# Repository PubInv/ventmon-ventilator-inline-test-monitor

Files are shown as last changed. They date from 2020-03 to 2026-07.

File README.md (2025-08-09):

# VentMon T0.5
The VentMon is an OSHWA certified open source hardware, [US002353](https://certification.oshwa.org/us002353.html)

OSHWA_VENTMON

# VentMon T0.5



Note: The previous version, the VentMon T0.3, has been published in [HardwareX](https://www.sciencedirect.com/science/article/pii/S2468067221000249) with extensive build instructions.



The VentMon T0.5 was roughly designed in June of 2021. This version is self-contained---that is, it will not require a separate computer and internet access.
The inventor team has been especially motivated by the work of Mr. Joe Leier, who repaired ventilators in Guatemala during the pandemic.  Public Invention aims to create a self-contained unit that allows the user to test and repair it in the field.  The device will, however, still be WiFi enabled, and still publish data to a the public data lake.

For now, our ideas and work are published in the directory called [pi](https://github.com/PubInv/ventmon-ventilator-inline-test-monitor/tree/master/pi).

## Configuring the VentMon T0.5 for WiFi

The VentMon is fundamentally a WiFi enabled device which publishes to a public data lake which can be found here:

[\http://ventmon.coslabs.com/rds](http://ventmon.coslabs.com/rds)

In order to configure it, the password and name of the local WiFi networkmust be added via the serial port. To do this, you have to connect to the serial port on the VenMon with a USB cable with a serial monitor. the Arduino IDE has such a serial monitor, but you could use any serial monitor. Then 
simply type the letter "c" and enter to configure the VentMon. Read and follow the instructions to reset and enable or disable the WiFi network.

The Configuration menu may look like this:
```
16:00:17.486 -> Enter 'c' to re-enter this configuration while running.
16:00:17.486 -> WiFi ENABLED
16:00:17.486 -> Enter 'w' to enable WiFi, 'x' to disable WiFi
16:00:17.486 -> Ethernet ENABLED
16:00:17.486 -> Enter 'e' to enable Ethernet, 'f' to disable Ethernet.
16:00:17.486 -> Type the character 'r' to reset wifi ssid and password.
16:00:17.486 -> Type the character 'c' to continue or wait 10 seconds to begin/resume operation:
```

Once you have condifugred it for your local WiFi and verified that you are seeing love traces at the URL above (your trace will likely be near the top, and reflects your loack IP address) then you can power the VentMon which a USB cable which is not monitored by a computer.

# Previous Version VentMon T0.4 - Inline Ventilator Test Fixture and Monitor

March 9th, 2021

VentMonT0 4

The photo above shows the current version of the VentMon, the T0.4 tester/monitor, designed and manufactured by Ben Coombs. We are giving these away free of charge to worthy open source teams.

The VentMon T0.4 improves on the T0.3 because it is self-contained (no cables) and is quite compact. We have also improved the OLED display, although additional firmware changes are coming soon.

The software infrastructure that supports the VentMon, such as [VentDisplay](https://github.com/PubInv/vent-display) and [PIRDS](https://github.com/PubInv/PIRDS-respiration-data-standard), have improved as well.

The VentMon is basically a cloud-enabled spirometer with an FiO2 sensor. When plugged into a standard 22mm airway, the device provides
a rich stream of pressure and flow, with oxygen, humidity, and temperature sensors for continual monitoring.  Engineering teams developing pandemic response ventilators and other respiration tools are the primary users of the VentMon. Additionally, it is completely and transparently open source, so any team can adopt the design and incorporate it into their own devices to provide the same data in an integrated way.

The parts in a VentMon cost about USD$600. 

# Usage

## Basics

The VentMon T0.4 can be powered with any micro-USB cable. It has an RJ45 ethernet port, and supports WiFi.  It has a male airway connector and 
a female airway connector in the international standard 22mm adult airway sizes. It comes with an oxygen sensor, which you may have to install
by opening the case. It is not pre-installed because the oxygen sensors have a limited shelf life and some users don't need one. The case can 
be opened with a small jeweler's Phillips head screwdriver.

The VentMon has a small OLED display which gives some startup information and also shows momentary flow and pressure while producing a tiny 
graph of airway pressure. This is not intended for clinical use, but it is useful for letting you know that the device is on and working.

## The Serial Port

The main target for the VentMon project is to support engineers who are working on ventilators and respiration support devices. Most of these engineers will know
how to use the Arudino IDE to see the serial port. The baudrate is 500000 (500,000).
A simple human-readable output is printed to the serial port at start up time, which
shows some basic start up information.  After searching for an ethernet connection and WiFi connection, the VentMon will
begin printing dynamic data on the serial port. 
The output is in the [PIRDS data format](https://github.com/PubInv/PIRDS-respiration-data-standard). 
This is useful for verifying that the device is functionally and correctly working.
It is not a good way to analyze data, but you can tell a lot by reviewing this data stream.  However, the preferred way to look at moving interactive waveforms and clinical paramaters is with [VentDisplay](https://github.com/PubInv/vent-display), which requires some configuration.

## Configuring a UDP conncetion

The easiest way to use VentDisplay is to check out our public IoT Data Lake at [http://ventmon.coslabs.com/](http://ventmon.coslabs.com/). 
We name your log file by your IP address. The webpage there looks like this:

These files are sorted by modification timestamp, so if you use one of the methods to place your data there, it will likely be near the top!
The "BreathPlot" links take you to the VentDisplay for that log file, whether it is is static or "live" (that is, being dynamically added to from a
running VentMon.)

By entering a "c" character followed by a newline (probably in the Arduino IDE serial monitor tool), the VentMon will stop sending data 
to the serial port and write out a small menu of instructions. You can follow these instructions to enable or disable either the ethernet
connection, the WiFi connection, or both.  This menu allows you to enter your SSID for your WiFi network and your password, which will be
stored in the EEPROM of the device.

If you choose to use the Ethernet connection, you will probably plug an ethernet CAT5 cable directly into your router and the port on the VentMon.

Both Ethernet and WiFi attempt to send UDP packets to port 6111 at ventmon.coslabs.com.  There our [PIRDS-logger](https://github.com/PubInv/PIRDS-logger)
connection automatically timestamps and logs your UDP packets, and allows them to render for your viewing and analysis pleasure.

## Configuration

Configuring a VentMon T0.4 is a little complicated because we are developing a modular, composable, respiratory ecosystem. The diagrams below try to capture three distinct approaches: using our public data lake (easiest), using Apache (requires understanding httpd.conf and fully understanding all pieces), and a Docker Image (we have not actually created this, but we plan to).

Public Data Lake:

VentMon Cloud Ecosystem

Using Apache:

VentMon Apache Ecosystem

Public Invention recently created a repo that builds a Docker file image that makes all of this possible locally without running Apache/CGI.
Please visit [PIRDS-docker-local](https://github.com/PubInv/PIRDS-docker-local) for more details. As of March 25th, the Docker system is working 
on one computer (the authors), and another user has reported a problem with it; this is in an early release stage.

VentMon Docker Ecosystem

## Compiling and updating the Firmware

If you have received a VentMon from us,
it will have VentMonFirmware.ino installed.
The VentMon firmware is a work in progress, and we are making active improvements.
Therefore, you may want to update it from time to time. This requires you to build it with the Arduino IDE on your system.
You are welcome to modify the VentMonFirmware.ino file as needed. To do so, you will
have to install a library of our creation which encpasulates the PIRDS standard.
Copy the libary [pirds_library](https://github.com/PubInv/PIRDS-respiration-data-standard/tree/master/pirds_library) into your Arduino library location. You may need to install the Adafruit BME680 library
and other libraries as well.

Additionally, to compile the version of the firmware, you will need to install the [SFM3X00 library](https://github.com/PubInv/SFM3X00). We wrote this library to encapsulate Sensirion flow sensors of various kinds.

This process is a little clunky; please contact us if you need help with that.

# VentMon 0.3

Note: The important file "breath_plot.html" which renders respiration traces and calculated values from PIRDS 
data was moved to its own [repo](https://github.com/PubInv/vent-display) on Thursday, June 18, 2020.

Since March 16th, I've been working full time on this. Along with volunteers at [EndCornaVirus.org](https://www.endcoronavirus.org/) and [Public Invention](https:\\www.pubinv.org), we have been
[tracking and analyzing](https://github.com/PubInv/covid19-vent-list)
all [open-source ventilator projects]((https://medium.com/@RobertLeeRead/analysis-of-open-source-covid-19-pandemic-ventilator-projects-27acf9075f7e)) we can find. It has become apparent that the biggest piece
they are missing, and the area where Public Invention can most help, is not in designing a new ventilator. Instead, our priority is to build a test/monitoring fixture to assist other teams.

Monitoring and testing are critical for keeping patients alive, and thus we are attempting to
make a combined tester/monitor.

At the moment, this repo is to that end. Our overall strategic plan will give clinicians
enough confidence to actually deploy an open-source ventilator. Our goal is to certify ventilators in a limited, last-resort
sense, in case of a shortfall of commercial and professional equipment. That strategy is discussed later in this document.

Our current process includes rapid high-quality, but also burn-in and multi-day, testing of
ventilators. Perhaps we can produce a benchmark for the [multiple efforts](https://github.com/PubInv/covid19-vent-list) going on right now to develop a
Free-libre Open Source ventilator design.

For further explanation of Public Invetion's design motivation and approach for this project, please refer to the following document -
[Motivation of Strategy](https://github.com/PubInv/ventmon-ventilator-inline-test-monitor/blob/master/Motivation.md)

For a hands on demonstration and in-depth explanation of VentMon, watch our screen cast!  
[VentMon ScreenCast](https://www.youtube.com/watch?v=OV9MrMjVOCI)

# User Manual

Although a work in progress, we have a [user manaul v0.3T](https://github.com/PubInv/ventmon-ventilator-inline-test-monitor/blob/master/doc/UserManaul.md).
This User Manual is basically for the VentMon.

## Design and Dependencies

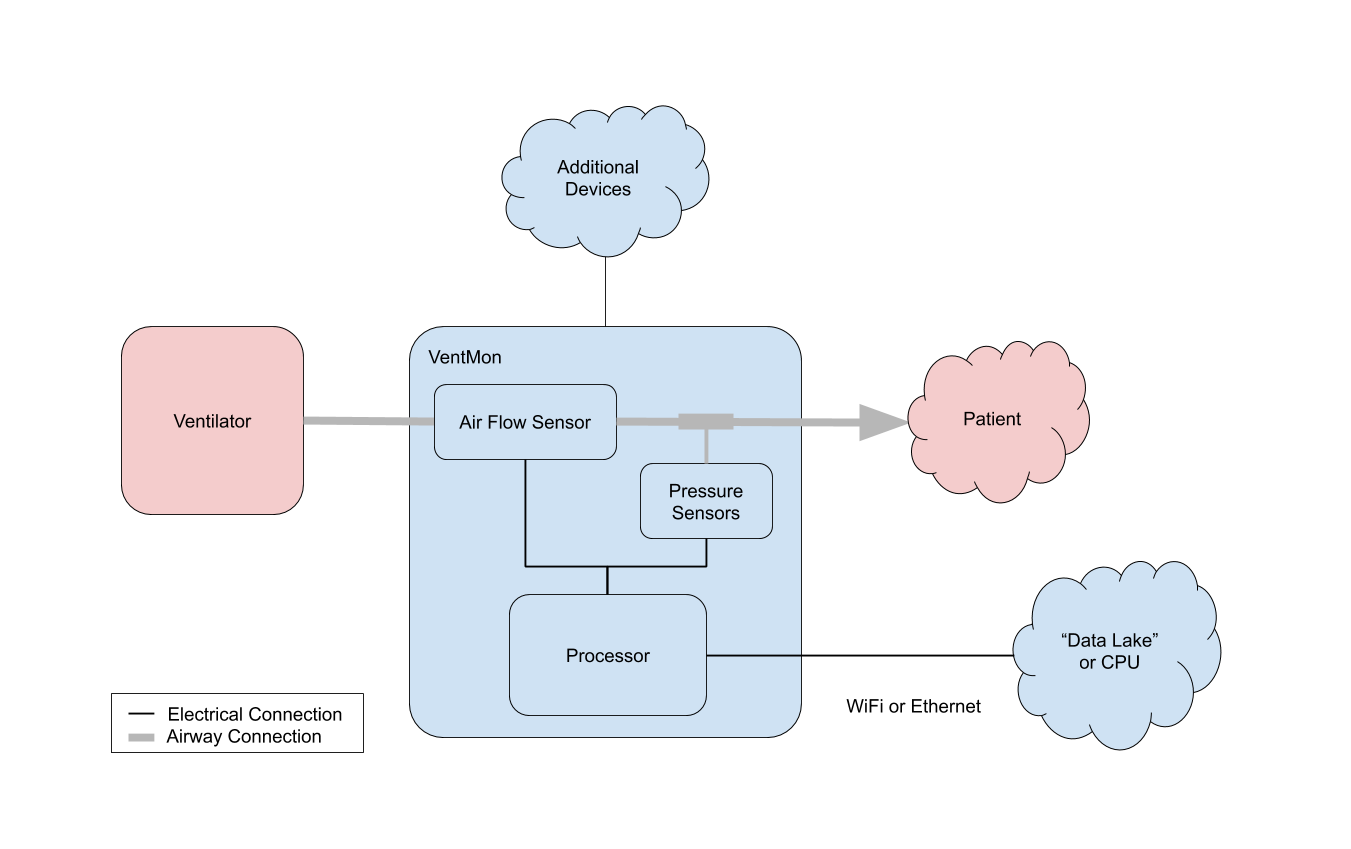
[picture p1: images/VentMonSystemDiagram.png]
SystemDiagram


This project aims to design a standalone inline device plugged into the airway. It will serve the dual purpose of both monitor and alarm when used on an actual patient, and these tests may also produce prototype ventilators that allow for burns.

VentMon depends on the following Arduino library for communication with Sensirion flow sensors: [SFM3X00](https://github.com/PubInv/SFM3x00)

Assembly instructions can be found here: [Assembly Instructions](https://docs.google.com/document/d/1n-Ja3UgbrCLcY8kx9rmTZB7b3yNJ_DnjpA1hwfMbgXk/edit#)

Initial BOM can be found here: [BOM](https://docs.google.com/document/d/1n-Ja3UgbrCLcY8kx9rmTZB7b3yNJ_DnjpA1hwfMbgXk/edit#)

## Status

** October 10th **

We have now shipped 20 units of the VentMons to open source teams all over the world. Some of them are
using them successfully. We ordered 15 printed circuit boards and 15 3D printed sensor ports, and I built them
by hand. There was an error in the PCBs which is now corrected; I fixed the current them by 
soldering a wire in place. The current design of the case does not perform cable management as well as it should; 
the flow meter cable tends to fall out. We will improve this in future designs.

** August 20th **

We have received 15 populated boards and desigend a 3D printed hat. We are beginning final assembly/manufacture of the 15 units that people have requested to be sent out free-of-charge.

** June 18th ***

Lauria plans to ship 5 more VentMons on the 23rd. She has added FiO2 sensing and important features. Rob Giseburt has create a VentMon-like device using a Raspberry PI; we may switch to that display. The VentMon was used internationally by several teams to gain important insights into their prototype pandemic ventilators. One team may be constructiong their own VentMon from our Open Source designs.

** May 25th **

We have now shipped 4 VentMons. Most recent modifications involved using the "pirds_library" more universally.

** May 7th **

We sent the first VentMon to Artemio Mendoza of the 1MillionVents team, and he made this great video:

VentMon testing an A.R.M.E.E. Device (https://youtu.be/nViBK8d_pbM)

**May 4th:**

May the Fourth be with you.

We have shipped two VentMons free of charge to an open source ventilators' team that will use them for volume and flow measurements.

A [user manaul](https://github.com/PubInv/ventmon-ventilator-inline-test-monitor/blob/master/doc/UserManaul.md) is progressing.

**April 27th:**

Assembly instructions can be found here: [Assembly Instructions](https://docs.google.com/document/d/1n-Ja3UgbrCLcY8kx9rmTZB7b3yNJ_DnjpA1hwfMbgXk/edit#)

**April 21st:**

Initial prototype is fully assembled!

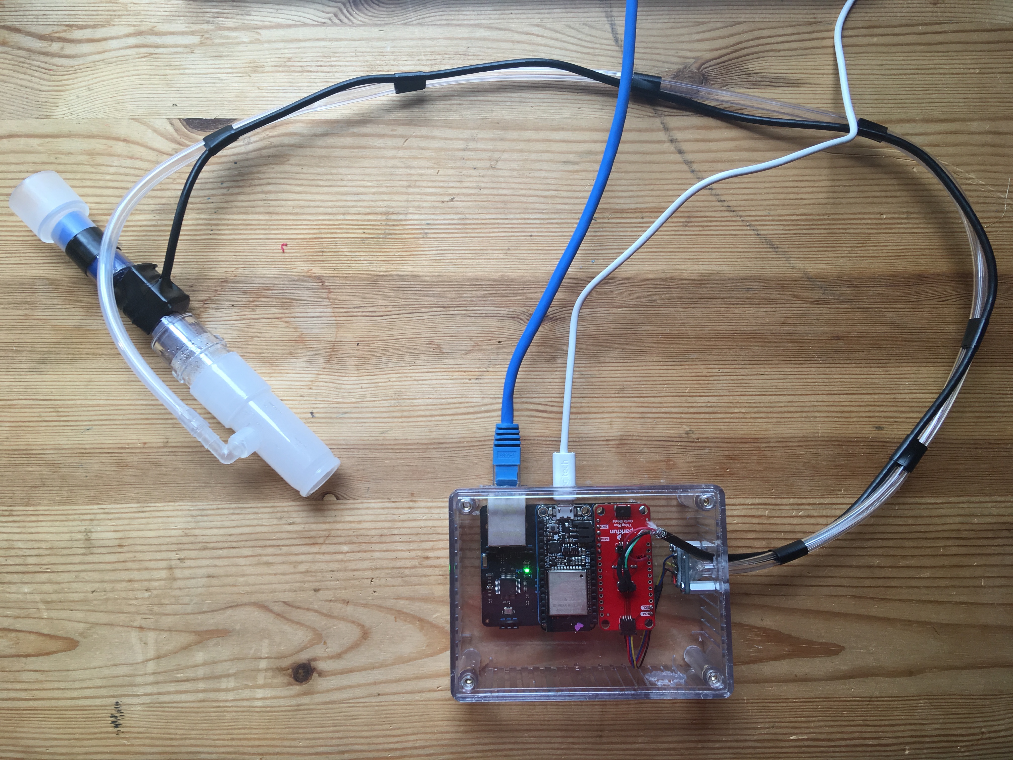
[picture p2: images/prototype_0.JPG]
Prototype


**April 20th:**

1) Have a working ESP32 board with pressure sensors and Sensirion flow sensors.
2) This code outputs a stream of PIRDS respiratory standard events on the serial port.
3) These are read by data_server.py which presents a web server for retrieving this data.
4) test_tools/breath_plot.html makes AJAX calls to this server and renders the results dynamically.

## Volunteering

This project is co-led by Robert L. Read <read.robert@gmail.com> and Geoff Mulligan.

Right now we have several needs. People need experience, to have read the [essential reading](https://github.com/PubInv/covid19-vent-list) list, and to have
least 20 hours a week to work with limited supervision.  They must also have the ability to tolerate the chaos
produced by the pandemic and my own mistakes. Finally, they must accept and
hope that the industry will increase ventilation production, and that the disease will be controlled so that this
solution is no longer required.

Right now, we could use:
1. An experienced Arduino engineer to build and improve the design below
1. A JavaScript programmer to add the ability to scroll-through all time to [https://github.com/PubInv/vent-diplay](vent-display) code.
1. Someone to design the User Interface of the "monitor and alarm" feature. They would have to be or become familiar with existing ventilators make a similar interface. This will likely become a small LCD or OLED text screen, 4 physical buttons, and a small speaker or buzzer.

# Request for Donations to Public Invention

[Public Invention](https://www.pubinv.org/) is a small, all-volunteer 501(c)3 US public charity. Your [small donation](https://www.pubinv.org/donate/) is a stamp of approval for our work and will really help us.

# Licensing

All code in this repo is licensed under the GPL License. All documents and diagrams are licensed under CC0. All hardware is licensed under the [CERN Open Hardware Licences Version 2 - Strongly Reciprocal](https://ohwr.org/cern_ohl_s_v2.pdf).

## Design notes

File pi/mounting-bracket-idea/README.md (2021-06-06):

# Mounting Bracket ID

The VentMon T0.4 case is just a little too large to mount behind the Element 14
Raspberry PI 7" TFT screen. However, that screen, and many others, has a
VESA-D 75mm mount on the back. I propose that we make a flat bracket that
mounts to this with the standard M4 screws, with a projection large enough
for us to zip-tie a VentMon T0.4 to it.

We may change the case for the T0.5; but in any case this system allows
the VentMon device to be easily separated from the Touch screen.

Our goal is to produce a maximally modular system; if you can use
a VentMon without the larger screen if you want.  If we were selling
devices (which we are not), the two components would be "sold separately".
Instead, they are "designed separately", and a manufacturer may make
and sell one or both.

The motivation of this is in particular to go to a hospital in LMIC
that might have broken ventilators and to be able to quickly assess,
test, and repair the ventilators (with the help of a plastic test lung,
not produced by us.)

Note: The mockup below is a WIP -- there may be better approaches. I'm publishing it here for comment.

## Basic Parts

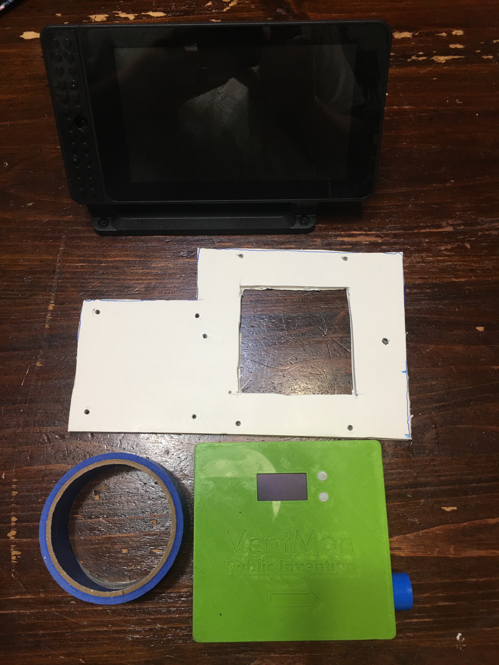
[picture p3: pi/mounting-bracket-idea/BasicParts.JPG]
Basic Parts


## Bracket as Bezel

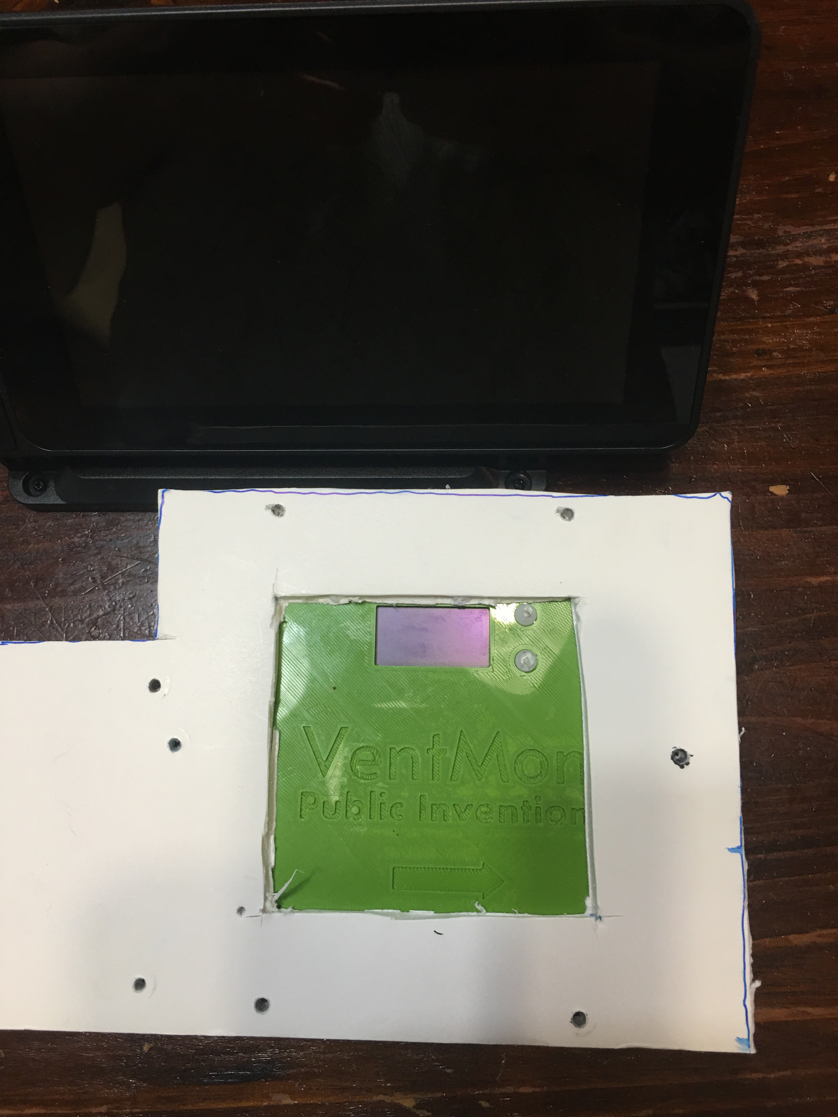
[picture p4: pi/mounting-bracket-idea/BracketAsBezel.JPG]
Bracket as Bezel


## Screen Rear (VESA Mis-D 75mm mount)

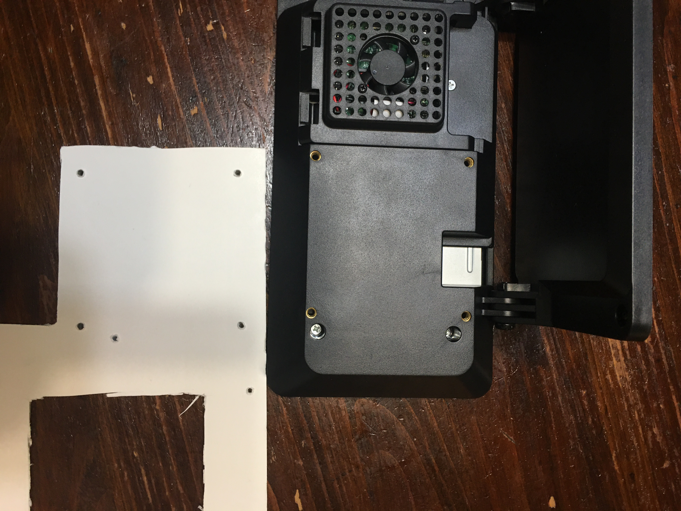
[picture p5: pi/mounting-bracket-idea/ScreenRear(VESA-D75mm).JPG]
Screen Rear VESA MIS-D 75mm Mount


## Final Configuration Mockup

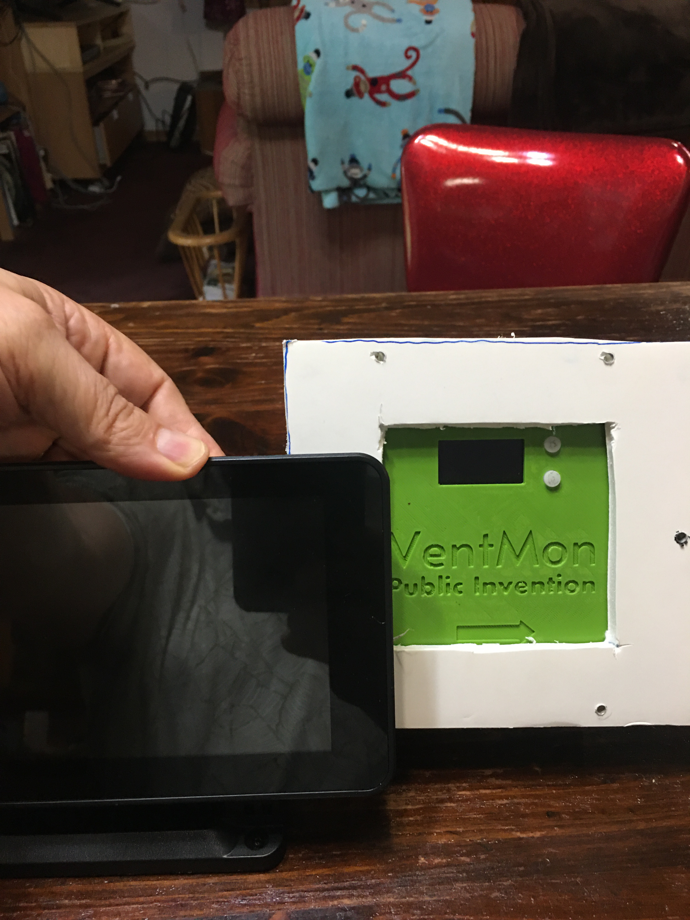
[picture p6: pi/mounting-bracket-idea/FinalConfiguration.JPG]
Final Configuration Mockup


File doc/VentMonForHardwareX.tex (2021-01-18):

% GENERAL INFORMATION: HardwareX is an open access journal established to promote free and open source designing, building and customizing of scientific infrastructure (hardware). For more details on best practices for sharing open hardware see http://www.oshwa.org/sharing-best-practices/

\documentclass[11pt, letterpaper]{article}
\usepackage[utf8]{inputenc}
\usepackage[margin=1in]{geometry}
\usepackage{titlesec}
\usepackage{tabu}
\usepackage{enumitem}
\usepackage{amssymb}
\usepackage{graphicx}
\usepackage{float}
\newlist{selectlist}{itemize}{2}
\setlist[selectlist]{label=$\square$,leftmargin=*,noitemsep,topsep=0pt}

\usepackage{hyperref}
\hypersetup{
    colorlinks=true,
    linkcolor=blue,
    filecolor=magenta,
    urlcolor=cyan,
}

\usepackage[backend=biber]{biblatex}
\addbibresource{VentMon.bib}

\urlstyle{same}

% Set up the section label formatting
\titleformat{\section}[block]{\hspace{1em}\bfseries}{\thesection.}{0.5em}{}
\titleformat{\subsection}[block]{\hspace{1em}}{\thesubsection}{0.5em}{}

\begin{document}
% Create the title block
\begin{flushleft}

% Remove all text in italics when filling out the template and replace with your manuscripts corresponding text in regular font.

\setlength{\parindent}{0pt}
\setlength{\parskip}{10pt}
% \textbf{\large HardwareX article template}

%Insert title
%Max. 20 words. A good title should contain the fewest possible words that adequately describe the content of a paper.
\textbf{Title:} VentMon: An Open Source Inline Ventilator Tester and Monitor

%Insert Authors
\textbf{Authors:} Robert L. Read, Lauria Clarke, Geoff Mulligan

%Insert Affiliations
\textbf{Affiliations:} Public Invention with support from the \textit{Protocol Labs} and the \textit{Mozilla Foundation}

%Insert Contact Email
%Include institutional email address of the corresponding author
\textbf{Contact email:} read.robert@gmail.com

%Insert Abstract
%Max. 200 words. Remember that the abstract is what readers see first in electronic abstracting and indexing services. This is the advertisement of your article. Make it interesting, and easy to be understood. Be accurate and specific, keep it as brief as possible.
\textbf{Abstract:}

Humanitarian engineers responded to the pandemic ventilator shortage of March, 2020
by beginning over 100 open source ventilator projects\cite{COVID19VENTLIST,pearce2020review}.
By {\em ventilator}, we mean both an invasive ventilator (requiring intubation of the patient) and non-invasive ventilator (generally supporting spontaneously breathing).
Inexpensive ventilator test equipment can facilitate projects forced to be geographically distributed by lockdowns.
The VentMon is a modular, open source, IoT-enabled tester that plugs into a standard 22mm airway between a ventilator and a physical test lung to test any ventilator.
The VentMon measures flow, pressure, fractional oxygen, humidity, and temperature.
Data is stored and graphed at a data lake accessible to all devlopment team members, and, eventually, clinicians.
The open source design of the VentMon,
its firmware, and cloud-based software may allow it to be used as a component of modular ventilators to provide a clinical readout.
The software system surrounding VentMon has been designed to be as modular and composable as possible.
By combining new, openly published standards for data with composable and modifiable hardware,
the VentMon forms the beginning of an open system or eco-system of ventilation devices and data.
Thanks to grants, 20 VentMons have been given away free of charge to pandemic response teams building open source ventilators.

%Insert Keywords
% At least 3 keywords. There is no limit on the no. of keywords you can list. Please remember that effective keywords should not repeat words appearing in your title, and should be neither too general nor too narrow.
\textbf{Keywords:} COVID-19, open source medical device, ventilator, pandemic response, IoT, respiration waveform

\newpage
\textbf{Specifications table:}

\tabulinesep=1ex
\begin{tabu} to \linewidth {|X|X[3,l]|}
\hline  \textbf{Hardware name} &
  %Please specify the name of the hardware that you invented / customized
  VentMon
  \\
  \hline \textbf{Subject area} & %
  % Please state the subject area most relevant to the original community for which this hardware was developed. Example subject areas are listed below
 Educational Tools and Open Source Alternatives to Existing Infrastructure
  \\
  \hline \textbf{Hardware type} &
Field measurements and sensors,
Electrical engineering and computer science
  \\
\hline \textbf{Open source license} &
  %Please specify the open source license. For more details see the guide to authors.
 MIT License, CERN-OHL-S
  \\
\hline \textbf{Cost of hardware} &
  %Approximate cost of hardware (complete breakdown will be included in the Bill of Materials).
\$280
  \\
  \hline \textbf{Source file repository} &

  VentMon: \linebreak
  \href{https://doi.org/10.5281/zenodo.4079170}{https://doi.org/10.5281/zenodo.4079170}
  \linebreak
  PIRDS (Public Invention Respiration Data Standard): \linebreak
  \href{http://doi.org/10.5281/zenodo.4079377}{http://doi.org/10.5281/zenodo.4079377}
  \linebreak
  PIRDS logger: \linebreak
  \href{Zenodo. http://doi.org/10.5281/zenodo.4079382}{Zenodo. http://doi.org/10.5281/zenodo.4079382}
  \linebreak
  SFM3X00: \linebreak
  \href{http://doi.org/10.5281/zenodo.4079355}{http://doi.org/10.5281/zenodo.4079355} \linebreak
  VentDisplay: \linebreak
  \href{http://doi.org/10.5281/zenodo.4079374}{http://doi.org/10.5281/zenodo.4079374} \linebreak
  \linebreak

  % Link to the source file repository
      % insert a DOI URL to an approved source file repository:  Mendeley Data, theOSF, or Zenodo (instructions).  For example: "https://doi.org/10.5281/zenodo.3346799"
      % If there is no external repository write “Available in the article”
  %% \textit{DOI URL to an approved source file repository:  \href{https://data.mendeley.com/}{Mendeley Data}, the \href{http://osf.io}{OSF}, or \href{https://zenodo.org/}{Zenodo} \href{https://doi.org/10.5281/zenodo.3346799}{(instructions)}. For example:} \textit{https://doi.org/10.5281/zenodo.3346799}
%  \linebreak
%  \linebreak
\\\hline
\end{tabu}
\end{flushleft}
% create the main body of the paper

\section{Hardware in context}
% Include a short description of the hardware, putting into context of similar open hardware and proprietary equipment in the field.
The Coronavirus pandemic has created a potential global shortage of ventilators\cite{pearce2020review}, which has abated in the wealthy nations.
Ventilators are expensive to manufacture and during uncertain times supply chains can be disrupted, increasing the cost and scarcity of these devices. Since the beginning of the pandemic in March,
there has been a large movement to develop cheaper,
more supply chain-resilient ventilators.
The urgency and goals of this movement have shifted as the global understanding of the virus has evolved. Regardless of the current state of this movement, however, the use of
open source medical devices in resource-limited emergency situations---common during a global pandemic---is a topic that has come to the forefront of may conversations about preparedness and treatment.
Medical devices require rigorous testing before they can be used on the general public.
Open source medical devices require the same level, if not more, scrutiny and documentation. If an open source movement is to succeed in this field, the tools to test and validate medical
devices must be accessible.
The goal of VentMon is to provide an equally open source, community based verification solution to increase the efficiency and accuracy of the development process for socially distanced,
potentially international teams making open source ventilator, Bilevel Positive Airway Pressure (BPAP), and Powered Air-Purifying Respirator (PAPR) devices.

Although it is beyond the scope of this paper to review or even comment on ventilation projects, a number of pandemic response ventilators have been reported on recently which seem to be candidates to benefit from the VentMon, if only because of its flow-sensing and oxygen sensing capabilities (most have pressure sensors in place) \cite{lai2020emergency,petsiuk2020partially,garmendia2020low,zuckerberg2020lung,galbiati2020mechanical}. Although most published reports include bench-top testing, this may have been done with an instrumented test lung which is not continuously available to the development teams as a VentMon might be. Additionally, most of the teams mentioned in a report on open source teams\cite{Fraunhofer2020} could make use of a VentMon.

\section{Hardware description}
% Describe the hardware, highlighting the customization rather than the steps of the procedure. Highlight how it differs/which advantage it offers over pre-existing methods. For example, how could this hardware: be compared to other hardware in terms of cost or ease of use, be used in the development of further designs in a particular area, and so on.

% > Add 3-5 bulleted points to broadly explain to other researchers how the hardware could be potentially useful to them, for either standard or novel laboratory tasks, inside or outside of the original user community.

The VentMon plugs directly into a standard 22mm adult airway. As air or medical gases pass through the VentMon, it records flow and pressure, temperature, humidity, and fractional O$_2$ at rates of 25 Hz to once per minute, depending on the measurement. When placed in the breathing circuit between a ventilator under test and a physical test lung as shown in Figure \ref{fig:vtestusage}, this data is sent to a public data lake \cite{VentDisplay} using a clearly defined respiration standard \cite{PIRDS}. This data can be graphically rendered either live or statically to provide a display that is typical of the clinical display of advanced ventilators as shown in Figures \ref{fig:vtestusage} and \ref{fig:ventdisplay}. This functionality is similar to that of commercially available instrumented test lung devices, which tend to start at USD\$10,000.

Teams building open pandemic ventilators tend to be poorly funded and geographically distributed. VentMon's connectivity and overall cost address these two challenges by enabling team members on different continents to view waveforms (see Figure  \ref{fig:ventdisplay}) in real time and communicate the necessary adjustments to the ventilator device under test. While reliance on the internet is a strength for a distributed and virtually connected engineering team, it would be an addressable disadvantage in a field hospital.

Being completely open, VentMon supports modification, extension, and has potential for integration into a complete ventilator. A team working to build a ventilator device with a graphical trace of pressure and flow---generally demanded by clinicians for all but emergency transport situations---could incorporate the open source VentMon into its complete design. VentMon has potential to be safe enough and reliable to be used as a monitor on human patients, however it requires much improvement before it is ready for that use.
\\

The VentMon thus offers the following benefits to teams developing ventilation devices. It:
\begin{itemize}
\item is inexpensive,
\item is completely open source and part of a modular hardware/software system that can be customized and extended,
\item allows remote collaboration, and
\item currently provides many of the clinically significant metrics found in commercially available ventilators.
\end{itemize}

\section{Design files}
% The  complete  design  files  must  be  either  uploaded  to  an  approved  online  repository,  uploaded  at the  time  of  submission  on  the  online  Editorial  Manager  submission  interface  as  supplementary materials [CAD files, videos,. . . ], or included in the body of the manuscript [e.g.  figures].  The three approved  online  repositories  are  Mendeley  Data,  the  Open  Science  Framework,  and  Zenodo. See repository instructions: https://doi.org/10.5281/zenodo.3346799

\subsection{Design Files Summary}
% Please include a summary of all design files for your hardware by filling rows of the table below

\tabulinesep=1ex
\begin{tabu} to \linewidth {|X[1.5]|X|X[1.5,1]|X[3]|}
\hline
\textbf{Design filename} & \textbf{File type} & \textbf{Open source license} & \textbf{Location of the file} \\\hline
%Insert design files
(1) Embedded Firmware (v0.3 PCB version) & C++ Source Code & MIT License &  \href{https://doi.org/10.5281/zenodo.4079170}{10.5281/zenodo.4079170}\\\hline
(2) Embedded Firmware (v0.2 COTS version) & C++ Source Code & MIT License &  \href{https://doi.org/10.5281/zenodo.4291147}{10.5281/zenodo.4291147}\\\hline
(3) VentDisplay PIRDS Data Viewer  & HTML Source Code &  MIT License &  \href{http://doi.org/10.5281/zenodo.4079355}{10.5281/zenodo.4079374} \\\hline
(4) PIRDS Data Logger & C Source Files & MIT License & \href{https://doi.org/10.5281/zenodo.4079382}{10.5281/zenodo.4079382} \\\hline
(5) PIRDS Data Standard & Documented standard, and C-language binding & Creative Commons Zero (Universal) for documents, GPL 3.0 for code binding &
\href{http://doi.org/10.5281/zenodo.4079355}{10.5281/zenodo.4079355} \\\hline
(6) VentMon v0.3T PCB & PCB Design Files & MIT License &  \href{https://doi.org/10.5281/zenodo.4079170}{10.5281/zenodo.4079170} (see {\em design/pcb}) \\\hline
(7) Pressure Sensor and Airway Adaptor & STL File & MIT License &  \href{https://doi.org/10.5281/zenodo.4079170}{10.5281/zenodo.4079170} (see {\em design/3dparts}) \\\hline

% Design file 3 & File type & License & Link \\\hline

\end{tabu}
\vspace{0.5cm}

We promote an open, modular, and composable respiration ecosystem. Therefore, we have more separate repositories and modules than would strictly be needed if we were only making the VentMon project. Our hope is that smaller modules may be reusable by others who do not need the VentMon specifically, but may have need for a particular component.

\begin{enumerate}
\item The main firmware is written in the Arduino environment. The firmware targets an ESP32, but could easily apply to other boards. This core firmware manages reading the various sensors, and outputs its data both on its small built-in OLED (used for functional testing), and via the PIRDS standard to a public data lake where a separate module renders it in a graphical display appropriate for a clinician.
\item Our current focus is on a printed circuit board version of the VentMon\cite{ventmonpcb}. However, we also report here a system that can be made by an amateur using only commercial off-the-shelf (COTS) parts---version T0.2. Software that matches this version it is tagged as such.
\item VentMon has a tiny OLED screen which is used to graph pressure for quick ``smoke'' testing. For serious performance testing and eventual clinical use, we use VentDisplay, a browser-delivered JavaScript code that presents a full clinical display.
\item The VentDisplay software can be pointed at any data logger that serves up data in the PIRDS format. This logger takes data from UDP packets and writes them to a file, which can then be served up by a webserver to any requester.
\item Integral to the VentDisplay and PIRDS Data Logger is the Public Invention Respiration Data Standard (PIRDS). This is a documented standard.
\item The VentMon v0.3T printed circuit board is designed with EAGLE CAD.
\item A small 3D printed housing epoxied over the ambient air quality sensor with a tiny pressure port allows us to share the air with the main pressure hose.
\end{enumerate}

% For each design file listed in the summary above, include a short description of the file below (one or two sentences)

\section{Bill of materials}

% For a complex Bill of Materials, the complete Bill of Materials (editable spreadsheet file e.g., ODS file type or PDF file) can be uploaded in an open access online location such as the Open Science Frameworks repository. Include the link here. Alternatively, the Bill of Materials can be uploaded at the time of submission on the online Elsevier submission interface as supplementary material.

% > To make it easy to tell which item in the Bill of Materials corresponds to which component in your design file(s), use matching designators in both places, or otherwise explain the correspondence.

% > For material type, select from: Metal, semi-conductor, ceramic, polymer, biomaterial, organic, inorganic, composite, nanomaterial, semiconductor, non-specific, or other

The Bill of Materials specifies the parts needed to build the VentMon in a simple enclosure with drilled-out ports for cables.
The parts are typical of hobby electronics.

\tabulinesep=1ex
\begin{tabu} to \linewidth {|X[0.5]|X[3]|X[0.5]|X|X|X|X[3]|}
  \hline
\textbf{ Designator} &	\textbf{Component} & \textbf{Number} & \textbf{Cost/Unit} & \textbf{Total Cost}& \textbf{Source} & \textbf{Material Type} \\\hline
U1 &	PARTICLE ETHERNET FEATHERWING &	1 &	\$20.11 &	\$20.11  &	Adafruit &	Semiconductor/Other \\\hline
U2 &	HUZZAH32 ESP32 FEATHER MALE HDR	& 1 &	\$21.95	& \$21.95 &	Adafruit&	Semiconductor/Other \\\hline
U3 &	SPARKFUN QWIIC SHIELD FOR THING	& 1 &	\$3.50	& \$3.50 &	Digikey	& Semiconductor/Other \\\hline
U4 &	ADS1115 16 Bit ADC &	1&	\$14.95	& \$14.95 &	Adafruit	& Semiconductor/Other \\\hline
U5 &	OLED Feather Wing &	1&	\$14.95	& \$14.95 &	Adafruit &	Semiconductor/Other \\\hline
C1, C2 &	QWIIC CABLE - 200MM &	2 &	\$1.56 &	\$3.12 &	Digikey	& Metal/Plastic \\\hline
C3 &	USB Cable &	1 &	\$1.80 &	\$1.80	& Digikey &	Metal/Plastic \\\hline
C4 &	Oxygen Sensor Cable &	1 &	\$4.00 &	\$4.00 &	Oxycheq &	Metal/Plastic \\\hline
H1 &	M2.5 Screws &	12 &	\$0.38	& \$4.56 &	Digikey	& Metal \\\hline
H2 &	M2.5 Standoffs - Female, Female	& 6 &	\$0.45 &	\$2.70	& Digikey &	Metal \\\hline
OS1 &	R-17S Oxygen Sensor &	1 &	\$80.00 &	\$80.00	 & Oxycheq &	Metal/Plastic \\\hline
FS1 &	\textbf{Flow Sensor} &	1 & \textbf{see note below}	&	\$0.00	& &	Metal/Plastic \\\hline
PS1, PS2 &	BME680 SENSOR EVAL BOARD &	2 &	\$22.50 &	\$45.00	& Adafruit &	Semiconductor/Other \\\hline
P1 &	Processor Enclosure &	1 &	\$9.95 &	\$9.95 &	Digikey	 & Plastic \\\hline
P2 &	Bleed Adaptor	& 1 &	\$5.50 &	\$5.50 &	Oxygen Supply	& Plastic \\\hline
P3 &	Oxygen Sensor T	& 1 &	\$9.00 &	\$9.00	& Oxycheq &	Plastic \\\hline
P4 &	15 mm OD to 22 mm OD adaptor &	1 &	\$0.54 & 	\$0.54	& &	Plastic \\\hline
P5 &	15 mm ID to 22 mm OD adaptor &	1 &	\$0.35 & 	\$0.35	& &	Plastic \\\hline
T1 &	Oxygen Tubing &	1 &	\$2.25	& \$2.25 &	Oxygen Supply	& Plastic \\\hline
\end{tabu}

Note: The flow sensor is one of the most expensive and critical parts. Throughout mid-2020 there was a global shortage of flow sensors, including the four electrically compatible with the VentMon as currently designed. The Sensirion SFM3400-AW (\$180US) (a neonatal version with limited maximum flow sensing), SFM3200-33-D (disposable version \$40USD), Sensirion SFM3200-250 (\$145USD), and Sensirion SFM3200-AW (\$180USD autoclavable version). We shipped VentMons with all of these depending on availability. The VentMon is not currently designed for use with humans, but if it were, the autoclavable version would have the advantage of sanitizability if a complete sanitization procedure were designed. This is important, as we hope the VentMon will be modified and integrated into a rapidly manufactured ventilator, for which sanitization is critical.

The link below is to a spreadsheet which is includes the PCB-version, which is very similar except for the PCB itself. By following this link: \href{https://doi.org/10.5281/zenodo.4289426}{VentMon  BOM}, you can reach browsable URLs to most of the non-commodity parts. The specific BOM for the SMD parts needed to assemble the PCB can be found in our GitHub repo in the directory named {\em design/pcb}  along with the Eagle files: \cite{ventmonpcb}.

\section{Build instructions}
%Provide detailed, step by step instructions for the construction of the reported hardware include all necessary information for reproducing the submitted hardware.
% > Explain and, when possible, characterize design decisions. Including design alternatives if they exist.
% > Use visual instructions such as schematics, images, and videos.
% > Clearly reference design files and component parts described in the Design File Summary and Bill of Materials.
% >Highlight potential safety concerns that may arise

Two versions of VentMon can be assembled depending on availability of parts and time. The most physically robust and complete version of VentMon requires the purchase and manufacture of a PCB as well as a number of 3D printed plastic parts. This version of the device requires the least amount of time to assemble and contains fewest discrete components. The designs of the PCB and 3D printed parts are fully open. Due to the relatively high single-unit cost of PCB manufacture and assembly it makes most sense to use the PCB if you are building 10 or more VentMons. VentMon can also be created using off the shelf components readily available from DIY electronics suppliers. This version requires significantly more assembly time. We believe this has been done twice by third parties with little to no assistance from the VentMon team. Both assembly procedures are outlined below.

\subsection{COTS Based VentMon (v0.2T)}

{\em The VentMon v0.2T is not meant to be used on human patients. }
The COTS version uses firmware v0.2 tagged as such\cite{VentMon02}. This version is somewhat incompatible
with v0.3 (described below), which uses a PCB, and which is
the focus of our main development.

\begin{enumerate}

%-----------------------------------------------------------
% QWIIC SHIELD
\item
Qwiic Shield Assembly

See Figure \ref{fig:qwiic} on page \pageref{fig:qwiic} for final assembly of Qwiic Shield.

\begin{enumerate}[label=1.\arabic*]
\item
Trim two pieces of male header pins that are two positions long and one piece that is four positions long.
\item
With the connector side of the board facing up, solder one of the two position headers into the two holes labeled SDA and SCL.
\item
Solder the other two position header into the last two holes on the row along the opposite side.
\item
Solder the four position header into the last four holes along the right side. This should provide connections to the GND and 3V3 through holes.
\item
Connect both sides of the solder bridge to engage the pull-up resistors for the I\textsuperscript{2}C bus.
\end{enumerate}

\begin{figure}[H]
\centering
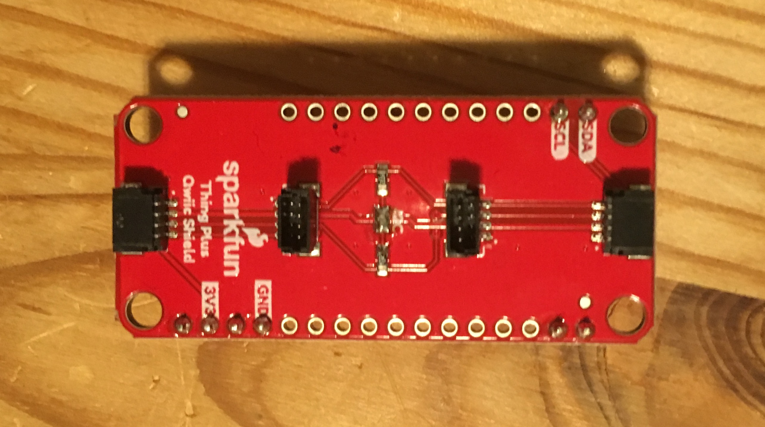
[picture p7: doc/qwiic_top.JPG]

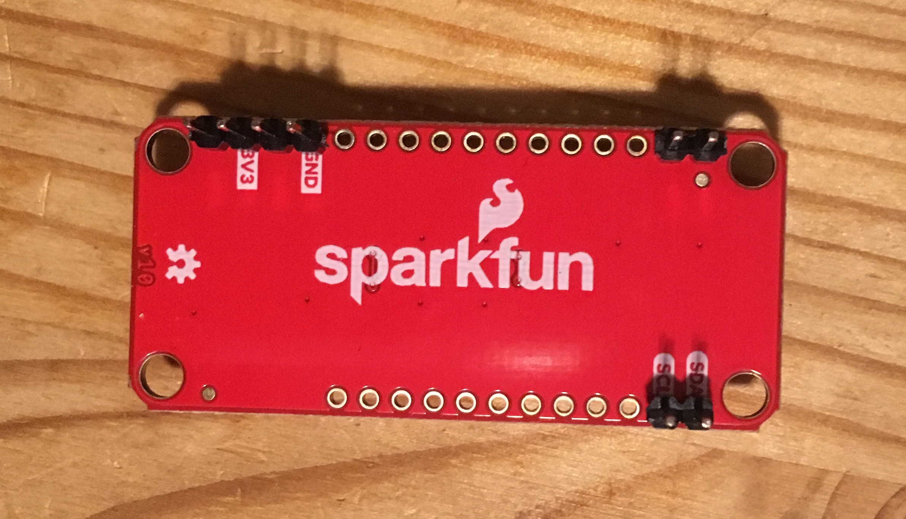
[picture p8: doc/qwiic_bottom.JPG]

\caption{SparkFun Qwiic Shield with male headers and I\textsuperscript{2}C pull-ups connected}
\label{fig:qwiic}
\end{figure}

%-----------------------------------------------------------
% ENCLOSURE
\item \label{itm:enclosure}
Enclosure

Before starting this step download and print the \href{https://github.com/PubInv/ventmon-ventilator-inline-test-monitor/blob/master/design/templates/bottomDrill03.pdf}{drill template}.

\begin{enumerate}[label=2.\arabic*]
\item
Cut out the template and tape it to the enclosure.
\item
Make sure the lid of the enclosure is firmly screwed on before drilling
\item
Drill holes in the locations denoted on template using the recommended drill sizes for each hole.
\end{enumerate}

%-----------------------------------------------------------
% PRESSURE SENSOR
\item
Pressure Sensor Assembly
\begin{enumerate}[label=3.\arabic*]
\item
Drill out mounting holes refer to figure \ref{fig:bme_1} on page \pageref{fig:bme_1}
\begin{enumerate}[label=3.1.\arabic*]
\item
Using the 7/64'' drill bit, carefully enlarge the mounting holes in each corner of the sensor
\item
You can do all four or just two - one on the left side of one board and one on the right side of the other
\end{enumerate}
\item
Cut trace from SDO through hole to sensor. Refer to figure \ref{fig:bme_1} on page \pageref{fig:bme_1}.
\begin{enumerate}[label=3.2.\arabic*]
\item
Carefully cut the trace coming from the SDO hole on the back side of one board
\item
This board will be used to measure the pressure in the breathing circuit
\end{enumerate}
\begin{figure}[H]
\label{fig:bme_1}
\centering
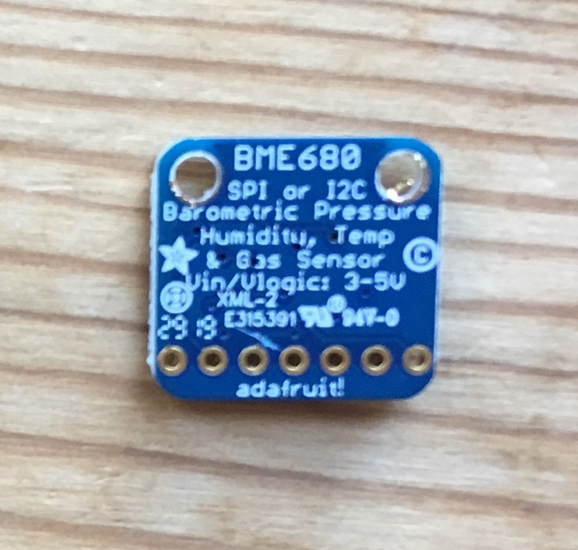
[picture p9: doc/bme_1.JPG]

\caption{BME 280 Eval board with drilled out holes and trace cut}
\end{figure}

\item
Assemble Cable. Refer to figure \ref{fig:bme_qwiic_cable} on page \pageref{fig:bme_qwiic_cable}.
\begin{enumerate}[label=3.3.\arabic*]
\item
Cut one connector off the Qwiic cable
\item
Strip and tin the last $1/4$" of the leads
\end{enumerate}
\begin{figure}[H]
\centering
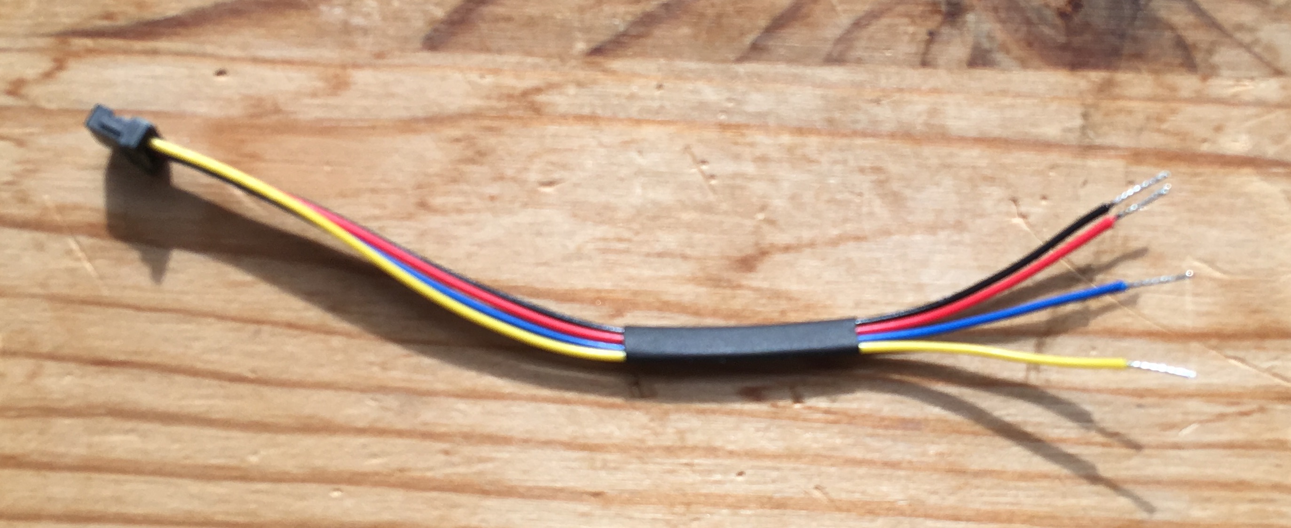
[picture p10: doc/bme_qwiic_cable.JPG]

\caption{Prepared Qwiic cable for BME sensor assembly}
\label{fig:bme_qwiic_cable}
\end{figure}
\item
Connect Sensors to Cable. Refer to figure \ref{fig:bme_and_qwiic_cable} on page \pageref{fig:bme_and_qwiic_cable} and table \ref{tab:pressure} on page \pageref{tab:pressure} for electrical connection.
\begin{enumerate}[label=3.4.\arabic*]
\item
Stack the two sensors on the breadboard and use two paper clips to anchor them
\item
Be sure the board with the cut trace is facing down
\item
Starting with Vin or GND insert the tinned lead through the appropriate hole and apply solder
\item
Flip the sensor assembly over and make sure solder has flowed through both through holes, adding some if needed
\item
Don't worry if the solder does not flow perfectly
\item
Pin the assembly back down and move to another connection following the connection table below
\item
Repeat the steps above until the two boards have been secured and all leads are connected
\item
Re-flow all the joints to ensure a good connection
\end{enumerate}

\begin{table}[H]
\centering
\begin{tabular}{| c | c |}
\hline
Signal & Qwiic Color\\  \hline
GND & black  \\  \hline
VIN & red \\  \hline
SDA & blue \\  \hline
SCL & yellow \\
\hline
\end{tabular}
\caption{pressure sensor wiring}
\label{tab:pressure}
\end{table}

\begin{figure}[H]
\label{fig:bme_and_qwiic_cable}
\centering
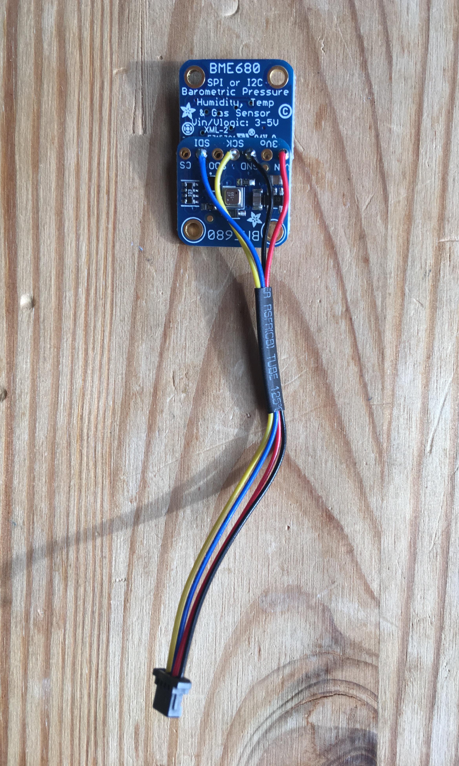
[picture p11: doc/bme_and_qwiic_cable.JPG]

\caption{Qwiic cable soldered to BME sensor assembly}
\end{figure}

\item
Add address jumper to ambient pressure sensor. Refer to figure \ref{fig:bme_diagram} on page \pageref{fig:bme_diagram}
\begin{enumerate}[label=3.5.\arabic*]
\item
Take a $1/2$" piece of hookup wire and strip both ends
\item
Flow the solder in the GND through hole and poke one end of the hook up wire into the hole
\item
Put the other end of the wire into the SDO through hole and apply solder
\end{enumerate}

\begin{figure}[H]
\centering
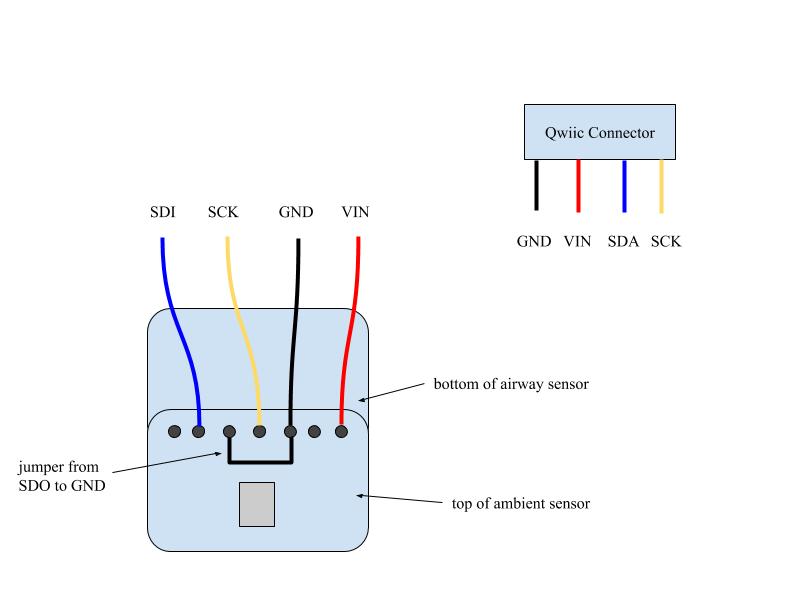
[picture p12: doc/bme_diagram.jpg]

\caption{Qwiic cable soldered to BME sensor assembly}
\label{fig:bme_diagram}
\end{figure}

\end{enumerate}

%-----------------------------------------------------------
% FLOW SENSOR
\item \label{itm:flow}
Flow Sensor Assembly

\begin{enumerate}[label=4.\arabic*]
\item
Assemble Cable. Refer to figure \ref{fig:flow_cable} on page \pageref{fig:flow_cable}

The flow sensor requires a 5 V input, however we will run the I$^2$C bus at 3.3 V necessitating this cable.
\\
\begin{enumerate}[label=4.1.\arabic*]
\item
Cut the Qwiic cable in half
\item
Cut off the red conductor near the base of the connector
\item
Cut a 30 cm length from the USB cable
\item
Strip the jacket back 1 $1/2$'' from one end
\item
Strip the first $1/4$'' of each conductor on one end and tin
\item
Twist a small portion of the shield into the black GND conductor
\item
Place a small piece of heat shrink on each conductor of the Qwicc cable and push them toward the connector end
\item
Solder the ends of the Qwiic cable to the ends of the USB cable following Table \ref{tab:flow}.
\begin{table}[H]
\centering
\begin{tabular}{| c | c | c |}
\hline
USB & Qwiic & Signal \\  \hline
black & black & GND \\  \hline
green & blue & SDA \\  \hline
white & yellow & SCK \\  \hline
red & single 6'' wire & 5V \\
\hline
\end{tabular}
\caption{flow sensor wiring}
\label{tab:flow}
\end{table}
\item
Connect the red wire to the red conductor in the USB cable and solder the extra long male header pin to the end
\item
Cover the finished joints with a short $1/4$'' piece of heat shrink
\end{enumerate}

\begin{figure}[H]
\centering
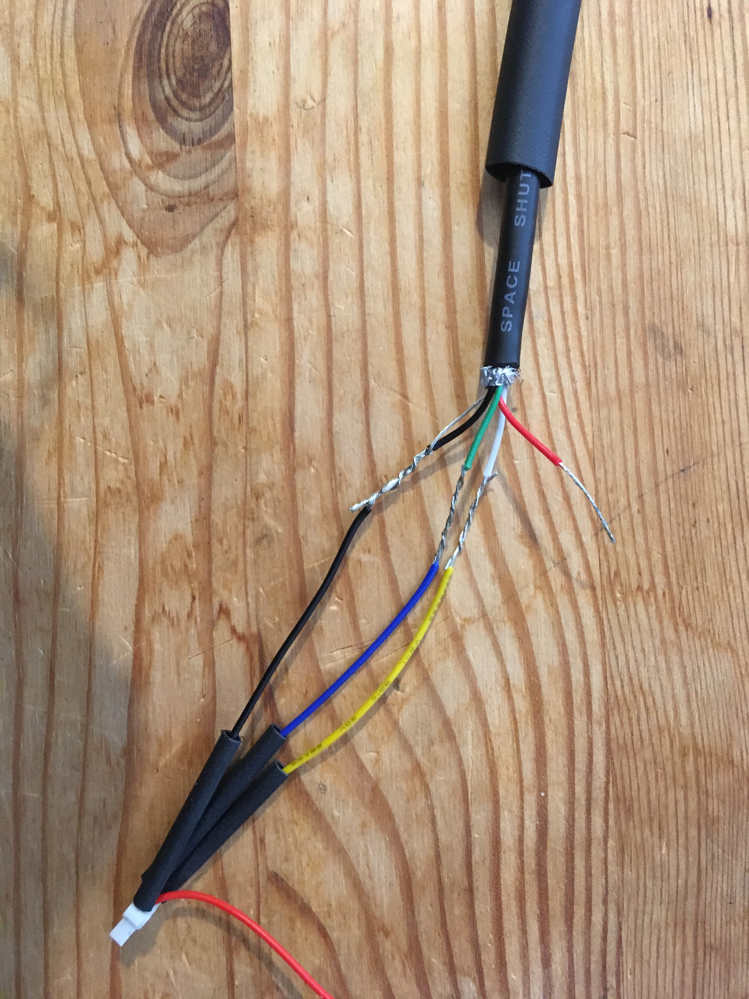
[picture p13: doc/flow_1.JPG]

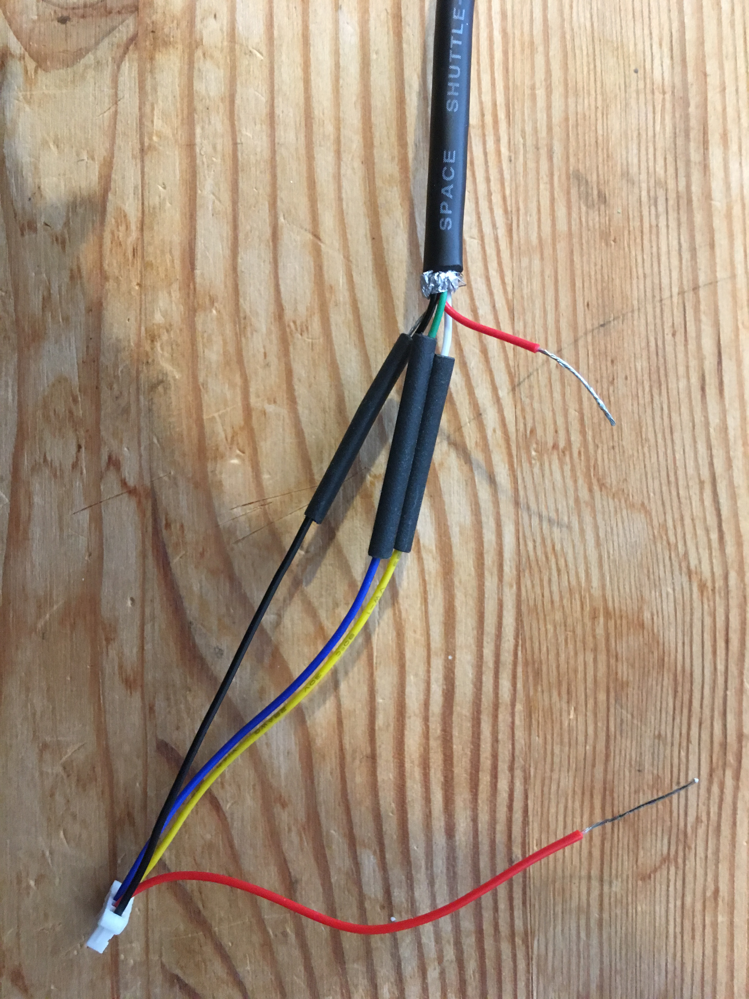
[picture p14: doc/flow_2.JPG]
 \\
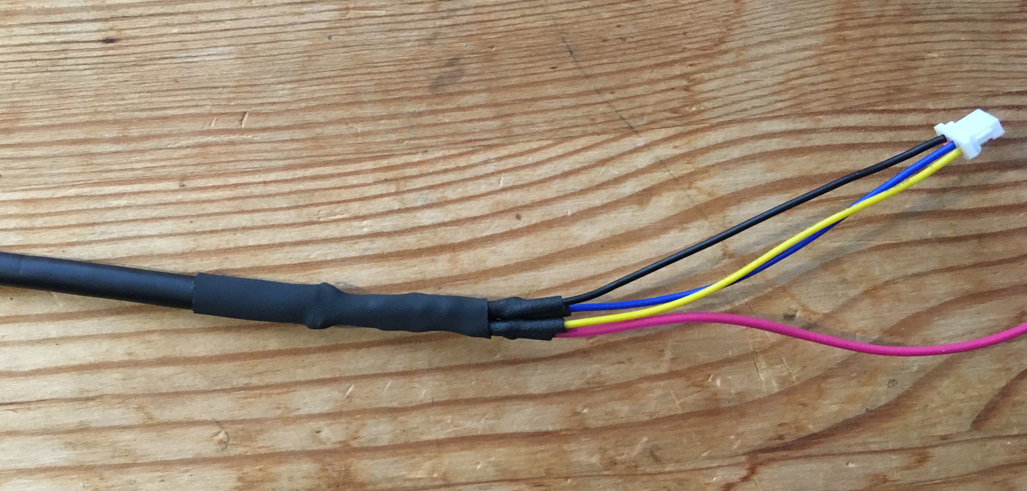
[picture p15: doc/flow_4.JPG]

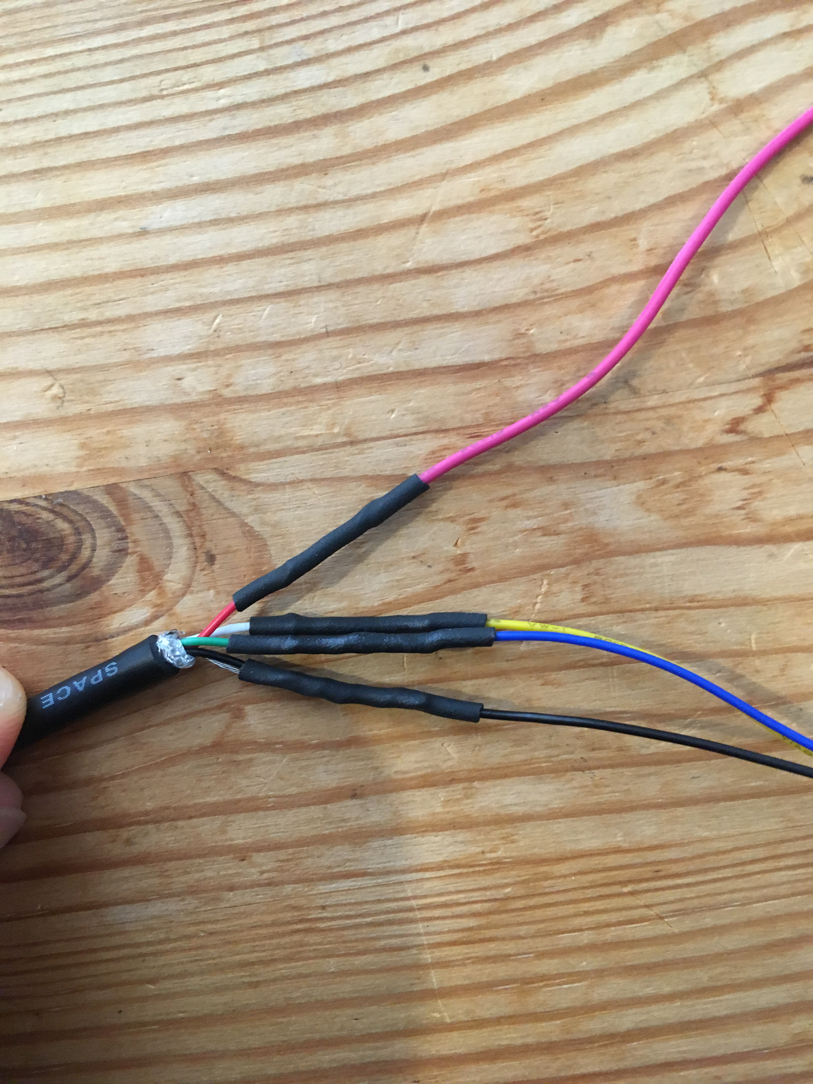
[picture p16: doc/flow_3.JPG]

\caption{Clockwise progression of sensor cable assembly.}
\label{fig:flow_cable}
\end{figure}

\item
Connect cable to sensor.  Refer to figure \ref{fig:flow_sensor} on page \pageref{fig:flow_sensor}.

\begin{enumerate}[label=4.2.\arabic*]
\item
Apply a small quantity of solder to the four center pads on the SFM3400 flow sensor
\item
Remove $5/8$'' of the jacket on the bare end of the USB cable
\item
Strip back $1/8$'' from each conductor and tin the ends
\item
Thread the cable through the hole in the sensor as shown in the photo and make sure the tinned leads can reach the sensor pads
\item
Connect the end of each lead to the pads you have prepared by touching the tip of the soldering iron to the pad and then placing the tinned lead onto it.
\item
Refer to the SFM3400 datasheet to be sure you are connecting them in the proper position.
\end{enumerate}
\begin{figure}[H]
\label{fig:flow_sensor}
\centering
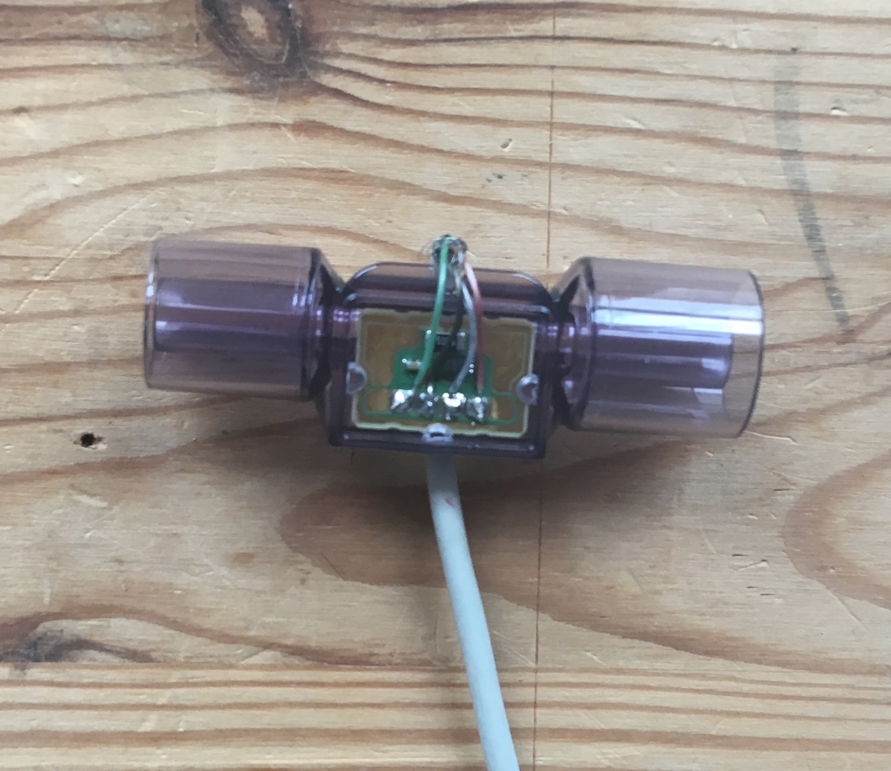
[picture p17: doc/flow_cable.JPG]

\caption{Sensor connected to cable assembly.}
\end{figure}

\item
  Assemble sensor adaptors. Refer to figure \ref{fig:adaptors} on page \pageref{fig:adaptors}.
  {\em NOTE: These photos and the 15mm adaptor show and refer to the neonatal version of the Sensirion flow sensor (SFM3400),
    which we used only because the adult-sized versions were impossible to find (temporarily). However, they physical
    assembly is exactly the same for all versions. You will not need the 15mm to 22mm adaptor with an adult-sized flow sensor.}

\begin{enumerate}[label=4.3.\arabic*]
\item
Cut a 1 $1/2$'' section of petex tubing
\item
Insert the tubing into the wide end of the flow sensor
\item
Insert the frosted 15 mm to 22 mm adaptor over the petex
\item
Add the clear 15 mm to 22 mm adaptor over the small end of the flow sensor
\item
Place the bleed adaptor over the clear adaptor
\item
Use electrical tape to secure any loose connections
\end{enumerate}
\begin{figure}[H]
\centering
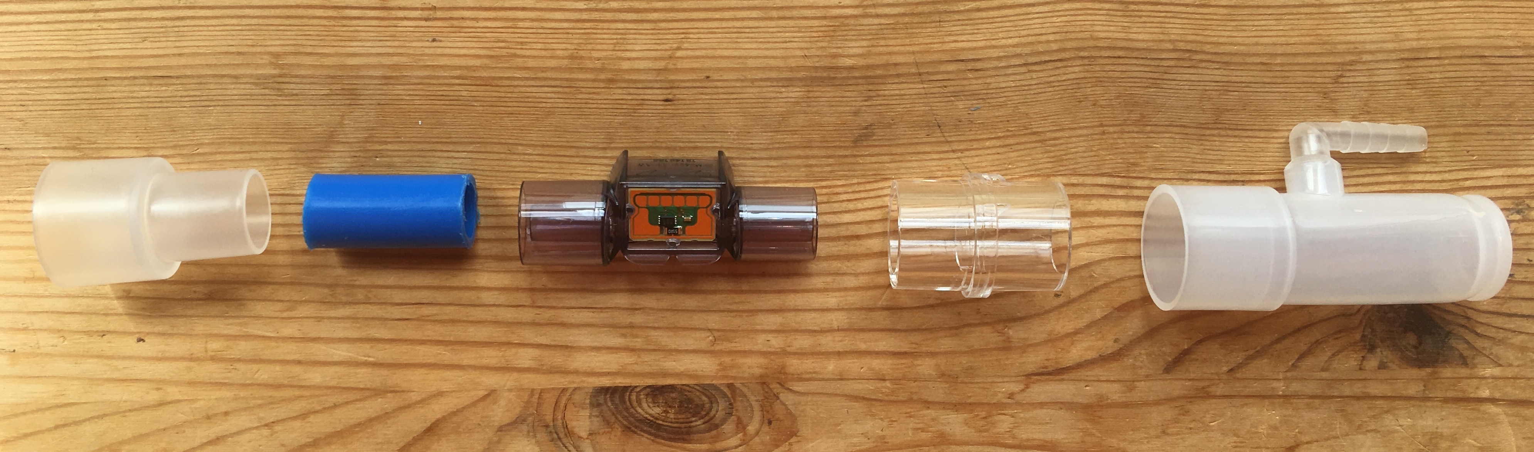
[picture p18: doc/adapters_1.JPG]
 \\
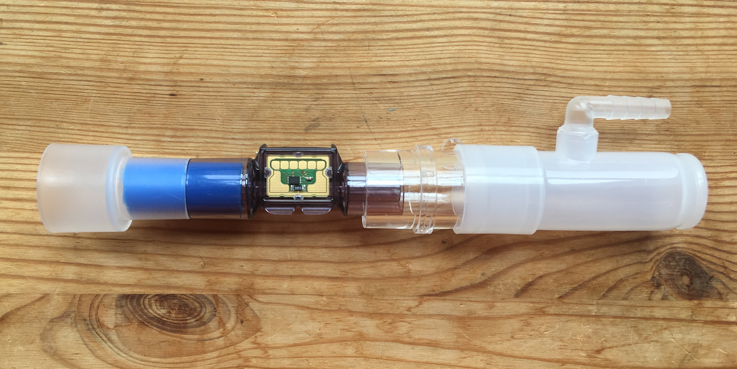
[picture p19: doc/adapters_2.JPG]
 \\
\caption{Adaptors assembled inline with sensor.}
\label{fig:adaptors}
\end{figure}

\end{enumerate}

%-----------------------------------------------------------
% FINAL ASSEMBLY
\item
Final Assembly

\begin{enumerate}[label=5.\arabic*]
\item
Glue oxygen hose to pressure sensor assembly. Refer to figure \ref{fig:bme_glue} on page \pageref{fig:bme_glue}.

\begin{enumerate}[label=5.1.\arabic*]
\item
Cut a section of oxygen hose approximately the same length as the flow sensor cable
\item
Make sure your cut is flat on the end
\item
Place one end of the hose over the internal, breathing circuit pressure sensor and apply glue around the edges
\item
Be very careful not to get glue on the sensor and make sure that the hose is securely attached to the pcb
\end{enumerate}
\begin{figure}[H]
\centering
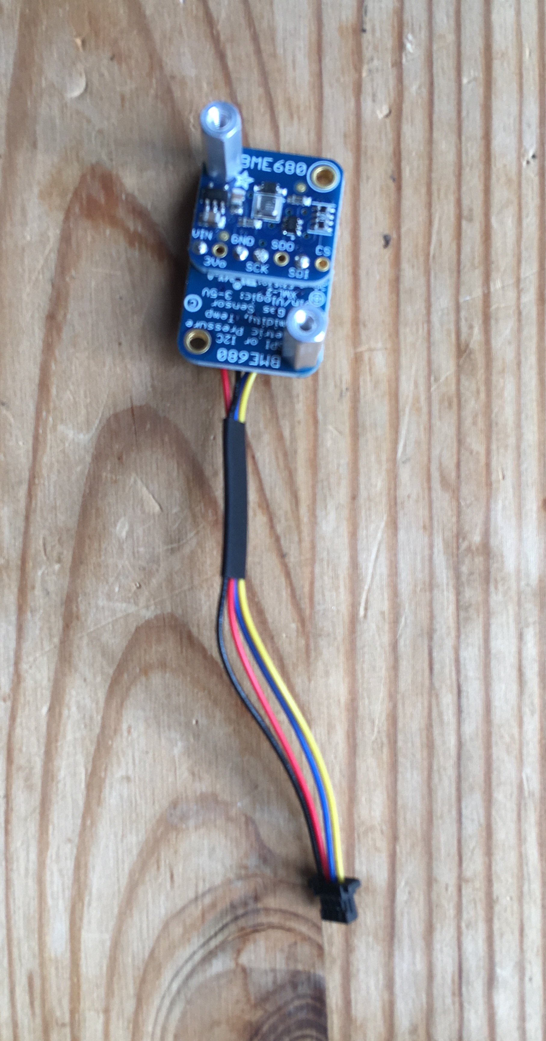
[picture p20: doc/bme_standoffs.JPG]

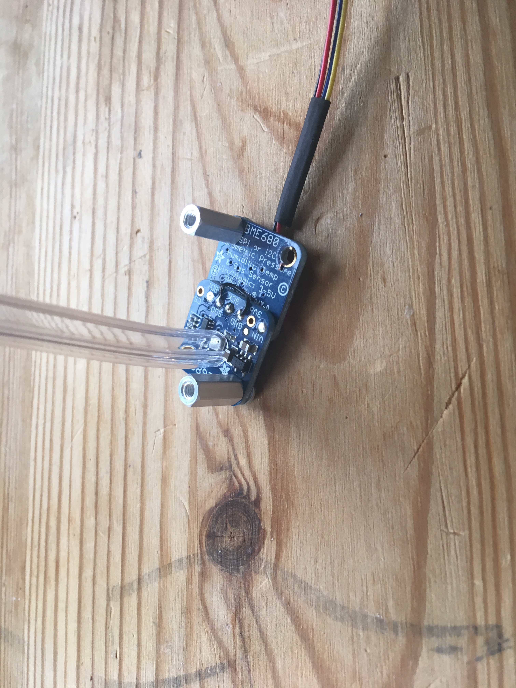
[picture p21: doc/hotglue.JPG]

\caption{Standoffs installed on pressure sensor assembly and oxygen hose prepared for gluing.}
\label{fig:bme_glue}
\end{figure}

\item
Install pressure sensor assembly. Refer to figure \ref{fig:bmeinbox} on page \pageref{fig:bmeinbox}.
\begin{enumerate}[label=5.2.\arabic*]
\item
Add two standoffs to opposite corners of the pressure sensor assembly
\item
These should correspond to the mounting holes you drilled in the enclosure
\item
Thread the bare end of the oxygen hose through its hole in the enclose from the inside until the sensor assembly is pressed against the wall of the  enclosure
\item
Attach the standoffs into the enclosure from the outside using two machine screws
\end{enumerate}
\begin{figure}[H]
\centering
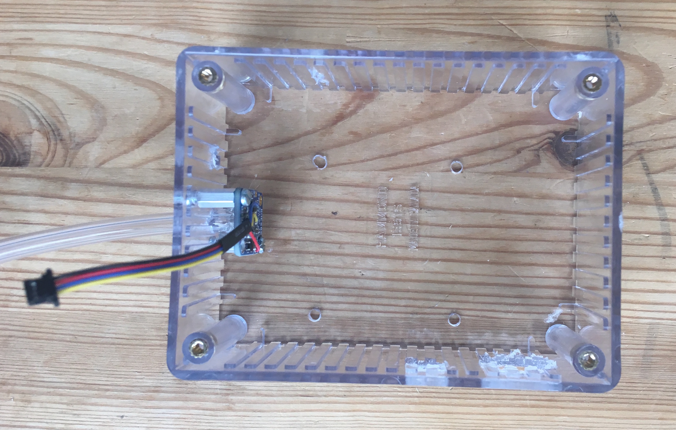
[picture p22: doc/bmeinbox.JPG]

\caption{Pressure sensor assembly installed in enclosure.}
\label{fig:bmeinbox}
\end{figure}
\item
Zip tie sensor cable to enclosure. Refer to figure \ref{fig:ziptie} on page \pageref{fig:ziptie}.
\begin{enumerate}[label=5.3.\arabic*]
\item
Thread the small zip tie through the two mounting holes in the enclosure
\item
Push the qwiic connector end of the flow sensor cable through its hole in the enclosure. It's a tight fit.
\item
Zip tie the cable to the side of the enclosure making sure that the jacket of the USB cable is engaged by the zip tie
\end{enumerate}
\begin{figure}[H]
\centering
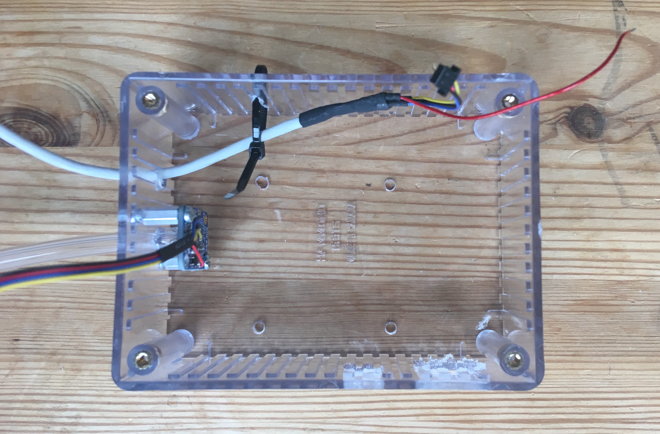
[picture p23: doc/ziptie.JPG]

\caption{Flow sensor cable with strain relief.}
\label{fig:ziptie}
\end{figure}

\item
Install ethernet shield and processor and add final touches.  Refer to figure \ref{fig:ziptie} on page \pageref{fig:ziptie}.
\begin{enumerate}[label=5.4.\arabic*]
\item
Attach standoffs to the four corners of the ethernet shield
\item
Screw the standoffs into the enclosure from the bottom
\item
Place the ESP32, OLED wing, and Qwiic shield on top of the ethernet shield as depicted in the diagram
\item
Plug the flow sensor and pressure sensor assembly into the qwiic shield
\item
Add a small piece of electrical tape every 5 inches attaching the oxygen tubing and flow sensor cable
\item
Wrap a piece of electrical tape around the flow sensor covering the exposed pads of the flow sensor
\item
Add identification card on the next page card to enclosure.
\begin{figure}[H]
\centering
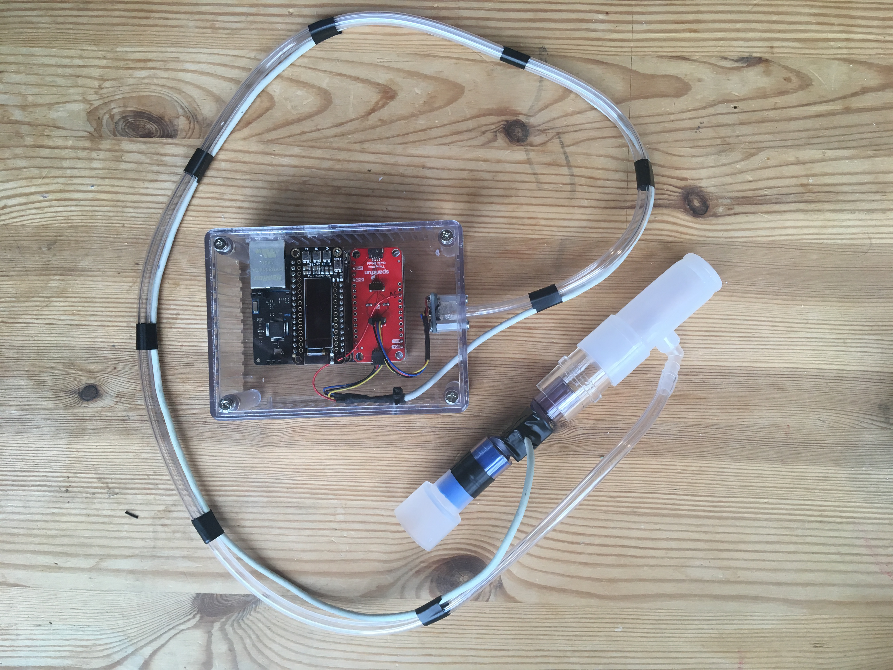
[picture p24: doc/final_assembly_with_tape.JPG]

\caption{Final assembly.}
\label{fig:final}
\end{figure}
%\begin{enumerate}[label=5.4.\arabic*]
\end{enumerate}
\end{enumerate}
\end{enumerate}

%-----------------------------------------------------------

\subsection{PCB Based VentMon (v0.3T)}

\begin{figure}[H]
\centering
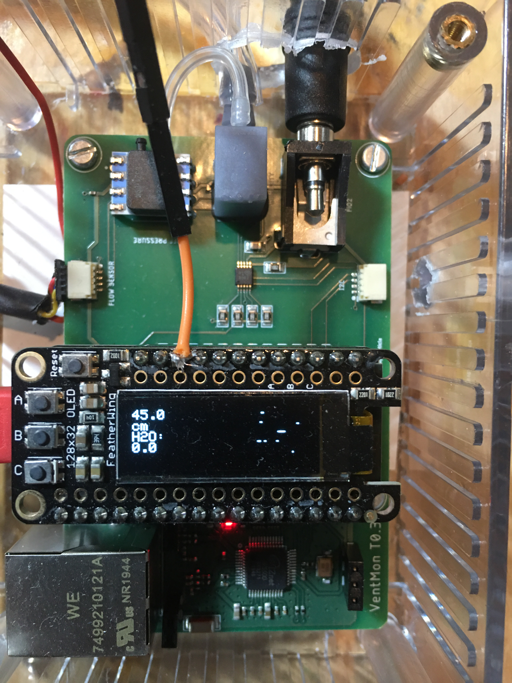
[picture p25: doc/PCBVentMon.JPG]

\caption{Final assembly of the PCB version}
\label{fig:finalPCB}
\end{figure}

This PCB-based v0.3T version of VentMon (see Figure \ref{fig:finalPCB}) requires two 3D printed parts---one encapsulated an on-board pressure sensor and one is an airway adaptor---as well as a PCB assembly. Before beginning the assembly process make sure that you have manufactured those parts.

\begin{enumerate}
\item
PCB Assembly

\begin{enumerate}[label=1.\arabic*]
\item Add standoffs to PCB
\begin{enumerate}[label=1.1.\arabic*]
\item take hardware and put it in the holes
\end{enumerate}

\item Mount sensor enclosure for BME280 pressure sensor
\begin{enumerate}[label=1.2.\arabic*]
\item Insert plastic part into mounting holes on PCB to check fit and alignment. The barb should face toward the outer edge of the PCB.
\item Apply epoxy glue to bottom edge and mounting pegs of plastic.
\item Insert plastic back into holes being careful not to get any glue on the sensor.
\item Allow 24 hours for epoxy glue to cure before attaching a hose to the barb.
\end{enumerate}

\end{enumerate}

\item
Enclosure

Follow assembly instructions in section \ref{itm:enclosure}.

\item
Flow Sensor Assembly

Follow assembly instructions in section \ref{itm:flow}.

\item
Oxygen Sensor Assembly

\begin{enumerate}[label=4.\arabic*]
\item
Screw the airflow flange on to the oxygen sensor
\item
Plug sensor into the blue airway adaptor piece
\item
Plug one end of mono audio cable into bottom of oxygen sensor
\item
Plug the other end into the audio connector on the PCB
\end{enumerate}

\item
  Final Assembly
  \begin{enumerate}[label=4.\arabic*]
  \item Connect Qwiic connector.
  \item Screw lid on.
    \item Optionally apply hot-melt glue to Qwiic cable connector where it enters the port.
    \end{enumerate}

\end{enumerate}

%----------------------------------------------------------

\section{Operation instructions}
%Provide detailed instructions for the safe and proper operation of the hardware.
%> Step-by-step operational instructions for operating the hardware.
%> Use visual instructions as necessary.
%> Highlight potential safety hazards.

\begin{figure}[H]
\centering
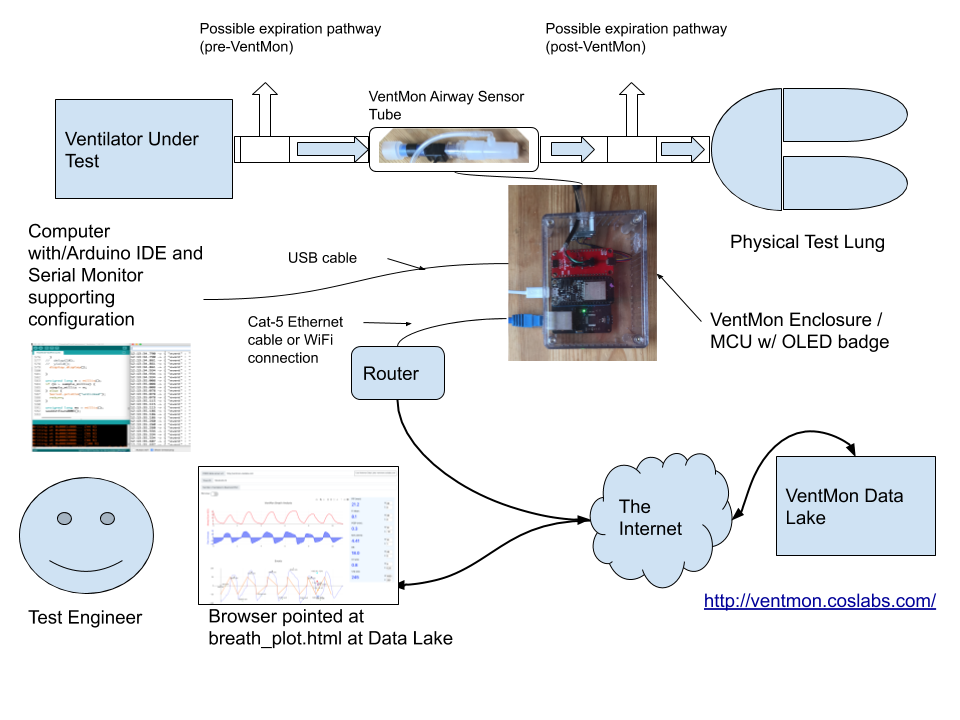
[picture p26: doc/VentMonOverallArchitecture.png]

\caption{Ventilator Test Usage}
\label{fig:vtestusage}
\end{figure}

\subsection{VentMon v0.3T}

{\em The VentMon v0.3T is not meant to be used on human patients. }
The purpose of the VentMon is to measure, log, validate and verify the performance of rapidly manufactured ventilators, PAPRs, BPAP, and CPAP machines. The basic usage is to plug the VentMon 22mm airway in between a respiration assistance device being tested (such as a pandemic ventilator or CPAP machine) and a simple physical test lung which models compliance and resistance of the human lung (see Figure \ref{fig:vtestusage}). The VentMon then provides approximately the functionality of a {\em breathing simulator}, without being able to model the patient triggering a breath spontaneously.

There are four ways to get data from the VentMon of varying quality and convenience with the firmware at the time of this writing.
\begin{enumerate}
\item After startup, the VentMon will begin displaying a real-time pressure graph on its small OLED screen, with a scale of 40 cmH$_2$O. This display is too small for testing performance, but is a nice check that the breathing circuit is in place and functioning. You can ``smoke test'' this by breathing into the VentMon and plugging one end with your hand.
\item The VentMon writes about 50 records a second of data out on the serial port in the PIRDS JSON format, publishing
  pressure and flow data at about 25Hz. (Additional data, such as temperature and humidity, is configurable output about every 20 seconds. Each record contains about 35 characters.
  Using the serial monitor built into the Arduino IDE, you can visually inspect this data. The volume of the data makes this a cumbersome. You are free to write a serial-port reader of your own for programmatic interpretation.
\item At startup, by default configuration (it can be enabled or disabled), the VentMon tries to see if their is a cable connected to the Ethernet RJ45 jack. Plug the other end of the cable into your router. If found and enabled, the VentMon will begin sending PIRDS\cite{PIRDS} data to the logger at \url{ventmon.coslabs.com}\cite{PIRDSlogger}. Your data can be viewed in real time by pointing a browser at the URL. Your IP address will appear near the top of the list with other recent or current users; by clicking on ``Breath Plot'' you will be able to see a complete clinical display.
\item Similarly at startup, the VentMon will attempt to establish a WiFi connection. Using the WiFi connection will transmit exactly the same PIRDS data the logger at \url{ventmon.coslabs.com} and can be used in precisely  the same way. However, the VentMon has to know a valid SSID and password to make the WiFi connection. This is configured via the Arduino serial monitor by sending a ``c'' character (for configure) to the VentMon. It will then pause operation for 10 seconds and give instructions for entering the SSID and password. In this same configuration you can enable or disable the WiFi and the Ethernet connection if you choose. These settings are stored in the EEPROM, and survive a loss of power.
\end{enumerate}

Pressing the ``C'' button on the VentMon OLED badge sends a special signal to the PIRDS logger to ``rotate the log'' from this IP address. At the public data lake the current file will be copied to a file which a date and timestamp.

\subsection{VentMon COTS Version}

A practitioner who makes their own version of the VentMon from commercial off-the-shelf parts without ordering a PCB will likely understand how to install
and modify the firmware. The VentMon v0.2T\cite{VentMon02} version is tagged specifically for this hardware release. The usage will likely be the same, though at the time of this writing some features
may not be available in the software they are using, such as WiFi configuration.

\section{Validation and characterization}

%Demonstrate the operation of the hardware and characterize its performance over relevant critical metrics
%> Demonstrate the use of the hardware for a relevant use case.
%> If possible, characterize performance of the hardware over operational parameters.
%> Create a bulleted list that describes the capabilities (and limitations) of the hardware. For example consider descriptions of load, operation time, spin speed, coefficient of variation, accuracy, precision and etc.

The primary use of the VentMon is to develop to and verify that rapidly manufactured ventilator meets requires specification, such as those published by the UK MHRA\cite{mhra2020specification}.

It is easy to have confidence in the basic dynamic function of the VentMon by simply breathing through it into a plastic test lung. Figure \ref{fig:ventdisplay} is a screenshot of VentDisplay rendering data from the VentMon with a human (RLR) breathing normally into a plastic test lung for 10 seconds. Although the VentDisplay and VentMon can be used independently, VentDisplay demonstrates what VentMon collects. The top trace is a pressure trace. The next shows flow. These curves are generated from samples published into the public data lake. VentMon produces pressure and flow graphs at about 25 samples per seconds which is fast compared to the physiological process of breathing. One can easily see that flow and pressure dynamically match the breath or changes in the mechanical ventilation, or even changes induced by changes in the resistance or compliance of the test lung.

The bottom trace on the display is the ``event'' curve which shows a number of computed values and events published from the VentMon, such as the humidity, FiO$_2$, and temperature. Additionally, the beginning and ending of each breath is detected, and total volume of the breath computed by integrating the flow.

\begin{figure}[H]
\centering

\caption{VentDisplay Data Display}
\label{fig:ventdisplay}
\end{figure}

These calculations allows us to present the numbers on the right side of the display, which are typical metrics found on a commercial ventilator. Computation of these values allows a would-be ventilator's performance to be verified and characterized against a repeatable and relevant standard. Features such as rise and fall time (at the bottom on the right) are particularly important. However, the most basic function is to dynamically report the respiration rate, peak pressure, minimum pressure, tidal volume and minute volume, and I:E ratio. In addition to the standard metrics, our software also measures pressure rise time which we have argued is an under-appreciated performance characteristic of rapidly manufactured emergency ventilators\cite{schulz2020importance}.

This VentDisplay software has been shown to be valuable, although it is dependent on accurate software decisions about the beginning and the ending of a breath, which can be subtle in some situations. The reliability of the data is inherently tied to the accuracy and precision of the device producing data for VentDisplay, which may or may not be a VentMon.

The flow and differential pressure sensors used in the VentMon require no calibration. A VentMon equipped with the Sensirion SFM3200-AW was tested with a calibrated 500ml syringe by integrating flow to obtain volume and found to reproduce volume and therefore flow more accurately than 2\%. This commercial flow sensor measures a maximum flow of 250 slm (standard liters per minute). This range is almost impossible to exceed for a human being (by design). Nonetheless, because we sometimes had to use a neonatal flow sensor with a limit of 80 slm, our software detects this limit and publishes a PIRDS error event when the sensor ``clips'', which extends to the adult flow sensors as well.

The oxygen sensor spec sheet claims to be within 1\% of  $FiO_2$. Since clinical practice normally prescribes $FiO_2$ in steps of 10\%, this seems accurate enough for both clinical use and
the current intended use of testing ventilator equipment. The differential pressure sensors have a resolution of 0.5 cmH$_2$O.

The Public Invention Respiration Data Standard format \cite{PIRDS} is the underlying method by which data is communicated from the VentMon device to VentDisplay. The standard was created to provide a repeatable way for multiple teams to cooperate. Using this standard and cloud-based software enables VentMon to support a distributed engineering team---often required by the COVID-19 social distancing measures. The VentDisplay software allows export of the JSON binding of the PIRDS data to allow other programs to process if it is desired. We believe these tools could someday allow us to support telemedicine as suggested by others \cite{rehm2018development}.

In fact we hope the VentMon will evolve into an open-source component that can be freely integrated into a pandemic ventilator or simply ``bolted on'' to be used to control ventilators or to monitor human patients. Although it can effectively test ventilation equipment today, before it can be recommended for use on patients, it will require regulatory approval, such as FDA approval. Before that can happens the VentMon must progress beyond a number of limitations:
\begin{enumerate}
\item The current device is not autoclavable or easy to sanitize. Although the intended use is on the
  inspiratory limb of the breathing circuit, it may be exposed to air-borne virus unless its air input
  is sanitized. Use on a human patient would therefore require it to be disposed of immediately.
\item Our software has not be subject to rigorous Quality Assurance (QA) and Risk Analysis (RA) as the FDA would request. We have argued\cite{ecosystem} for an ecosystem in which design teams such as Public Invention produce extensive documentation including  QA/RA documentation to be reused by firms that become medical device manufactures incorporating open-source designs.
\item The mechanical design of the VentMon will require additional alteration to make it robust enough for use in a clinical setting.
\item The current data lake and software allow data  logging over days or weeks. To enable longitudinal study of ventilator reliability we would like to create software that allows this data to be analyzed or accessed across long periods of time.
\end{enumerate}

\section{Acknowledgements}
% [List here those individuals who provided help during the research (e.g., providing language help, writing assistance or proof reading the article, etc.).] Please also identify who provided financial support for the conduct of the research and/or preparation of the article and to briefly describe the role of the sponsor(s), if any, in study design; in the collection, analysis and interpretation of data; in the writing of the report; and in the decision to submit the article for publication. If the funding source(s) had no such involvement then this should be stated.}

Robert L. Read: Conceptualization, Methodology, Software, Writing - Original Draft, Supervision.
Lauria Clarke: Software, Hardware, Investigation, Writing - Review and Editing.
Geoff Mulligan: Conecptualiztion, Software.

Robert L. Read conceived of and wrote most of the firmware for the VentMon.
Geoff Mulligan created the initial cloud-based IoT approach which became the PIRDS-logger.
Lauria Clarke did most of the hardware design, including the assembly instructions and
the printed circuit board based on an MIT-licensed Ethernet Feather Wing design
from Particle IoT\cite{particleefw}, and the SFM3X00 software repo for
encapsulating Sensirion flow sensors in the Arduino environment.
This paper was written by Robert L. Read and Lauria Clarke.

The Mozilla Open Source Software foundation gave Public Invention a grant that allowed us to develop the hardware and provide 20 VentMons to open source teams around the world free-of-charge, including paying shipping costs. Protocol Labs provided Public Invention a grant that has been used for web communication and conference costs.

We would like to thank early adopters of the VentMon on pandemic ventilator teams such as the ARMEE\cite{ARMEE}, PolyVent\cite{polyvent} and DIY-Beatmungsgerät.de\cite{beatmung} who gave us valuable bug reports and feedback.

Adafruit graciously continued to supply pandemic engineers and researchers even when their normal business was disrupted.

Student volunteers on the COVID19-vent-list project\cite{COVID19VENTLIST} helped to make the need for the VentMon clear by assessing over 100 pandemic ventilator teams.

\section{Declaration of interest}

None.
% a statement must be included even if there is no conflict of interest
% All authors must disclose any financial and personal relationships with other people or organizations that could inappropriately influence (bias) their work. Examples of potential conflicts of interest include employment, consultancies, stock ownership, honoraria, paid expert testimony, patent applications/registrations, and grants or other funding. Authors must disclose any interests in a summary declaration of interest statement in the manuscript file. If there are no interests to declare then please state this: 'Declarations of interest: none'. This summary statement will be ultimately published if the article is accepted. More information.}

% This work touched no humans or animals, I belive this section can be ommmited entirely.
% \section{Human and animal rights}

% \section*{References}
%> Include at least one reference, to the original publication of the hardware you customized.
%> Include other references as required. Include references to put your device in context in the literature. For more information on the reference format in HardwareX please see the Guide for Authors at: https://www.elsevier.com/journals/hardwarex/2468-0672/guide-for-authors

\printbibliography

\end{document}

%> Author manuscript checklist
%> ●	HardwareX is a journal dedicated to the exhaustive and fully open source communication of advances in scientific infrastructure. Upon submission the author declares that all information necessary to reproduce the subject of the submission (e.g. bill of materials, build instructions, calibration procedures, source files, code, and safety considerations) is communicated in full and is accessible for use under an open source license.
%> ●	Is the subject of the submission under an open source license - as defined by the Open Source Hardware definition?
%> ●	Can the hardware be reproduced with the details provided in the submission?
%> ●	Are all relevant design files available on Mendeley Data, the Open Science Framework, or Zenodo repositories, described in the Summary of Design Files document, and clearly documented? (e.g. descriptive file names, commented code, labeled images, etc.)
%>      ○	If in the Open Science Framework, the repository has be registered? Instructions
%>      ○	If in Zenodo, the repository is open access and is published? Instructions
%>      ○	If in Mendeley Data, the repository is published or the sharable link was included in the additional information of the Editorial Submission interface? Instructions
%> ●	Are visual instructions used when necessary?
%> ●	Is the utility of the hardware to the scientific community?
%> ●	Is the performance of the hardware adequately demonstrated and characterized?
%> ●	Are all potential safety concerns addressed?
%> ●	For more information on the article template consult the Guide to Authors.}

% Notes:
% Potential reviewers: Michelle Mellenthin, Eric Schulz, Angela Forgues

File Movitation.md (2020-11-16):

# Motivation of Strategy

As of March 18, 2020, the COVID-19 pandemic is growing quickly. The Maker, Humanitarian Enginering, and Free Sofware communities are attempting to answer the call. Public Invention is attempting to help the potential shortfall of ventilators, which is uncertain but could mean hundreds of thousands of needless deaths in a worst-case scenario.

Working with NECSI and [EndCoronavirus.org](https://www.endcoronavirus.org/), a self-organized project instigated by Bruce Fenton has arisen. It has become clear, however, that there are and should be many technical approaches.

In order to unify this community, some of us at the #response-ventilators-meta channel at the [necsi-edu.slack.com](necsi-edu.slack.com), include Nariman Poushin, have decided any practical response will have to focus on clinical effectiveness and reliability testing, because ventilators are life-critical pieces of machinery. In effect, we need an informal certification process similar in spirit only to FDA approval, which can convince a doctor or medical decision maker to deploy unapproved ventilators as an absolute last resort if there is a shortage of ventilators.

The Free Software and Maker communities know how to form teams; our plan is to form teams for design, testing, training, building, and even fundraising. The basic process we propose is captured in the diagram below.

Deployment Process

## Necessity of Extensive Testing

To deploy a ventilator, extensive testing is *absolutely* required. This repo is an attempt to build a "test fixture" capable of running a 48-hour test on any ventilator design and collecting data on many important parameters.  We hope to create a "gold standard" test that all DIY teams can work to; but this project will proceed in parallel with that.

As part of extensive testings, in combination with BreathOfLife (thanks to Jonathan Orban) and with help from Juan E. Villacres Perez, biomedical engineering student at UT, we have create a [Google Sheet](https://docs.google.com/spreadsheets/d/17EJ9TN6O1wqP4c-lIn5hbmuMRrto7M_KXHf17zjNSLk/edit?usp=sharing)
downloaded as an OpenDocument Calc and Microsoft Excel [spreadsheet](https://github.com/PubInv/ventmon-ventilator-inline-test-monitor/tree/master/ValidationTestSuites) of user tests which attempt to
match the [RMVS](https://assets.publishing.service.gov.uk/government/uploads/system/uploads/attachment_data/file/876167/RMVS001_v3.1.pdf) standard for Rapidly Manufactured Ventilator Systems.  (There are checkboxes in the Google Sheet that don't look nice in the other two formats.)
The spreadsheet is licenced under CC0, so you can make a copy of it and use it for testing your own ventilators.

## Physical Test Lungs

I believe that a test lung is meant to provide a resistance to inflation which models a human lung.  An example of a purchasable device is:

[Allied Healthcare AHP300 Mechanical Test Lung](https://mfimedical.com/products/allied-healthcare-ahp300-mechanical-test-lung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)

[5cm H20/L/sec. Resistance Test Lung](https://www.grainger.com/product/33JV39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!)

Note the units of resistance here: Pressure/volume/sec. Presumable a test that used open air would not accurate model a ventilator.

## Certifiers

An example of a certifier, including an explanation of its functionality is here: [Alnor-4070 Certifier  Flow Analyzer](https://www.globaltestsupply.com/product/alnor-4070-certifier-flow-analyzer-system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)

However, we also need to do multi-iteration reliabillity tests.  An initial design is here:

initial design

## Older diagram

Deployment Process

# Initial Design Idea

InlineVentMonitor

The idea is to make a standalone inline device plugged into the airway. It serves a dual purpose as a monitor/alarm when used on an actual patient, and a test devices for testing prototype ventilators. It also allows for burnin.



Electrical block diagram showing VentMon

ElectricalBlockDiagram

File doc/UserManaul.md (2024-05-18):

# VentMon T0.1 User Manual

This is the rapidly-evolving VentMon by Public Invention. This is for version T0.1 -- "Tester v. 0.1", which is aimed at
engineering teams needing to test rapidly manufactured pandemic ventilators.

# Introduction

The VentMon is a physical device designed to help the open-source community develop confidence in
rapidly manufactured ventilators systems. At present it serves a tester to be used on
the workbench of teams developing ventilators.  Eventually, we hope it will serve
the important function of providing a monitoring/alarming system as a module
within other designs, or as part of an emergent open design for ventilations systems.

# Basic Functionality

The VentMon plugs into an airway and measures flow and absolute and differential pressure within the
airway approximately 25 times a second. It measures oxygen, humidity, and temperature within
the airway and in the ambient air approximately once a minute.

The basic test function is to use the VentMon to log a data file over a period of time.
This log file may be viewed live (with imperceptible delay) via our software tools, allowing
an engineer to immediately observe pressures and flows. This same software computes
clinically important parameters such as tidal volume, minute volume, and respiration rate,
and I:E ratio. If produced over a long period of time, this would be evidence that the
ventilator is performing as expected.

# Measureable Flow is Currently Limited and Restriction Added

Due to a world-wide supply-chain problem, we have had to use a neo-natal flow sensor instead of
an adult flow sensor. This limits the instantaneous measurement of flow to 33 standard liters per minute.
In many circumstances, this will not matter; but in some test scenarios with highly compliant lungs
and low resistance, the flow sensor will "clip".

In our software, this will be visually apparent as the flow curve simply looks like it has been clipped off. We also report this in the PIRDS standard that we publish. However, this error does not currently
flow all the they way through our software.

Additionally, the flow sensor in use adds restriction to the flow. All physical lung systems have both [resistance](https://en.wikipedia.org/wiki/Airway_resistance)
and compliance. The fact that the VentMon T0.1 adds restriction due to the use of the [SFM3400](https://www.mouser.com/datasheet/2/682/Sensirion_01212019_Mass_Flow_Meters_SFM3400_Datash-1524577.pdf) may have to be taken account of in your testing.

# Physical Connections

Physical Configuration

The VentMon has up to 4 physical connections:

1. The air input, which is a female 22mm inner diameter airway tube. This is an international standard. The input to the VentMon comes from the ventilator or air-drive you are testing.
1. The air output, which is a standard male 22mm outer diameter port. This should be connected
to the test lung/patient.
1. A USB connection to provide 5V power to the VentMon. Additionally, the VentMon streams
[PIRDS](https://github.com/PubInv/respiration-data-standard) JSON data on the serial port, which is useful for testing and checks on verification.
It requires additional software, however, to produce an understandable picture of ventilator
performance.
1. An ethernet connection which is used by the VentMon to stream PIRDS data via UDP.
You are welcome to change the firmware, but our basic firmware streams data to our
public data lake on port `6111` and ventmon.coslabs.com.

# OLED Display

Your VentMon comes with a small OLED "badge" display for us to support with future firmware improvements.
At present, it will display a changing (live) display of the differential pressure.
This is useful mainly as an indication that the system is functioning properly.
In the future, we hope to evolve this display into a clinically useful display.

# Recommended Unboxing Testing

To familiarize yourself with the VentMon and "smoke test" basic operation, we recommend
the following steps:

1. Before connecting to a ventilator or a test lung, simply connect the VentMon to an
Arduino IDE and start the Serial Monitor. Do not change the firmware by uploading new code
unless you intend to do so. The current firmward outputs 115200 baud; set your Arduino
IDE to listen at that baud rate.
1. Observe that the VentMon is streaming a series of JSON objects conformant to the
[PIRDS](https://github.com/PubInv/respiration-data-standard) data standard.

If you cannot observe PIRDS data streaming, please contact us for support.

1. Now check that flow is measured by simpling blowing into the ventmon airway tube
or using a sanitary dry source of air such as a small fan.
1. The PIRDS type code for flow is "F" and the flow sensor the sensor of type "F" named
"A" and numbered "0". A PIRDS flow event looks like:
> { "event" : "M", "type" : "F", "ms" : 12103, "loc" : "A", "num" : 0, "val" : 0  }.
1. The units of flow according to the [PIRDS standard](https://github.com/PubInv/respiration-data-standard/blob/master/PIRDS-v.0.1.md) are standard liters per minute times 1000 (or milliliters pers minute.)  You should be able to create flow of a few milliliters per minute just by waving your hand quickly at the VentMon input; a fan will produce a much higher flow.
1. Observe that you can create a measurable flow.

If you cannot observer a measurable flow, please contact us for support.

Finally, observe that the pressure differential is approximately correct.

1. The VentMon measures pressure in the airway in absolute terms, but more useful
is the differential pressure, which looks like this:
>  { "event" : "M", "type" : "D", "ms" : 12037, "loc" : "A", "num" : 0, "val" : -11  }

The VentMon uses two independent BME680 sensors to compute the pressure differential.
The ambient pressure is kept as a running average over a period time. The instantaneous
pressure in the airway is published as an event about 25 times a second, as is the
difference with the ambient air.
1. Observe that the pressure in the Airway is of type "P" and numbered "A" and "0".
The amBient pressure is "B" and "0". Following medical practice, these absolute
pressures are measured in cm H<sub>2</sub>O. The VentMon PIRDS standard defines the units
reported for pressure to be hundredths of cm of H<sub>2</sub>O.
1. Therefore, at close to sea level, the "val" field for these absolute pressures should be close
to 10000. The amBient pressure is reported very rarely compared to the Airway pressure; it may
be challenging to find the "B" field in the serial output.
1. Differential pressure (when not in an active breathing circuit) should be at most tens (less than one cm H<sub>2</sub>O). This represents
miscalibration in our two sensors; we do not believe this inaccuracy is clinically significant
as long as it is small.

If the pressure sensors do not seem to be working, contact us for support.

# Software Usage

Although you are free to make any changes you wish to the VentMon firmware and to process its
output via any means you want, we have created what we hope is a convenient means of
reviewing the live peformance of a ventilator and test lung combination.

The simplest way to use the VentMon is to use our public data lake, which logs data for you on
a server hosted by Public Invention and its volunteers (Geoff Mulligan.) This produces
a live, real-time display modeled on what clinicians like to see.  This approach currently
offers no privacy; anyone can look at any of the data in the data lake. If you don't want
your data to be visible, don't attach an ethernet cable to the VentMon.

The data lake records data indefinitely in a log file named after your IP address. This,
and any other data logs, can be accessed by going to the [VentMon Data Lake](http://ventmon.coslabs.com/). From there, you can see your raw PIRDS data. By clicking on one of the links such as that of [Robert L. Read's personal Ventmon](http://ventmon.coslabs.com/breath_plot?i=136.49.35.13), you can
see live plots of differential pressure, flow, volume, and other parameters that are clinically
important. For each parameter, you can set high and low "alarm limits". These will turn
red when ventilator behavior is outside of this specified range, and will be blue while you are inside it.
(You will want to discover you own IP address, which may change occasionally depending on your
internet service provider, to find the Breath Plot of your own device.)

Breath Plot has a toggle switch that let's you switch live data on and off. When switched off,
you will be examining whatever is on the screen until you turn the live data back on, at which point it will show you about the last 10 or 20 seconds of data live.

The BreathPlot web page can, however, can be used with any system that produces data in the
[Public Invention Respiratory Data Standard](https://github.com/PubInv/respiration-data-standard/blob/master/PIRDS-v.0.1.md). You can create and import an array of JSON objects in the PIRDS standard and display it.

## Basic Steps for Seeing a Live Breath Plot

1. Make sure the VentMon is powered up via USB.
1. Connect a CAT-5 ethernet cable from the port to directly to your router (NOT your computer.)
1. Attempt to make sure you router allows outgoing IP packets to ventmon.coslabs.com on port `6111`.
You may or may not have to manipulate your router firewall configuration.
1. Determine your IP address as it appears to the outside world.
1. Using any modern browser, browse to [http://ventmon.coslabs.com/](http://ventmon.coslabs.com/).
1. Hopefully there you will see your IP address in a list that looks like this: DataLakeMainPageScreenshot
1. Identify your IP address in the list, and click on the Breath Plot link.
1. Hopefully you will see a live breath plot, changing constantly based on the actual flow
within the VentMon. If you ventilator is rhythmically forcing air through the VentMon, it
should look something like this: SampleBreathPlot
1. Observe the features on the right may or may not be red if they are within default limits. These features change slowly as the samples change. You will see about 12 seconds of breath data by default.

If you wish to see the software in use without having a live VentMon, you can paste a [sample PIRDS
data file](https://github.com/PubInv/ventmon-ventilator-inline-test-monitor/blob/master/breath_data/RobFM3200NoLung.pirds) into the text area and hit the "Import Trace" data file. These files were created by the "Export Trace" function.

The Import and Export Trace capabilities use the JSON binding of the PIRDS data standard. Although
offering little control at present, this provides a crude way to store, transmit, and communicate
breath data.

# Understanding Breath Plot Data

The Breath Plot data page has four areas:

1. An upper most meta-control area. This allows you to use a different data server,
if you wish, as longs as it serves PIRDS data in the JSON format. It also allows you
to control a few other parameters.
1. The plotting area shows three plots aligned in the horizontal dimension of time. The first plot is differential pressure (in the airway against ambient pressure.) The second is flow (change in volume over time.)
The final plot the "Event plot". The Event Plot uses an abstract scale. For convenience it draws ths flow plot. However, its main purpose is to show how the trace has been broken into breaths for the purpose of computing clinically significant measures. Ocasionally measurements such as temperature and humidity are rendered as markers on this plot.
1. On the right are the clinical measures, such as PIP, PEEP, Tidal Volume, Minute Volume, and Respiration Rate. This are has default high and low values. When the calculated values are outside this range, they number is drawn in red to draw attention to the fact that one parameter is outside the specifications.
1. Finally at the bottom is a simple user interface for importing and exporting traces.

# Test Lungs

The VentMon is not a test lung. The purpose of a test lung is to provide realistic and compliance
and resistance simulating a healthy or diseased human lung system.
It is not possible to predict the clinical performance of a ventilator unless it
has been extensively tested with a physical test lung. VentMon, can, however, measure
some aspects of ventilator without a test lung attached as a preliminary test.
Alex Izvorski of the [A.R.M.E.E.](https://armeevent.com/) and Robert L. Read of
[Public Invention](https://www.pubinv.org) have discussed this extensively in [How To Make Your Own Accurate Test Lungs for Testing Emergency Ventilators](https://medium.com/@RobertLeeRead/how-to-make-your-own-accurate-test-lungs-for-testing-emergency-ventilators-2d68fe5ac460).

# License

The VentMon is both open hardware and open software. The firmware that runs on the board and
makes sensor measurements is released under the [MIT License](https://github.com/PubInv/ventmon-ventilator-inline-test-monitor/blob/master/LICENSE). Other libraries and files may be
released under different open source licenses if they are derived works of starting points
released under other licenses.

Public Invention does not apply for patents. All of the hardware designs for the VentMon
are open. The particular design documents and drawings are released under Creative Commons
licenses as indicated on the document, generally either CC0 or CC-BY-SA.

# Obtaining

The VentMon is not a commercial product; it is given away free of charge
by Public Invention to teams addressing
the COVID-19 pandemic with the generous support of the [Mozilla Opens Source Support Foundation
(MOSS)](https://www.mozilla.org/en-US/moss/) and [Protocol Labs](https://protocol.ai/).

However, the parts in the VentMon are expensive, and we may not be able to meet demand.
To request a VentMon please contact us with a description of your need and a link to
your project. A small [donation](https://www.pubinv.org/donate/) helps make this work possible.

# Technical Support

For technical support, please contact <read.robert@gmail.com> by email. Some common problems and solutions are listed below. 

### Common Debug: Pressure Readings do not Align With Respiration  

If you have just unboxed the device you may find that the airway pressure does not change in relationship to the flow. If this is the case, it is possible that the I2C addresses of the two BME680 pressure sensors are reversed.  Please contact <read.robert@gmail.com> for support or change the addresses in FW yourself.   

The two addresses should be set as follows:  
AIRWAY pressure sensor address - 0x77  
AMBIENT pressure sensor address - 0x76  

# Firmware and Software Updates

As of May 1st, 2020, the VentMon is a rapidly changing system which can be
expected to have evolving firmware. Please check the [GitHub repo](https://github.com/PubInv/ventmon-ventilator-inline-test-monitor) often for firmware updates.

# Return to Us If You Don't Use

The VentMon is offered free-of-charge; however, if you decide to stop using it, please
contact us about shipping it back to us. There may be others who want one, and the
COVID-19 pandemic has created supply chain shortages.

# Constructing Your Own

You may build your own VentMon based on our [instructions](https://docs.google.com/document/d/1n-Ja3UgbrCLcY8kx9rmTZB7b3yNJ_DnjpA1hwfMbgXk/edit#heading=h.u1fih96r90b6)
or make modifications and improvements to this design.
If you make improvements, we hope you will submit them back to use under and open-source license
so that we may publish them to the whole community.

# Cleaning and Physical Connections

Before the VentMon is used as a monitor with real patients, sanitization procedures
will have to be provided. At present, the VentMon is intended as a tester only, and is not to be
used with real patients.  However, it should still be sanitized periodically. We recommend a quick
wipe with isopropyl alcohol. If you have breathed into the VentMon, do not allow another
person to breath it into, or any other part of your breathing circuit, without a full sanitization.
The VentMon is not autoclavable at present. We are not entirely sure how to fully sanitize it.

# Calibration is Not Needed

The Sensirion Flow Sensor that we use does not need further calibration. We have checked the
neonatal flow sensor against an adult flow sensor with a 500ml syringe; they are both extraordinarily
accurate. Additional double-checks are always valuable, but we do not believe a user of the
VentMon will have to worry about calibrating the flow measurement.

# Acknowledgements

Thanks to the Public Invention volunteers Lauria Clarke and Geoff Mulligan.

A special thanks to [Protocol Labs](https://protocol.ai/) and the Mozilla Open Source Support Foundation (MOSS)
[COVID-19 Solutions Fund](https://blog.mozilla.org/blog/2020/03/31/moss-launches-covid-19-solutions-fund/)
which made generous grants to support this project.

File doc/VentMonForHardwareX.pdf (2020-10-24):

Title: VentMon: and Open Source Inline Ventilator Test Fixture and Monitor

Authors: Robert L. Read, Lauria Clarke, Geoff Mulligan

Affiliations: Public Invention with support from the Protocol Labs and the Mozilla Foundation

Contact email: read.robert@gmail.com

Abstract:

Humanitarian engineers responded to the pandemic ventilator shortage of March, 2020, by beginning over 100 open source ventilator projects. Inexpensive ventilator test equipment facilitates projects forced to be geographically distributed by lockdowns. The VentMon is a modular, open source, IoT-enabled tester that plugs into a standard 22mm airway between a ventilator and a physical test lung to test any ventilator by graphing flow, pressure, oxygen fraction, humidity and temperature at a data lake accessible to all team members. This is the data needed by a test team, but also the data desired by a clinician in actual treatment of patients. The open source design of the VentMon and its firmware and cloud-based software may allow it to be used as a component of modular ventilators to provide a clinical readout. This software system has been designed to be as modular and composeable as possible, for example by defining new open published standards, just as the hardware is composeable and modifiable, forming an open system or eco-system of ventilation data. Thanks to grants, 20 VentMons have been given away free of charge to pandemic response teams building open source ventilators, some of which have been used successfully.

Keywords: COVID-19, open source medical device, ventilator, pandemic response

Specifications table:

Hardware name | VentMon
Subject area | Educational Tools and Open Source Alternatives to Existing Infrastructure
Hardware type | Field measurements and sensors, Electrical engineering and computer science
Open source license | MIT License, CERN-OHL-S
Cost of hardware | $280

Source file repository

VentMon:
https://doi.org/10.5281/zenodo.4079170
PIRDS (Public Invention Respiration Data Standard): http://doi.org/10.5281/zenodo.4079377
PIRDS logger:
Zenodo. http://doi.org/10.5281/zenodo.4079382 SFM3X00:
http://doi.org/10.5281/zenodo.4079355 VentDisplay:
http://doi.org/10.5281/zenodo.4079374

DOI URL to an approved source file repository: Mendeley Data, (https://data.mendeley.com/) the OSF, (http://osf.io) or Zenodo (https://zenodo.org/) (instructions). (https://doi.org/10.5281/zenodo.3346799) For example: https://doi.org/10.5281/zenodo.3346799

If there is no external repository write “ Available in the article ”

### 1. Hardware in context

The Coronavirus pandemic has created a global shortage of ventilators.Ventilators are expensive to manufacture and during uncertain times supply chains can be disrupted increasing the cost and scarcity of these devices. Since the beginning of the pandemic in March, there has been a large movement to develop cheaper, more supply chain resilient ventilator. The urgency and goals of this movement have shifted as the global understanding of the virus has evolved. Regardless of the current state of this movement, however, the use of open source medical devices in resources limited emergency situations – common during a global pandemic – is a topic that has come to the forefront of may conversations about preparedness and treatment. Medical devices require rigorous testing before they can be used on the general public. Open source medical devices require the same level, if not more scrutiny. If an open source movement is to succeed in this field, the tools to test and validate medical devices should also be community based. The goal of VentMon is to provide an equally open source, community based verification solution to increase the efficiency and accuracy of the development process for socially distanced, potentially international teams making open source ventilator devices.

### 2. Hardware description

The VentMon plugs directly into a standard 22mm adult airway. As air or medicaly gases pass through the VentMon, it records flow and pressure about 40 times a second, and occasionally records temperature, humdity, and O2 fraction. The result is that when placed in the airway between an invasive or non-invasive ventilator under test and physcial test lung, it sends this data to a public data lake using a clearly defined respiration standard. This data can be graphically rendered either live or statically to provide a display that is typical of the clinical display of advance ventilators. In this way it allows sophisticated testing of ventilators. This device is therefore similar in function to an ASL5000 or a Michigan Test Lung device, which tend to start at USD$10,000.
A special challenge of teams building open source pandemic ventilators is that they tend to be poorly funded, but also geographically distributed. The VentMon is an IoT-enbabled device which sends its data to a public data lake, where a team member on a different continent can view it live in real time as a collleagure makes adjustments to the ventilator.
The VentMon thus offer benefits to teams developing ventilation devices:
- It is inexpensive.
- It is completely open and part of a modular hardware/software system that can be customized and extended.
- It is allows remote collaboration.

Moreover, being completely open, it supports modifcation, extension, and importantly but only potentially at present, integration into a complete ventilator. A ventilator that chose to offer a graphical trace of pressure and flow, which are generally demanded by clinicians for all but emergency transport situations, could incorporate the open source VentMon into its complete design.
Although the reliance on the internet is a strength for a distributed engineering team, it would be a disadvantage it a field hospital. Although aiming to eventually be safe enough and reliable to be used as a monitor on human patients, it requires much improvement before it is ready for that intended use.

### 3. Design files

TODO Need to make hyperlinks colored in Location of File column

3.1 Design Files Summary

Design file-name | File type | Open source license | Location of the file
Embedded Firmware | C++ Source Code | MIT License | VentMon Firmware (https://github.com/PubInv/ventmon-ventilator-inline-test-monitor/tree/master/VentMonFirmware)
PIRDS Data Viewer | HTML Source Code | MIT License | Vent Display (https://github.com/PubInv/vent-display)
PIRDS Data Logger | C Source Files | MIT License | PIRDS Logger (https://github.com/PubInv/PIRDS-logger)
VentMon T0.3 PCB | PCB Design Files | MIT License | VentMon PCB (https://github.com/PubInv/ventmon-ventilator-inline-test-monitor/tree/master/design/pcb)
Pressure Sensor and Airway Adaptor | STL File | MIT License | VentMon Adaptors (https://github.com/PubInv/ventmon-ventilator-inline-test-monitor/tree/master/design/3dparts)

PIRDS Data Standard

For each design file listed above, include a short description of the file here (one or two sentences)

### 4. Bill of materials

Current Link: VentMon HardwareX BOM (https://docs.google.com/spreadsheets/d/1EaXni1Mxnvv0jaeDQ9I1xbvPcNkRtYN8TABCBzB3cpw/edit)

- BOM needs to be converted to PDF and uploaded per instructions:
For a complex Bill of Materials, the complete Bill of Materials (editable spreadsheet file e.g., ODS file type or PDF file) can be uploaded in an open access online location such as the Open Science Frameworks repository. Include the link here. Alternatively, the Bill of Materials can be uploaded at the time of submission on the online Elsevier submission interface as supplementary material.

### 5. Build instructions

Two versions of VentMon can be assembled depending on availability of parts and time. The most physically robust and complete version of VentMon requires the purchase and manufacture of a PCB as well as a number of 3D printed plastic parts. The designs of the PCB and 3D printed parts are fully open; in practice, due to the fact that PCBs have a high set up cost, it makes most sense to use the PCB if you are bulding 10 or more VentMons. This version of the device requires the least amount of time to assemble and contains fewest discrete components. Due to the high cost of PCB manufacture and assembly, VentMon can also be created using off the shelf components readily available from DIY electronics suppliers. This version requires significantly more assembly time. We believe this has been done twice by third parties with little interaction with us. Both assembly procedures are outlined below.

5.1 COTS Based VentMon

1. Qwiic Shield Assembly

See Figure 2 on page 6 for final assembly of Qwiic Shield.

1.1 Trim two pieces of male header pins that are two positions long and one piece that is four positions long.

1.2 With the connector side of the board facing up, solder one of the two position headers into the two holes labelled SDA and SCL.

1.3 Solder the other two position header into the last two holes on the row along the opposite side.

1.4 Solder the four position header into the last four holes along the right side. This should provide connections to the GND and 3V3 through holes.
1.5 Connect both sides of the solder bridge to engage the pullup resistors for the I²C bus.


Figure 1: SparkFun Qwiic Shield with male headers and I²C pullups connected

2. Enclosure

Before starting this step download and print the drill template. See Figure ?? on page ?? for finished hole pattern.

2.1 Cut out the template and tape it to the enclosure.

2.2 Make sure the lid of the enclosure is firmly screwed on before drilling

2.3 Drill holes in the locations denoted on template using the recommended drill sizes for each hole.

Figure 2: SparkFun Qwiic Shield with male headers and I²C pullups connected

3. Pressure Sensor Assembly

3.1 Drill out mounting holes
3.1.1 Using the 7/64? drill bit, carefully enlarge the mounting holes in each corner of the sensor
3.1.2 You can do all four or just two - one on the left side of one board and one on the right side of the other

3.2 Cut trace from SDO through hole to sensor

3.2.1 Carefully cut the trace coming from the SDO hole on the back side of one board 3.2.2 This board will be used to measure the airway pressure

3.3 Assemble Cable

3.3.1 Cut one connector off the Qwiic cable
3.3.2 Strip and tin the last ?? of the leads

3.4 Connect Sensors to Cable

3.4.1 Stack the two sensors on the breadboard and use two paper clips to anchor them 3.4.2 Be sure the airway board with the cut trace is facing down
3.4.3 Starting with Vin or GND insert the tinned lead through the appropriate hole and apply solder
3.4.4 Flip the sensor assembly over and make sure solder has flowed through both through holes, adding some if needed
3.4.5 Don?t worry if the solder does not flow perfectly
3.4.6 Pin the assembly back down and move to another connection following the connection table below
3.4.7 Repeat the steps above until the two boards have been secured and all leads are connected
3.4.8 Re-flow all the joints to ensure a good connection
Signal | Qwiic Color
GND | black
VIN | red
SDA | blue
SCL | yellow

Table 1: pressure sensor wiring

3.5 Add address jumper to ambient pressure sensor

3.5.1 Take a 1/2 piece of hookup wire and strip both ends
3.5.2 Flow the solder in the GND through hole and poke one end of the hook up wire into the hole
3.5.3 Put the other end of the wire into the SDO through hole and apply solder
4. Flow Sensor Assembly

4.1 Assemble Cable
The flow sensor requires a 5 V input, however we will run the I²C bus at 3.3 V necessitating this cable.

4.1.1 Cut the Qwiic cable in half
4.1.2 Cut off the red conductor near the base of the connector 4.1.3 Cut a 30 cm length from the USB cable
4.1.4 Strip the jacket back 1 1/2” from one end
4.1.5 Strip the first 1/4” of each conductor on one end and tin
4.1.6 Twist a small portion of the shield into the black GND conductor
4.1.7 Place a small piece of heat shrink on each conductor of the Qwicc cable and push them toward the connector end
4.1.8 Solder the ends of the Qwiic cable to the ends of the USB cable following Table 2.
USB | Qwiic | Signal
black | black | GND
green | blue | SDA
white | yellow | SCK
red | single 6” wire | 5V

Table 2: flow sensor wiring

4.1.9 Connect the red wire to the red condutor in the USB cable and solder the extra long male header pin to the end
4.1.10 Cover the finished joints with a short 1/4” piece of heat shrink

4.2 Connect cable to sensor

4.2.1 Apply a small quantity of solder to the four center pads on the SFM3400 flow sensor 4.2.2 Remove 5/8” of the jacket on the bare end of the USB cable
4.2.3 Strip back 1/8” from each conductor and tin the ends
4.2.4 Thread the cable through the hole in the sensor as shown in the photo and make sure the tinned leads can reach the sensor pads
4.2.5 Connect the end of each lead to the pads you have prepared by touching the tip of the soldering iron to the pad and then placing the tinned lead onto it.
4.2.6 Refer to the SFM3400 datasheet to be sure you are connecting them in the proper position.

4.3 Assemble sensor adapters

4.3.1 Cut a 1 1/2” section of petex tubing
4.3.2 Insert the tubing into the wide end of the flow sensor
4.3.3 Insert the frosted 15 mm to 22 mm adapter over the petex
4.3.4 Add the clear 15 mm to 22 mm adapter over the small end of the flow sensor 4.3.5 Place the bleed adapter over the clear adapter
4.3.6 Use electrical tape to secure any loose connections
5. Final Assembly

5.1 Glue oxygen hose to pressure sensor assembly

5.1.1 Cut a section of oxygen hose approximately the same length as the flow sensor cable 5.1.2 Make sure your cut is flat on the end

5.1.3 Place one end of the hose over the airway pressure sensor and apply glue around the edges
5.1.4 Be very careful not to get glue on the sensor and make sure that the hose is securely attached to the pcb

5.2 Install pressure sensor assembly

5.2.1 Add two standoffs to opposite corners of the pressure sensor assembly
5.2.2 These should correspond to the mounting holes you drilled in the enclosure
5.2.3 Thread the bare end of the oxygen hose through its hole in the enclose from the inside until the sensor assembly is pressed against the wall of the enclosure
5.2.4 Attach the standoffs into the enclosure from the outside using two machine screws

5.3 Zip tie sensor cable to enclosure

5.3.1 Thread the small zip tie through the two mounting holes in the enclosure
5.3.2 Push the qwiic connector end of the flow sensor cable through its hole in the enclosure. It?s a tight fit.
5.3.3 Zip tie the cable to the side of the enclosure making sure that the jacket of the USB cable is engaged by the zip tie

5.4.1 Install ethernet shield and processor
5.4.2 Attach standoffs to the four corners of the ethernet shield
5.4.3 Screw the standoffs into the enclosure from the bottom
5.4.4 Place the ESP32, OLED wing, and Qwiic shield on top of the ethernet shield as depicted in the diagram
5.4.5 Plug the flow sensor and pressure sensor assembly into the qwiic shield

5.4 Add a small piece of electrical tape every 5 inches attaching the oxygen tubing and flow sensor cable

5.5 Wrap a piece of electrical tape around the flow sensor covering the exposed pads of the flow sensor

5.6 Add identification card on the next page card to enclosure.

5.2 PCB Based VentMon

This version of VentMon requires two 3D printed parts – one encapsulated an on-board pressure sensor and one is an airway adaptor – as well as a PCB assembly. Before beginning the assembly process make sure that you have manufactured those three parts.

1. PCB Assembly

1.1 Add standoffs to PCB

1.1.1 take hardware and put it in the holes

1.2 Mount sensor enclosure for BME280 pressure sensor

1.2.1 Insert plastic part into mounting holes on PCB to check fit and alignment. The barb should face toward the outer edge of the PCB.
1.2.2 Apply glue to bottom edge and mounting pegs of plastic.
1.2.3 Insert plastic back into holes being careful not to get any glue on the sensor.

1.2.4 Allow 24 hours for glue to cure before attaching a hose to the barb.

2. Enclosure

Follow assembly instructions in section *enclosure*

3. Flow Sensor Assembly

Follow assembly instructions in section *flow sensor assembly*

4. Oxygen Sensor Assembly
5. Final Assembly

### 6. Operation instructions

Provide detailed instructions for the safe and proper operation of the hardware.

- Step-by-step operational instructions for operating the hardware.
- Use visual instructions as necessary.
- Highlight potential safety hazards.

### 7. Validation and characterization

Demonstrate the operation of the hardware and characterize its performance over relevant critical metrics

- Demonstrate the use of the hardware for a relevant use case.
- If possible, characterize performance of the hardware over operational parameters.
- Create a bulleted list that describes the capabilities (and limitations) of the hardware. For example consider descriptions of load, operation time, spin speed, coefficient of variation, accuracy, precision and etc.

Because the VentMon produces pressure and flow graphs at about 25 samples per seconds which is fast compared to the physiological process of breathing, it is easy to have confidence in the basic dynamic function of the VentMon by simply breathing through it into a plastic test lung. One can easily see that flow and pressure dynamically match the breath or changes in the mechanical ventilation, or even changes induces by changes in the resistance of compliance of the test lung. The flow and pressure sensors used in the VentMon require not calibration. Flow was checked with a graduated syringe and found to be quite accurate. Pressure sensors can be double checked by checking ambient pressure and, for example, computing altitude of the physcial location. Other aspects of ventilation such as respiration rate, peak inspiratory pressure, Inhalation to Exhalation ratio, work of breathing, etc. are dependenent on the VentDisplay software which are a module not technically part of the VentMon hardware. This software has been shown to be valuable, although it is dependent on accurate software decisions about the beginning and the ending of a breath, which can be subtle in some situations.

### 8. Acknowledgements

Robert L. Read conceived of and wrote most of the firmware for the VentMon. Geoff Mulligan created the initial cloud-based IoT appoach which became the PIRDS-logger. Lauria Clarke did most of the hardware design, including the assembly instructions and the printed circuit board based on an open source design from Adafruit[?, ?, ] and the SFM3X00 software repo for encapsulating Sensirion flow sensors in the Arduino environment. This paper was written by Robert L. Read and Lauria Clarke.
The Mozilla Open Source Software foundation gave Public Invention a grant that allowed us to develop the hardware and provide 20 VentMons to open source teams around the world free-ofcharge, including paying shipping costs. Protocol Labs provided Public Invention a grant that has been used web communication and conference costs.
We would like to thank early adopters of the VentMon on pandemic ventilator teams such as the ARMEE[] and DIY-Beatmungsger¨at.de[] who gave us valuable bug reports and feedback. Student volunteers on the COVID19-vent-list project[] helped to make the need for the VentMon clear by assessing over 100 pandemic ventilator teams.

### 9. Declaration of interest

None.

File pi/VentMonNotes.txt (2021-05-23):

STEPS TO RUN LOCAL VENTMON with RASPBERRY PI
(v0.0)

comments, questions, concerns: lauria.clarke@gmail.com

key:
>  - paste this in your termianl
## - comment about the output of prior command

----------------------------------------------------
SETUP

1. setup necessary VentMon repos
> mkdir ~/VentMon
> cd VentMon
> git clone https://github.com/PubInv/vent-display.git
> git clone https://github.com/PubInv/PIRDS-docker-local.git

2. install docker
> sudo apt-get update
> sudo apt-get upgrade
> curl -fsSL https://get.docker.com -o get-docker.sh
> sudo sh get-docker.sh
> sudo dpkg --configure -a
> sudo usermod -aG docker pi
## reboot
> docker info
## should return without error
> docker run hello-world
## should also return without error
## download and install updated version of libseccomp2 
## download from here: https://packages.debian.org/sid/libseccomp2
> cd ~/Downloads/libseccomp2_2.X.X-1+b1_armhf.deb
## replace path with real path name of downloaded version
> sudo dpkg -i libseccomp2_2.X.X-1+b1_armhf.deb

3. install node.js and packages
> cd ~
> curl -sL https://deb.nodesource.com/setup_14.x | sudo bash -
> sudo apt-get install -y nodejs
> node --version
> npm install yargs
> npm install cors
> npm install express
> npm install serialport 

4. check that vent-display will run
> cd ~/VentMon/vent-display
> rm -r node_modules/@serialport
> node serialserver.js --uaddress=127.0.0.1 --sport=/dev/cu.usbserial-01D97104 --uport=6111
## should start and throw this error:  
## Error: No such file or directory, cannot open /dev/cu.usbserial-01D97104

5. plug in VentMon and find serial port
## plug in VentMon
> ll /dev/tty*
## unplug VentMOn
> ll /dev/tty*
## missing port is the one you want, likely /dev/ttyUSB0

----------------------------------------------------
START

5. start the docker image
> cd ~/VentMon/PIRDS-docker-local
> docker build --tag pirds-logger .
> docker run -d --rm --name logger -p 8081:80 -p 6111:6111/udp -v `pwd`/logger_src/data:/data pirds-logger

6. start vent-display
> cd ~/VentMon/vent-display
> node serialserver.js --uaddress=127.0.0.1 --sport=/dev/ttyUSB0 --uport=6111 &

7. go to local breath plot
## go to localhost:8081
## click on Breath Plot link for first IP address

----------------------------------------------------
STOP

8. stop the whole thing
> pidof node
## get the pid of the .js
> kill -9 <pid>
> docker stop logger

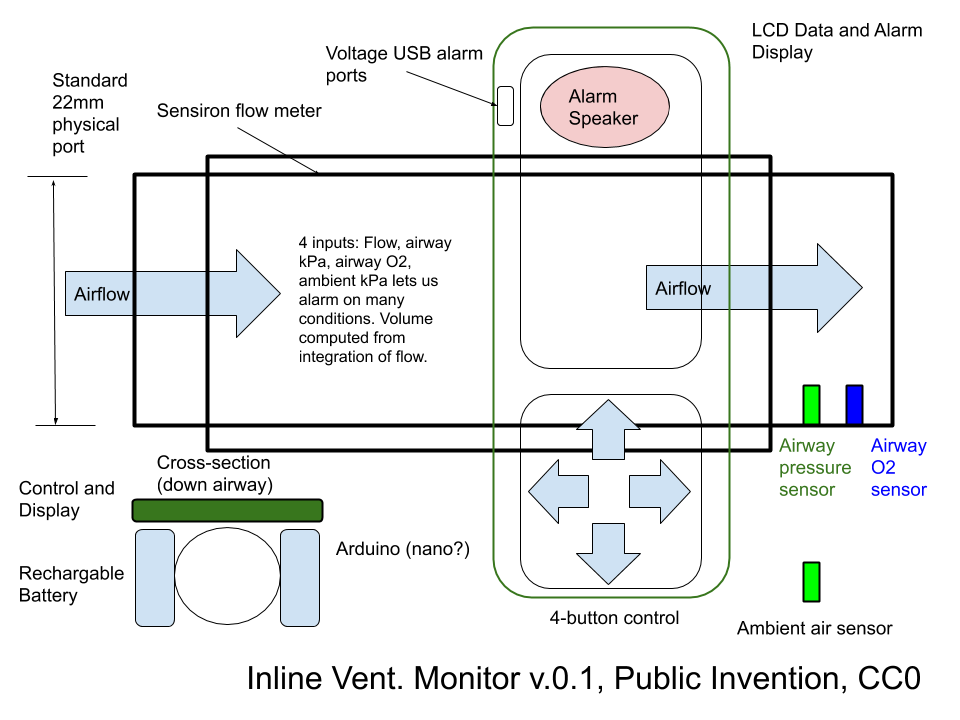
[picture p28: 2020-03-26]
InlineVentMonitor (1).png

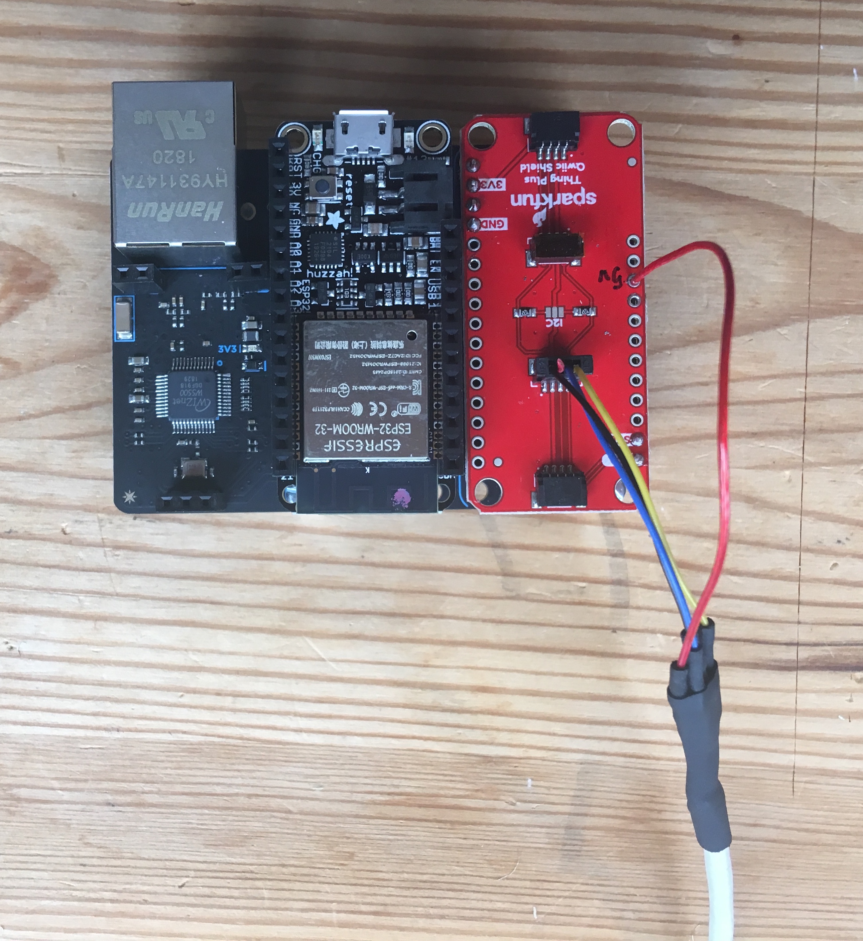
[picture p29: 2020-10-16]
doc/finished_flow_cable.JPG

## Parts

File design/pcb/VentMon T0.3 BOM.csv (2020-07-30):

Description | Qty | RefDes | Mfg | Mfg PN
CONN HDR 2POS 0.1 TIN PCB | 2 | J2, J3 | Sullins Connector Solutions | PPTC021LFBN-RC
CONN HDR 3POS 0.1 TIN PCB | 1 | J1 | Sullins Connector Solutions | PPTC031LFBN-RC
DIODE GEN PURP 100V 250MA SOD323 | 1 | D2 | Nexperia | BAS165J,115
FERRITE BEAD 600 OHM 0805 1LN | 1 | L2 | TDK | MPZ2012S601ATD25
CONN HEADER SMD R/A 4POS 1MM | 2 | FLOWSENSOR, J5 | JST Sales America Inc. | SM04B-SRSS-TB(LF)(SN)
CONN HDR 16POS 0.1 TIN PCB | 1 | J6 | Sullins Connector Solutions | PPTC161LFBN-RC
CONN HDR 12POS 0.1 TIN PCB | 1 | J7 | Sullins Connector Solutions | PPTC121LFBN-RC
CAP CER 0.1UF 50V X7R 0402 | 12 | C1, C2, C3, C4, C5, C6, C9, C10, C11, C17, C19, C21 | Murata | GRM155R71H104KE14J
RES SMD 0 OHM JUMPER 1/16W 0402 | 1 | R17 | Yageo | RC0402JR-070RL
RES SMD 10K OHM 1% 1/16W 0402 | 3 | R2, R20, R21 | Vishay Dale | CRCW040210K0FKEDC
RES SMD 10K OHM 1% 1/8W 0805 | 5 | R4, R5, R7, R9, R15 | Yageo | RC0805FR-0710KL
RES SMD 4.7K OHM 1% 1/8W 0805 | 2 | R1, R3 | Yageo | RC0805FR-074K7L
RES SMD 10 OHM 1% 1/16W 0402 | 1 | R12 | Yageo | RC0402FR-0710RL
RES ARRAY 4 RES 10K OHM 0804 | 2 | RN1, RN2 | Panasonic | EXB-28V103JX
CAP CER 10000PF 50V X7R 0402 | 2 | C14, C26 | Yageo | CC0402KRX7R9BB103
CAP CER 10UF 6.3V X7R 0603 | 2 | C22, C23 | Samsung Electro-Mechanics | CL10B106MQ8NRNC
RES SMD 12.4K OHM 1% 1/16W 0402 | 1 | R6 | Yageo | RC0402FR-0712K4L
CAP CER 18PF 50V C0G/NPO 0402 | 2 | C7, C8 | Yageo | CC0402JRNPO9BN180
RES SMD 1M OHM 1% 1/16W 0402 | 1 | R8 | Yageo | RC0402FR-071ML
RES SMD 1K OHM 1% 1/16W 0402 | 1 | R24 | Yageo | RT0402FRE071KL
CAP CER 1000PF 2KV X7R 1808 | 1 | C15 | KEMET | C1808C102KGRACTU
CAP CER 1UF 25V X7R 0805 | 1 | C18 | KEMET | C0805C105K3RACTU
CRYSTAL 25MHZ 12PF SMD | 1 | Y1 | ECS | ECS-250-12-33-AGN-TR
RES SMD 330 OHM 1% 1/16W 0402 | 2 | R22, R23 | Yageo | AC0402FR-07330RL
RES SMD 33 OHM 1% 1/16W 0402 | 4 | R34, R35, R36, R37 | Yageo | RC0402FR-0733RL
CAP CER 4.7UF 6.3V X7R 0603 | 1 | C16 | Yageo | CC0603MRX7R5BB475
RES SMD 49.9 OHM 1% 1/16W 0402 | 4 | R10, R11, R13, R14 | Yaego | RC0402FR-0749R9L
CAP CER 6800PF 50V X7R 0402 | 2 | C12, C13 | Yageo | CC0402KRX7R9BB682
IC ADC 16BIT SIGMA-DELTA 10VSSOP | 1 | U2 | Texas Instruments | ADS1115IDGST
SENSOR PRESSURE HUMIDITY TEMP | 1 | IC1 | Bosch | BME280
SENSOR PRES 1PSI DIFF 3V DIGITAL | 1 | PRESSURE1 | Honeywell | HSCDRRT001PD2A3
CONN MAGJACK 1PORT 100 BASE-T | 1 | T1 | Würth Elektronik | 7499210121A
CONN JACK MONO 3.5MM R/A | 1 | J4 | CUI Devices | MJ-3536N
LED RED CLEAR SMD | 1 | D1 | Lite-On Inc. | LTST-C191KRKT
IC CTLR 3-1 ETH TCP/IP 48LQFP | 1 | U1 | WIZnet | W5500

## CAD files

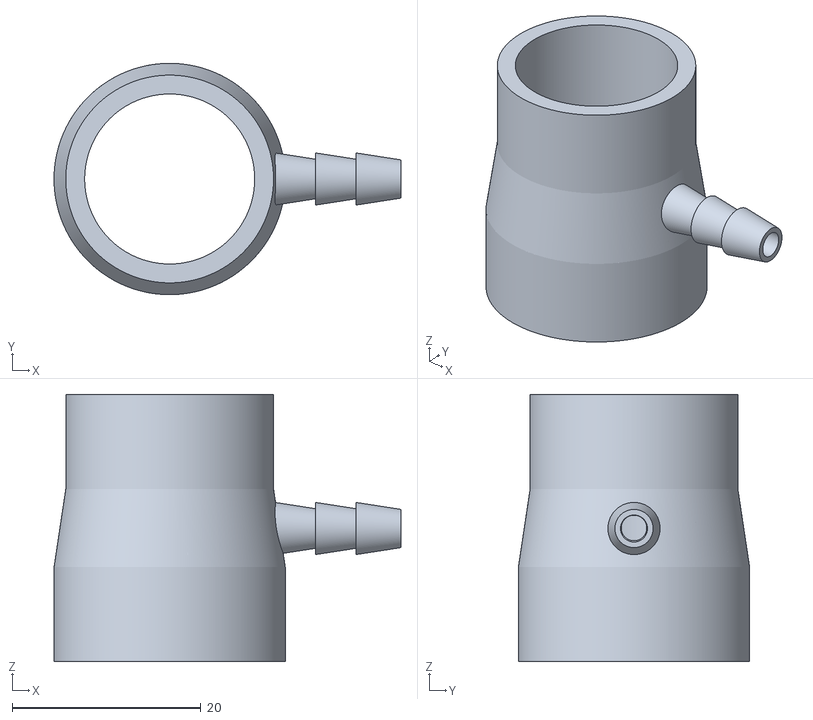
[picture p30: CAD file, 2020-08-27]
design/3dparts/PressureCoupling.stl
36.8 x 24.5 x 28.3

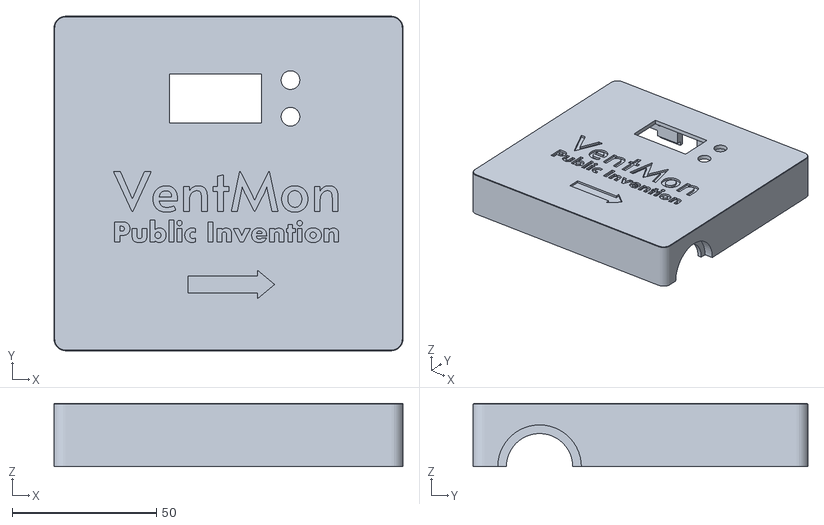
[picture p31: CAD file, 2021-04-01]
design/3dparts/T0.4/VentMon Top V0.48.stl
121.0 x 116.0 x 22.0

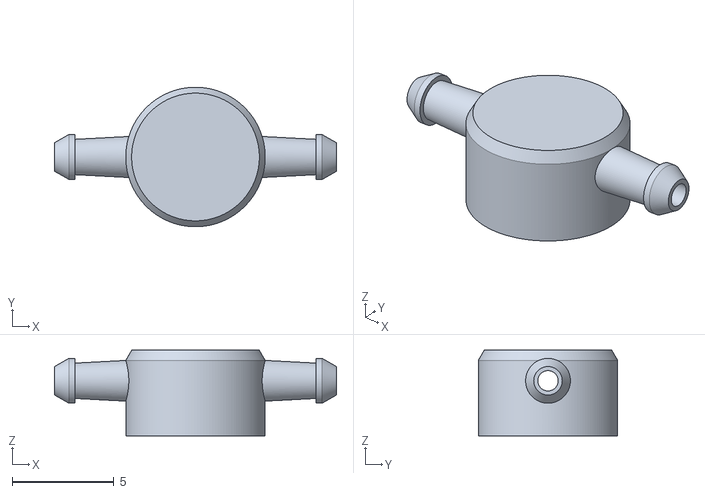
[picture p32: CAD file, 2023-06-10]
design/3dparts/T0.5/Manifold_T0.5.55.stl
13.9 x 6.85 x 4.20

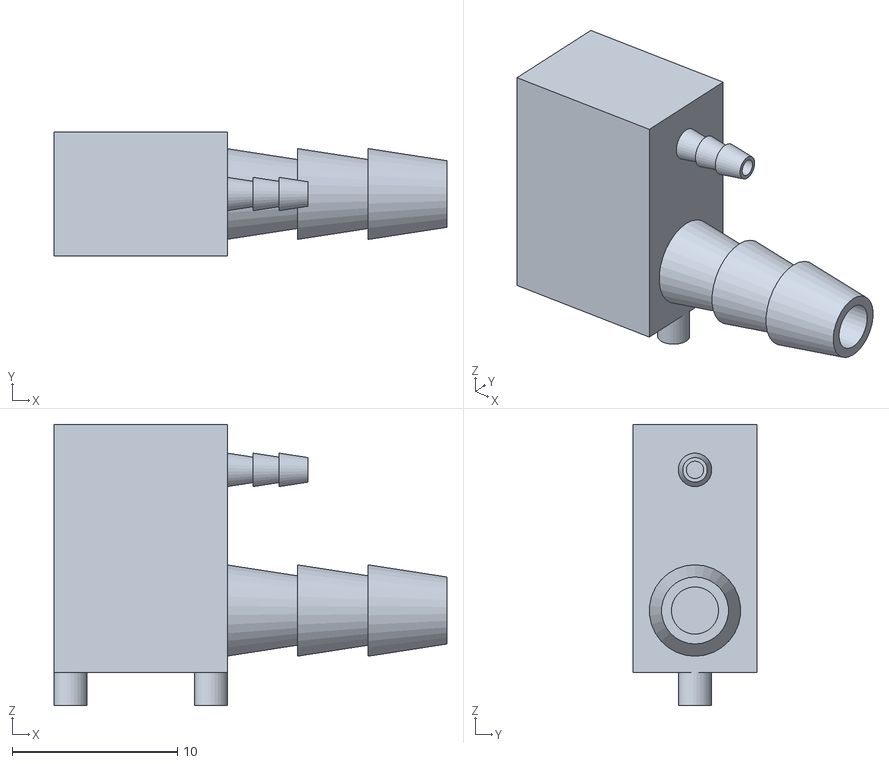
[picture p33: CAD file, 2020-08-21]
design/3dparts/bme280_hat_two_port.stl
23.8 x 7.50 x 17.0

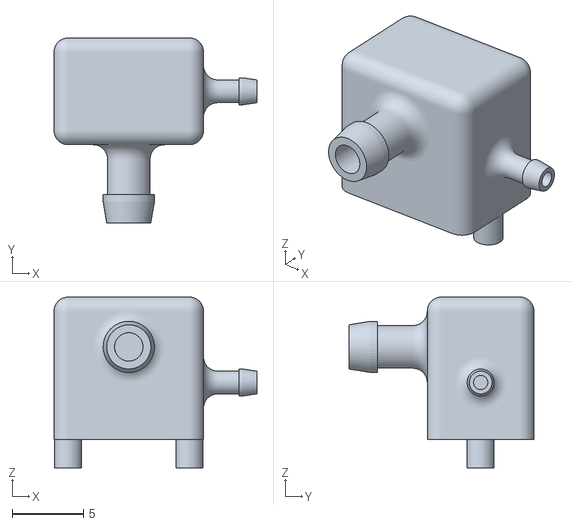
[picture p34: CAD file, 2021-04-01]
design/3dparts/T0.4/BME Hat.stl
14.2 x 13.0 x 12.0

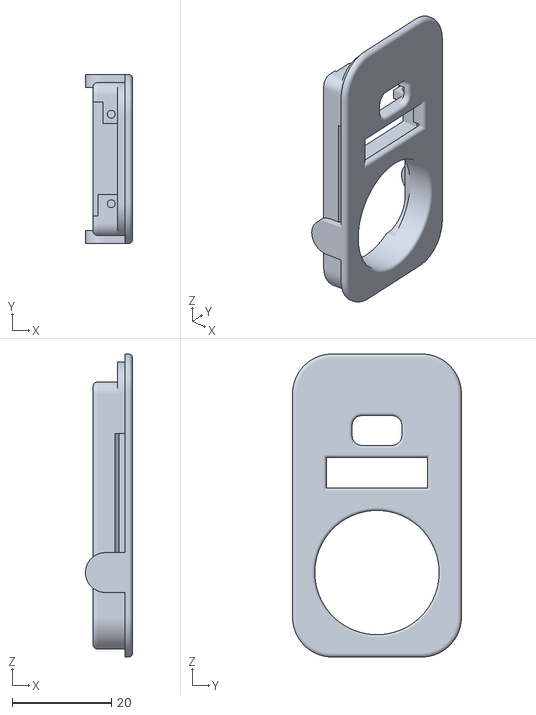
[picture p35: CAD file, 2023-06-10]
design/3dparts/T0.5/Cap_T0.5.66.stl
9.50 x 34.0 x 61.0

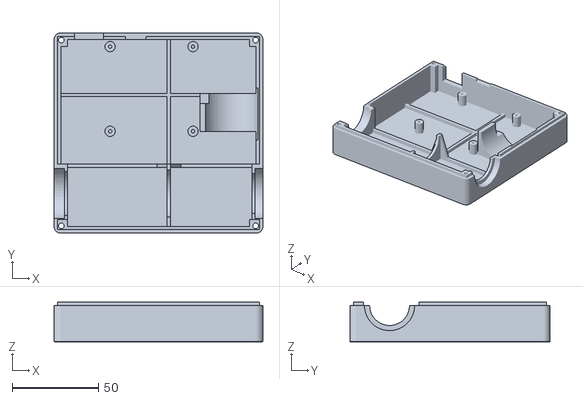
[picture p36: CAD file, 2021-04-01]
design/3dparts/T0.4/VentMon Bottom V0.48.stl
121.0 x 116.0 x 23.0

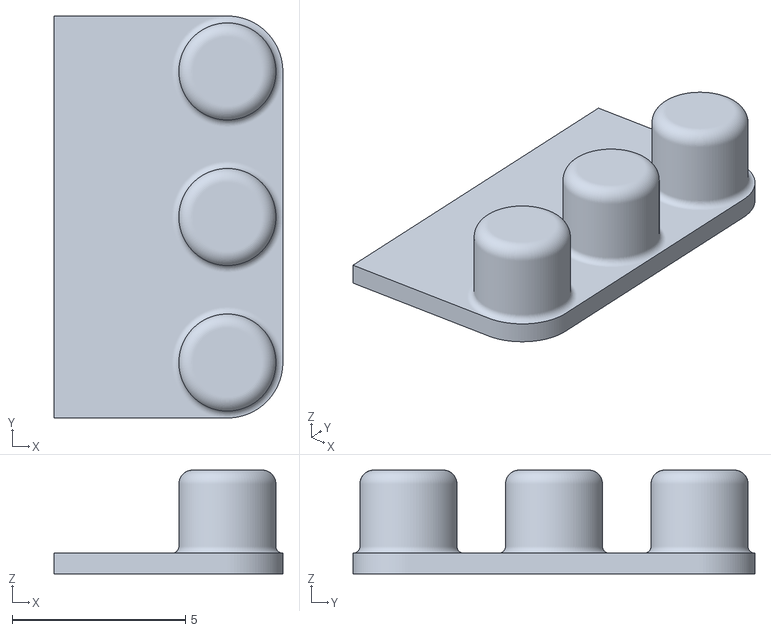
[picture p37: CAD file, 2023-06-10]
design/3dparts/T0.5/Buttons_T0.5.54.stl
6.60 x 11.6 x 3.00

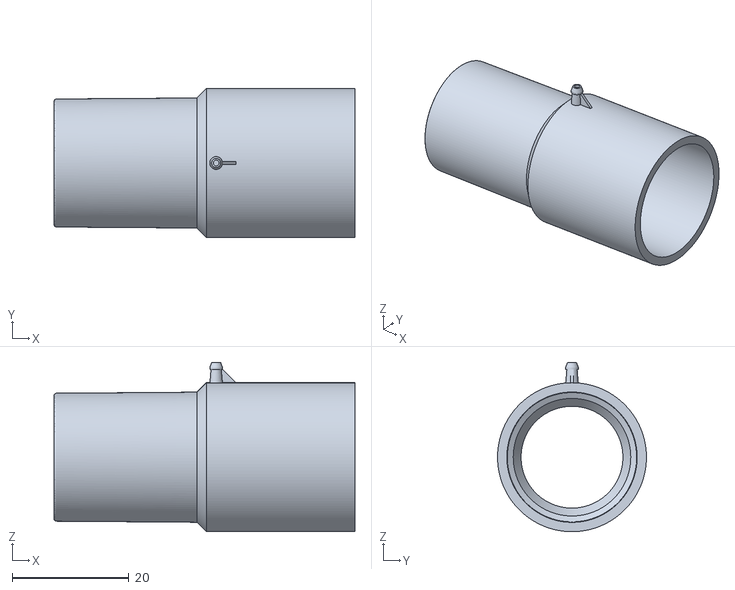
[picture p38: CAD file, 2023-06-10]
design/3dparts/T0.5/Nozzle_T0.5.66.stl
51.6 x 25.5 x 29.0

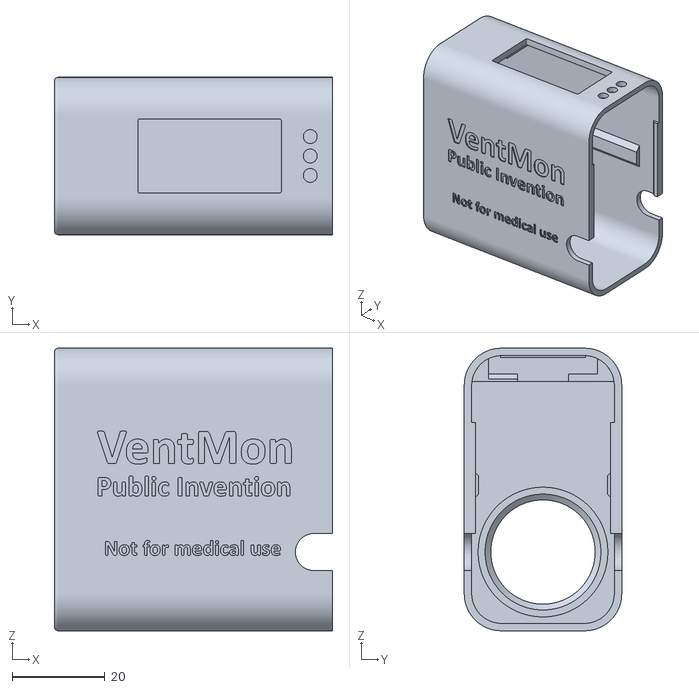
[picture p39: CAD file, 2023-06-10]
design/3dparts/T0.5/Case_T0.5.48.stl
60.0 x 34.0 x 61.0

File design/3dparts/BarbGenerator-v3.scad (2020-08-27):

// Number of hose inputs - which is input and which is output doesn't matter but the input will be on the bottom of the print so should be the larger of the two
inputs = 1;
// Number of hose outputs
outputs = 1;
//  Measurement system for inputs - US in inches, Metric in mm
input_units = "US"; // [US,Metric]
// Measurement system for outputs
output_units = "US"; // [US,Metric]
// Input tubing inside diameter, e.g. 0.5 for 1/2 inch (US); 0.625 for 5/8, 0.75 for 3/4, etc
input_size = 0.25;
// Output tubing inside diameter, e.g. 0.17 for 1/4 inch OD (outside diameter) vinyl tubing (US); 0.25 for 1/4 inch ID (inside diameter) (US); 0.375 for 3/8 inch ID
output_size = 0.25;
// Connector type - Use inline for a single input and single output
connector_type = "inline"; // [inline,vault]
// Inline junction type - currently only round is supported
inline_junction_type = "round"; // [round,hex,none]


/* [Manifold] */

// Vault wall thickness in mm - increase for higher pressure connections
vault_wall_thickness = 3.0;
// Add support under vault for printing
vault_support = "yes"; // [yes,no]
// Ratio of connector diameter to space allocated in vault - increase to allow more space for hose clamps, etc.
vault_connector_ratio = 1.8;

/* [Advanced] */

// Width of junction as ratio of tubing I.D.
inline_junction_width = 0.8;
// Strength factor - use more than 1 for thicker walls to handle higher pressure and stronger clamping
strength = 3.0;
// Number of barbs on input - use 3 for larger tubing to reduce overall print height
input_barb_count = 3;
// Number of barbs on output - use 4 for smaller tubing
output_barb_count = 3;

/* [Hidden] */
inches_to_mm = 25.400;

make_adapter( input_units == "US" ? input_size * inches_to_mm : input_size, output_units == "US" ? output_size * inches_to_mm : output_size );

module make_adapter( input_diameter, output_diameter )
{

if (connector_type == "inline" && inputs == 1 && outputs == 1)
{
  assign ( junction_height = input_barb_count )
  {
    union() {
      input_barb( input_diameter );
      junction( input_diameter, output_diameter, junction_height );
      output_barb( input_diameter, output_diameter, junction_height );
    }
  }
}
if (connector_type == "vault" || inputs > 1 || outputs > 1)
{
  assign( center_width = max(inputs * input_diameter * vault_connector_ratio, outputs * output_diameter * vault_connector_ratio), center_height = max(input_diameter * vault_connector_ratio, output_diameter * vault_connector_ratio), junction_height = input_barb_count )
  {
   assign( center_empty_input = center_width - input_diameter * vault_connector_ratio * inputs, center_empty_output = center_width - output_diameter * vault_connector_ratio * outputs )
   {
     union() {
       //input_barb( input_diameter );
       for (i = [1:inputs]) 
	    {
		   translate( [center_empty_input / 2 + input_diameter * vault_connector_ratio / 2 + input_diameter * (i-1) * vault_connector_ratio,0,0] ) input_barb( input_diameter );
	    }
		 //echo( "inputs=", inputs, "; input_diameter=", input_diameter, "; outputs=", outputs, "; output_diameter=", output_diameter );
		 //echo( "center_width=", center_width, "; by input=", inputs * input_diameter * vault_connector_ratio, "; by output=", outputs * output_diameter * vault_connector_ratio, "; center_empty_input=", center_empty_input, "; center_empty_output=", center_empty_output );
		 difference()
		 {
			translate([-vault_wall_thickness,-vault_wall_thickness,0]) vault( input_diameter, junction_height, center_width, center_height, center_height, vault_wall_thickness );
			for (i = [1:inputs]) 
			{
				// Make holes in the vault for input entry
      		translate( [center_empty_input / 2 + input_diameter * vault_connector_ratio / 2 + input_diameter * (i-1) * vault_connector_ratio,0,input_diameter * input_barb_count * 0.9 - center_height / 3] ) cylinder( r=input_diameter * 0.36, h=center_height );
			}
			for (i = [1:outputs]) 
			{
				// Make holes in the vault for output egress
      		translate( [center_empty_output / 2 + output_diameter * vault_connector_ratio / 2 + output_diameter * (i-1) * vault_connector_ratio,0,input_diameter * input_barb_count * 0.9 + center_height / 2] ) cylinder( r=output_diameter * 0.36, h=center_height );
			}
		 } // end vault with holes
       //output_barb( input_diameter, output_diameter, 12 );
	    for (i = [1:outputs]) 
		 {
			translate( [center_empty_output / 2 + output_diameter * vault_connector_ratio / 2 + output_diameter * (i-1) * vault_connector_ratio,0,-output_diameter * 0.3] ) output_barb( input_diameter, output_diameter, center_height + 2 * vault_wall_thickness );
		 }
     }
	}
  }
}
}

/****
module tometric( unit_type, value )
{
  if (unit_type == "US") value * 25.4;
  else value;
}
***/

module barbnotch( inside_diameter )
{
  // Generate a single barb notch
  cylinder( h = inside_diameter * 1.0, r1 = inside_diameter * 0.85 / 2, r2 = inside_diameter * 1.16 / 2, $fa = 0.1, $fs = 0.1 );
}

module solidbarbstack( inside_diameter, count )
{
    union() {
      barbnotch( inside_diameter );
		for (i=[2:count]) 
		{
			translate([0,0,(i-1) * inside_diameter * 0.9]) barbnotch( inside_diameter );
		}
		/***
		if (count > 1) translate([0,0,1 * inside_diameter * 0.9]) barbnotch( inside_diameter );
		if (count > 2) translate([0,0,2 * inside_diameter * 0.9]) barbnotch( inside_diameter );
		***/
    }
}

module barb( inside_diameter, count )
{
  // Generate 4 barbs
  difference() {
    solidbarbstack( inside_diameter, count );
      // WARNING: Changing this....
//    translate([0,0,-0.3]) cylinder( h = inside_diameter * (count + 1), r = inside_diameter * 0.75 / 2, $fa = 0.5, $fs = 0.5 );
      translate([0,0,-0.3]) cylinder( h = inside_diameter * (count + 1), r = inside_diameter * 0.6 / 2, $fa = 0.1, $fs = 0.1 );
  }
}

module input_barb( input_diameter )
{
  barb( input_diameter, input_barb_count );
}

module output_barb( input_diameter, output_diameter, jheight )
{
  translate( [0,0,input_diameter * input_barb_count * 0.9 + output_diameter * output_barb_count * 0.9 + jheight + 1] ) rotate([0,180,0]) barb( output_diameter, output_barb_count );
}

module junction( input_diameter, output_diameter, jheight )
{
    holeD=input_diameter >= output_diameter ? output_diameter : input_diameter;
  junction_diameter_ratio = (inline_junction_type == "none") ? 1.1 : 1.6;
  translate( [0,0,input_diameter * jheight * 0.9] ) difference() {
	cylinder( r = max(input_diameter, output_diameter) * junction_diameter_ratio / 2, h = 5, $fa = 0.1, $fs = 0.1 );
	cylinder( r1 = input_diameter / 2, r2 = output_diameter / 2, h = (jheight + 1), $fa = 0.1, $fs = 0.1 );
//    cylinder(r=holeD/2, h=jheight*2*5, center=true);
      // WARNING!!! THIS HAS BEEN CHANGED for my specific situation
    cylinder(r=holeD/4, h=jheight*2*5, center=true,  $fn = 30);
  }
}

module vault( input_diameter, jheight, center_width, center_depth, center_vheight, wall_thickness )
{
  assign( outside_width = center_width + 2 * wall_thickness, outside_depth = center_depth + 2 * wall_thickness, outside_vheight = center_vheight + 2 * wall_thickness, vault_base = input_diameter * jheight * 0.9 )
  {
    translate( [0, -outside_depth / 2 + wall_thickness, vault_base - wall_thickness] ) union()
	 {
	   difference() 
      {
        cube( [outside_width,outside_depth,outside_vheight] );
        translate( [wall_thickness,wall_thickness,wall_thickness] ) cube( [center_width, center_depth, center_vheight] );
      }
	   // Add supports if requested
		if (vault_support == "yes")
	   {
		  assign( support_leg_width = center_width / 4, support_leg_thickness = wall_thickness / 2 )
		  {
		  translate([outside_width-support_leg_width,outside_depth-support_leg_thickness,wall_thickness-vault_base]) cube([support_leg_width, support_leg_thickness, vault_base]);
		  translate([outside_width-support_leg_width,0, wall_thickness-vault_base]) cube([support_leg_width, center_depth + wall_thickness*2, 0.6]);
		  translate([0,outside_depth-support_leg_thickness,wall_thickness-vault_base]) cube([support_leg_width,support_leg_thickness, vault_base]);
		  translate([outside_width-support_leg_width,0,wall_thickness-vault_base]) cube([support_leg_width,support_leg_thickness, vault_base]);
		  translate([0,0, wall_thickness-vault_base]) cube([support_leg_width, center_depth + wall_thickness*2, 0.6]);

		  translate([0,0,wall_thickness-vault_base]) cube([support_leg_width, support_leg_thickness, vault_base]);
		  }
		}
    }
  }
}

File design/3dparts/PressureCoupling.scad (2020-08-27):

// This file was origininally written by Stephen Glow and has been
// extensively modified by Robert L. Read.

use <BarbGenerator-v3.scad>;

// This dile describes the geometry of the freeflow venturi tube.
// I have tried to document the various parameters, most of which can be
// changed to adjust tube geometry.
//
// These are just openscad special variables related to rendering.
// They define how many fascets in an arc.  I have them set for pretty high 
// resolution (slow) rendering.  Making these bigger produces faster but 
// rougher renderings
$fa = 1;      // Minimum angle fragment
$fs = .1;     // Minimum size of a fragment

// M for margin.  I use this to make things overlap slightly for better rendering
M = .01;

// These are the X axis offsets of the two pressure sensors from the end of the pcb.
// The sensors are both centered in the Y axis, so I don't include that here.
// These values are correct for the rev-2 freeflow board.
pcb_tap_outer  = in2mm(0.3);
pcb_tap_center = in2mm(1.6);

// Tubing that connects to the venturi outer & inner diameter
tube_od = 22;
tube_id = 18;

// Amount that my venturi will overlap the tube on the enterence.
// I'm using a female enterence and male exit
tube_overlap = 10;

// Thickness of the wall of the overlapping section
overlap_thickness = 1.25;

// The outer diameter of the venturi tube enterence will be the 
// same as the tube_id.  The throat diameter is the inner diameter
// of the constricted throat of the venturi.  Smaller gives larger
// readings, especially at low flow rates, but also causes more
// pressure drop through the tube.
throat_d = tube_id * 0.4;
echo( "throat_d ", throat_d );

// These angles define how quickly the venturi will narrow on 
// both entry and exit.  Angles are relative to the center line
// running through the tube.  These angles are pretty typical for
// venturi tubes according to my research.
angle_entry = 12;
angle_exit = 7;

// The exit of the venturi will have the same inner/outer diameter 
// as the tube that attaches to the entry.  I'm assuming that a fitting
// sized for that tube will be connected to the exit end
exit_id = tube_id;
exit_od = tube_od;

// Find the entry and exit distance based on the change of diameter
// and the angles.  
Lnarrow = (tube_id - throat_d)/2 / tan(angle_entry);
Lexpand  = (exit_id - throat_d)/2 / tan(angle_exit);

// This is the length of the exit section.  The fitting attached to the 
// end of the venturi will overlap by up to this much
exit_overlap = 10;

// The length of the throat section is customarily the same as the
// throat diameter
// Hack:
// Lthroat = throat_d;
Lthroat = 0;

// The length of the enterence to the venturi (before it starts to narrow)
// The outer tap is located in this area, so this is somewhat dictated by the PCB dimensions

pcb_dtap = pcb_tap_center - pcb_tap_outer;

Lentry = pcb_dtap - Lnarrow - Lthroat/2 + tube_id/2;

// There will be two holes in the side of the tube where we will sense
// pressure.  This is the diameter of those holes
tap_d = 2.7;

module CouplerWTap() {
    difference() {
        Coupler();
        TapHole();
    }
}



// This module is the venturi tube itself without the board mount
module Coupler()
{
   // This is the Z offset of the bottom of the PCB relative to the bottom of the tube
   pcb_zoff = tube_overlap+Lentry+Lnarrow+Lthroat/2-pcb_tap_center;

   // OK, build the venturi tube.
   difference()
   {
      // This section is the outer shell of the venturi tube.
      union()
      {

         // This first section is the area in which the venturi tube overlaps
         // the tubing that connects to it.
         cylinder( d=tube_od+2*overlap_thickness, h=tube_overlap );

          L = Lentry/2;
         translate( [0,0,tube_overlap-M] )
            cylinder( d1=tube_od+2*overlap_thickness, d2=exit_od, h=L+M );

         // This last section is the outer part of the section which will fit
         // into the fitting 
         translate( [0,0,tube_overlap+L-M] )
            cylinder( d=exit_od, h=exit_overlap+M );
      }

      // Everything after here is removed from that outer shell.

      // This is the area in which the external tube will enter
      translate( [0,0,-M] ) 
         cylinder( d=tube_od, h=tube_overlap+M );

      // This is the outer section of the venturi.
      // The outer tap will end up in the center of this section.
      translate( [0,0,tube_overlap-M] ) 
         cylinder( d=tube_id, h=Lentry+M );

      // This is the narrowing entry part
      translate( [0,0,tube_overlap+Lentry-M] ) 
         cylinder( d1=tube_id, d2=tube_id, h=Lnarrow+M );

   }
}

module TapHole() 
{  
   //pcb_zoff = tube_overlap+Lentry+Lnarrow+Lthroat/2-pcb_tap_center;
          // Add a hole for the outer pressure sensor tap
    L = Lentry/2;
    z = tube_overlap +L/2;
      translate( [0,0,z] )
         rotate( [0,90,0] ) cylinder( d=tap_d, h=tube_od );

}

function in2mm(x) = x*25.4;

CouplerWTap();


/* [Hidden] */
inches_to_mm = 25.400;

// Input tubing inside diameter, e.g. 0.5 for 1/2 inch (US); 0.625 for 5/8, 0.75 for 3/4, etc
input_size = 3/16;
// Output tubing inside diameter, e.g. 0.17 for 1/4 inch OD (outside diameter) vinyl tubing (US); 0.25 for 1/4 inch ID (inside diameter) (US); 0.375 for 3/8 inch ID
output_size = input_size;

output_size_mm = output_size*25.4;

//p_input_size = 0.06889764;
//p_output_size = 0.06889764;

p_input_size = 0.06889764;
p_output_size = p_input_size;

p_output_size_mm = p_output_size*25.4;

barbLength = 7;
barbHeight = 7;
outerBarbRadius = 1.93;
innerBarbRadius = outerBarbRadius - 1;

// Number of hose inputs - which is input and which is output doesn't matter but the input will be on the bottom of the print so should be the larger of the two
inputs = 1;
// Number of hose outputs
outputs = 1;
//  Measurement system for inputs - US in inches, Metric in mm
input_units = "US"; // [US,Metric]
// Measurement system for outputs
output_units = "US"; // [US,Metric]
// Input tubing inside diameter, e.g. 0.5 for 1/2 inch (US); 0.625 for 5/8, 0.75 for 3/4, etc
input_size = 3/16;
// Output tubing inside diameter, e.g. 0.17 for 1/4 inch OD (outside diameter) vinyl tubing (US); 0.25 for 1/4 inch ID (inside diameter) (US); 0.375 for 3/8 inch ID
output_size = 3/16;
// Connector type - Use inline for a single input and single output
connector_type = "inline"; // [inline,vault]
// Inline junction type - currently only round is supported
inline_junction_type = "round"; // [round,hex,none]

translate([tube_od+2.5,0,14.1])
rotate([0,270,0])
input_barb( input_units == "US" ? input_size * inches_to_mm : input_size );
    

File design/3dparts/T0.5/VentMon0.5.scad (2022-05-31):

/////////////////////////////////////////
///// VentMon 0.5 Mechanical Design /////
/////     Public Invention 2022     /////
/////          Ben Coombs           /////
/////////////////////////////////////////

tol=0.01;

//////////// Housing ////////////

w = 30;
h = 55;
d = 60;
wt = 2;

case_nozzle_cutout_diameter = 22;
endcap_nozzle_cutout_diamater = 22;
airway_center_z = -12;

// Shell
union() {
    difference() {
        cube([w, d, h], center=true);

        translate([0,1.01,0])
        cube([w-2*wt, d-wt, h-2*wt], center=true);

        // Side cutout (temporary)
        translate([2.01,0,0])
        cube([w-2*wt, d-2*wt, h-2*wt], center=true);
        
        // Display cutout
        translate([0,2,h/2-wt/2])
        cube([16,35,4], center=true);
        
        // Nozzle cutout
        translate([0,-d/2+wt/2,airway_center_z])
        rotate([90,0,0])
        cylinder(h=10, d=case_nozzle_cutout_diameter, center=true);
        
    }
}

temp_endcap_move = 0;

// End cap
color("red")
translate([0,temp_endcap_move,0])
difference() {
    union()
    {
        // End cap
        translate([0,d/2+wt/2,0])
        cube([w, wt, h], center=true);
        
        // End cap inner lip
        difference() {
            translate([0,d/2-wt/2,0])
            cube([w-wt*2-0.5, wt, h-wt*2-0.5], center=true);
            translate([0,d/2-wt/2-tol,0])
            cube([w-wt*4, wt, h-wt*2-4], center=true);
        }
                
        // PCB mounts
        translate([w/2-6,27,10.5])
        cube([6,6,8], center=true);
        translate([-w/2+6,27,10.5])
        cube([6,6,8], center=true);
        
        translate([w/2-6,27,19.5])
        cube([6,6,8], center=true);
        translate([-w/2+6,27,19.5])
        cube([6,6,8], center=true);
    }
    
    // USB port cutout
    translate([0,d/2,18])
    cube([10,8,7], center=true);
        
    // Flow sensor cutout
    translate([0,d/2,airway_center_z])
    rotate([90,0,0])
    cylinder(h=6, d=endcap_nozzle_cutout_diamater, center=true);
}

//////////// Flow Sensor ////////////

color("lightgrey")
translate([0,temp_endcap_move+20,airway_center_z])
flow_sensor();

module flow_sensor() {
    id = 10;
    t = 1;
    x = 50;
        
    translate([0,-x/2,0])
    rotate([270,0,0])
    rotate_extrude()
    polygon([[id,0], [id,20],[id+t,20],[id+t,x],
            [id+2*t,x],[id+2*t,19],[id+t,19],[id+t,0]]);
    
    translate([0,0,id])
    cube([12,20,5], center=true);
}

//////////// Nozzle ////////////

color("lightblue")
translate([0,-25,airway_center_z])
nozzle();

module nozzle() {
    id = 10;
    t = 1;
    x = 40;
        
    translate([0,-x/2,0])
    rotate([270,0,0])
    rotate_extrude()
    polygon([[id,0], [id,x/2],[id+t,x/2],[id+t,x],
            [id+2*t,x],[id+2*t,x/2-t],[id+t,x/2-t],[id+t,0]]);
}

//////////// PCB ////////////

module feather_pcb() {
    pcb_length = 50.4;
    pcb_width = 22.9;
    color("green")
    cube([pcb_width,pcb_length,1], center=true);
}

module header(num_pins) {
    header_width = 2.5;
    header_height = 8.5;
    header_length = 2.54 * num_pins + 0.25;
    color("black")
    cube([header_width, header_length, header_height], center=true);
}

// PCB stack
translate([0,temp_endcap_move+4,15])
{
    // Top
    translate([0,0,9]) {
        feather_pcb();
        // OLED
        color("black")
        translate([0,-2,1])
        cube([16,35,2], center=true);
        // OLED buttons
        color("grey"){
            translate([0,20,1.5])
            cube([3,3,3], center=true);
            translate([-5,20,1.5])
            cube([3,3,3], center=true);
            translate([5,20,1.5])
            cube([3,3,3], center=true);
        }
    }
    
    // Mid
    feather_pcb();
    translate([10,-5,4.25])
    header(12);
    translate([-10,0,4.25])
    header(16);
    // USB port
    color("grey")
    translate([0,22,2])
    cube([7,7,3], center=true);
    
    // Bottom
    translate([0,0,-9])
    feather_pcb();
    translate([10,-5,4.25-9])
    header(12);
    translate([-10,0,4.25-9])
    header(16);
}

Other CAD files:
design/3dparts/bme280_hat.scad

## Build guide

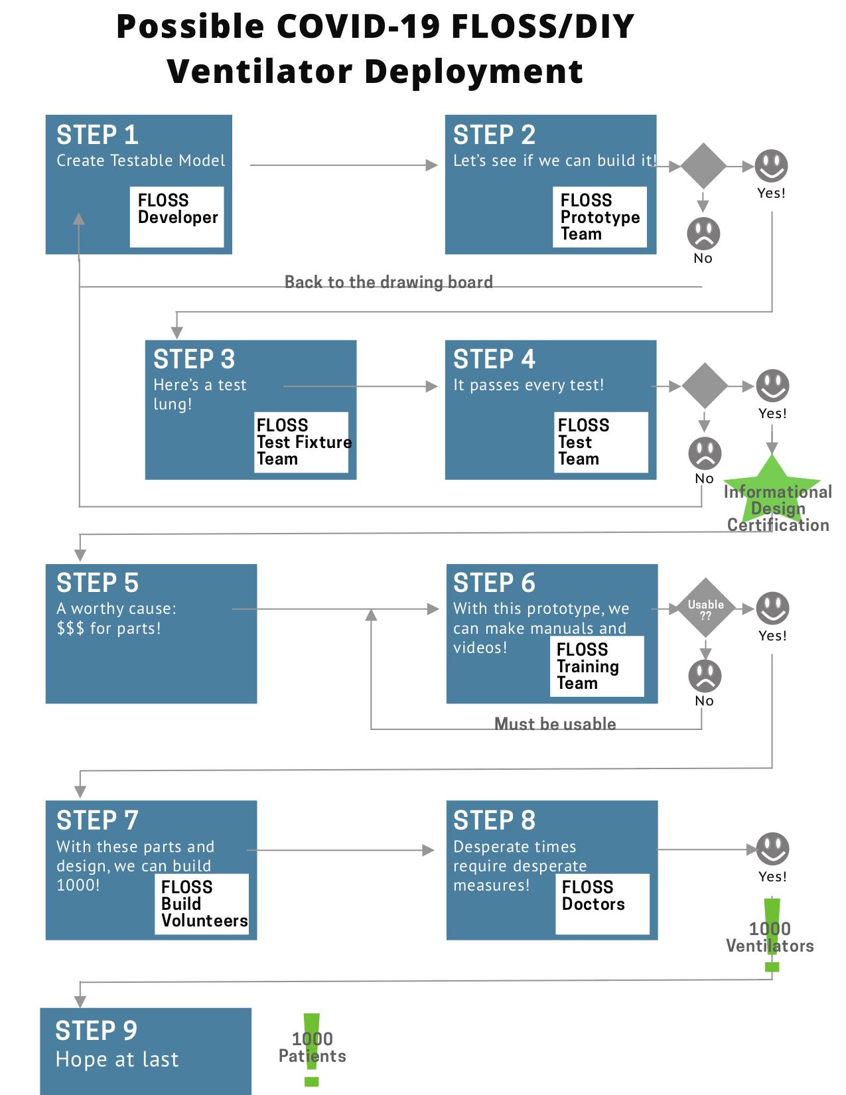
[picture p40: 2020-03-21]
FLOSS Build Model.png

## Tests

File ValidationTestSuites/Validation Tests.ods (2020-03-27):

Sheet: Test Cases
Number | Name | Description | Verification Method | Expected Results | Tolerance | Test Result | Pass | Fail | Tester ID | Test Date | Device ID | RMVS | RMSV(O) | BofL
Draft v0.1 - March 25th
By Public Invention, in cooperation with BreathOfLife and Jonathan Orban
Licensed under CC0; consider a template to copy and extend
Copyright Robert L. Read, Juan E Villacres Perez, Jonathan Orban and others 2020
Note: primary source is UK Rapid Manufactered Ventilator System (1)
Primary Point of Contact: Robert L. Read, PhD <read.robert@gmail.com>
Connection
1 | CON1 | Electrical connection | Instruct CLI to connect system to ventilator | They can in 15 seconds | 60 seconds |  | 0 | 0 |  |  |  | 1 | 1
2 | CON2 | Oxygen connection | Instruct CLI to connect O2 supply to ventilator | They can in 60 seconds | 90 seconds |  | 0 | 0 |  |  |  | 1 | 1
3 | CON3 | Replace Batteries | Instruct CLI to replace batteries | They can in 5 minutes | 10 minutes |  | 0 | 0 |  |  |  | 1 | 1
4 | CON4 | Endotracheal tube connection | Instruct CLI to connect endotracheal tube (in-situ) to ventilator | They can in 45 seconds | 60 seconds |  | 0 | 0 |  |  |  | 1 | 1
5 | CON5 | Humidifier connection | Instruct CLI to connect humidifier to ventilator | They can in 60 seconds | 90 seconds |  | 0 | 0 |  |  |  | 0 | 1
6 | CON6 | Inlet and outlet separated by 10cm | Measure distance. | At least 10 cm | none |  | 0 | 0 |  |  |  | 0 | 1
7 | CON7 | Male inlet and outlet ports provide clearance | Check inlet and outputs clear in 5cm circle from center | At least 5cm circle | none |  | 0 | 0 |  |  |  | 1 | 1
Startup
2 | SUP2 | Mandatory Mode on Power-Up | On initial power-up, system enters mandatory mode and begins working | Mandatory mode operating with respiration rate = DRATE and volume = DVOL and |  |  | 0 | 0 |  |  |  | 1 | 1
3 | SUP3 | Volume Control begins correct | On power-up, ask CLI what volume is produced, and ask if it is being produced. | CLI answere 400 ml and V produced 400ml | 20ml? |  | 0 | 0 |  |  |  | 1 | 1
4 | SUP4 | Respiration Rate Standard | On power-up, check respiration rate, measure total respirations per minute | Respiration rate = DRATE, or persistent Respiration Rate, or match control setting if tied to knobs | 1 rpm? |  | 0 | 0 |  |  |  | 1 | 1
5 | SUP5 | I:E ratio corrects | On power-up estimate inspiration and expiration absolute times in tenths of seconds (w/ stopwatch), comptue I:E ratio | I:E ratio = DIERATIO, or remebered setting, or physical setting | 0.1 |  | 0 | 0 |  |  |  | 1 | 1
6 | SUP6 | Mode | On power-up, in mandatory mode, or persistent mode if that is a feature | Yes | none |  | 0 | 0 |  |  |  | 1 | 1
Inspiratory Airway Pressure (Volume Control Mode)
1 | INSP1 | IA Pressure limit functions | Ask CLI to adjust IA pressure to 40 cm H2O | After 120 seconds, IA pressure at most 40cmH20 | 2 cm H2O |  | 0 | 0 |  |  |  | 1 | 1
2 | INSP2 | IA Pressure adjustable | Ask CLI to adjust IA pressure to 15, 20, 25, 30, 35 cmH2O | After each reset, IA pressure limited got configuration (test pressure 60 seconds) |  |  | 0 | 0 |  |  |  | 1 | 1
3 | INSP3 | IA Failsafe | Cough, blow, or increase pressure by striking bag representing patient | Observe that failsafe valve opens and that pressure does not exceed 80 cm H2O | 4 cm H2O? |  | 0 | 0 |  |  |  | 1 | 1
3 | INSP4 | IA Failsafe, machine cycle | Repeat INSP3 on various machine extreme rate and volume settings | Observe that failsafe valve opens and that pressure does not exceed 80 cm H2O | 4 cm H2O? |  | 0 | 0 |  |  |  | 1 | 1
PEEP | (PEEP may be implement by separate external valve. Consider separate part to be part of V for purpose of test)
1 | PEEP1 | PEEP is understandable | Ask CLI to explain how to adjust PEEP | They correctly explain |  |  | 0 | 0 |  |  |  | 1 | 1
2 | PEEP2 | LOW PEEP | Ask CLI to adjust PEEP to 5cmH2O | Within 120 seconds, pressure in airway never drops below 5cmH20 | 1 cmH2O? |  | 0 | 0 |  |  |  | 1 | 1
3 | PEEP3 | Incremental PEEP | Ask CLI To adjust PEEP to 10, 15, and 20 cmH2O | Within 120 seconds, pressure in airway never drops below 5cmH20 | 1 cmH2O? |  | 0 | 0 |  |  |  | 1 | 1
Respiration Rate
1 | RAT1 | Rate | Measure respirations per minute | Matches DIERATE, persistent rate, or physical knobs | 1 rpm |  | 0 | 0 |  |  |  | 1 | 1
2 | RAT2 | Up to 30 rpm | Ask CLI to configure machine for 30 rpm. When they are done, measure rpms. | Within 60 seconds, CLI can configure machine to 30 rpm, and V so performs. | 2 rpm |  | 0 | 0 |  |  |  | 1 | 1
3 | RAT3 | Down to 10 rpm | Ask CLI to configure machine for 10 rpm. When they are done, measure rpms. | Within 60 seconds, CLI can configure machine to 10 rpm, and V so performs. | 2 rpm |  | 0 | 0 |  |  |  | 1 | 1
4 | RAT4 | Increments | Ask CLI to configure machine to 22 rpm. When they are done, measure rpms. | Within 120 seconds, CLI can configure machine to 22 rpm, and V so performs. | 2 rpm |  | 0 | 0 |  |  |  | 1 | 1
Tidal Volume
1 | TID1 | 400ml Vt functions | Ask CLI to configure machine to 400ml Tidal Volume (if only setting for machine, ask them to state.) When so set, measure with professional plastic test lung. Observe rise of lunch (measured in mm) to match that of forcing 400ml into lung via syringe or other precise method.) | 400ml | 10ml |  | 0 | 0 |  |  |  | 1 | 1
2 | TID2 | Optional 350 and 450ml setting | Ask CLI to configure machine to 350ml and 450ml Tidal Volume (if only setting for machine, ask them to state.) When so set, measure with professional plastic test lung. Observe rise of lunch (measured in mm) to match that of forcing 400ml into lung via syringe or other precise method.) | 350ml and 450ml | 10ml |  | 0 | 0 |  |  |  | 0 | 1
3 | TID3 | Optional 250 and 600ml range | Ask CLI to configure machine to extremes of range 250ml and 600ml Tidal Volume (if only setting for machine, ask them to state.) When so set, measure with professional plastic test lung. Observe rise of lunch (measured in mm) to match that of forcing 400ml into lung via syringe or other precise method.) | 250ml and 600ml | 10ml |  | 0 | 0 |  |  |  | 0 | 1
4 | TID4 | Highly Optional 800ml | Ask CLI to configure machine to extremes of range 800ml Tidal Volume (if only setting for machine, ask them to state.) When so set, measure with professional plastic test lung. Observe rise of lunch (measured in mm) to match that of forcing 400ml into lung via syringe or other precise method.) | 800ml | 10ml |  | 0 | 0 |  |  |  | 0 | 1
Infection Control
1 | INFC1 | Device can be fully implemented while wearing PPE | Ask CLI to fully connect the system, turn it on, and verify functio | CLI can successfuly execute CON1-7 and SUP1-6 while wearing full PPE including hood |  |  | 0 | 0 |  |  |  | 1 | 1
2 | INFC2 | Parts can be changed/disposed | Ask CLI to change ETT | Within 30 seconds, CLI can remove ETT, dispose of it in appropriate biohazard, and replace it |  |  | 0 | 0 |  |  |  | 1 | 1
3 | INFC3 | Surfaces can be cleaned | Ask CLI to disinfect external surfaces | Within 60 seconds, CLI can disinfect external parts of device |  |  | 0 | 0 |  |  |  | 1 | 1
4 | INFC4 | Seal from aerosol droplets |  |  |  |  | 0 | 0 |  |  |  | 0 | 1
Monitoring
1 | MON1 | Vt verified | Ask CLI to verify Vt | Within 5 seconds, CLI can report set and actual Vt from monitor |  |  | 0 | 0 |  |  |  | 1 | 1
2 | MON2 | PEEP verified | Ask CLI to verify PEEP | Within 5 seconds, CLI can report set and achieved PEEP from monitor |  |  | 0 | 0 |  |  |  | 1 | 1
3 | MON3 | DFiO2 verified | Ask CLI to verify DFiO2 | Within 5 seconds, CLI can report set and achieved FiO2 from monitor |  |  | 0 | 0 |  |  |  | 1 | 1
4 | MON4 | Breathing rate verified | Ask CLI to verify breathing rate | Within 5 seconds, CLI can report patient breathing rate |  |  | 0 | 0 |  |  |  | 1 | 1
5 | MON5 | Airway pressure | Ask CLI to verify airway pressure | Within 5 seconds, CLI can report airway pressure |  |  | 0 | 0 |  |  |  | 1 | 1
6 | MON6 | CO2 verified | Ask CLI to verify CO2 | Within 5 seconds, CLI can report patient expiratory CO2 |  |  | 0 | 0 |  |  |  | 0 | 1
7 | MON7 | Real-time patient breath verified | Ask CLI to verify last patient breath | Within 5 seconds, CLI can report last patient breath in real-time |  |  | 0 | 0 |  |  |  | 1 | 1
Alarm
1 | ALA1 | Device power failure | Instruct CLI to cut power to the device without proper shut off protocol | Alarm is immediately set off |  |  | 0 | 0 |  |  |  | 1 | 1
2 | ALA2 | Pressure limit exceeded | Instruct CLI to forcibly add pressure exceeding 40cm H20 | Alarm is set off after 3 seconds | 2 seconds |  | 0 | 0 |  |  |  | 1 | 1
3 | ALA3 | Oxygen supply failure | Instruct CLI to disconnect oxygen supply | Alarm is set off after 5 seconds | 5 seconds |  | 0 | 0 |  |  |  | 1 | 1
4 | ALA4 | Patient breath below acceptable range | Instruct CLI to block ETT | Alarm is set off after 3 seconds | 2 seconds |  | 0 | 0 |  |  |  | 1 | 1
5 | ALA5 | Hypercapnia |  |  |  |  | 0 | 0 |  |  |  | 0 | 1
6 | ALA6 | PEEP failure | Instruct CLI to set PEEP and unplug ETT at end of exhalation cycle | Alarm is set off after 2 seconds | 1 second |  | 0 | 0 |  |  |  | 1 | 1
7 | ALA7 | IA pressure failure | Instruct CLI to set IA pressure and unplug ETT during inspiration cycle | Alarm is set off after 2 seconds | 1 second |  | 0 | 0 |  |  |  | 1 | 1
8 | ALA8 | Vt not achieved |  |  |  |  | 0 | 0 |  |  |  | 1 | 1
9 | ALA9 | Vt exceeded |  |  |  |  | 0 | 0 |  |  |  | 1 | 1

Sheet: References
 | Important Reference Documents
Reference #
1 | Rapidly Manufactured Ventilator System | https://assets.publishing.service.gov.uk/government/uploads/system/uploads/attachment_data/file/874279/RMVS001_Rapidly_Manufactured_Ventilator_Specification__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
 | These are different internatinal standards, each of which may drive a test, and may overlap or even conflit. The colum in the table says which standard comes from where.
Standards | Name | Defining document or repo | Notes
 | RMVS | ref(1), British | This standard has optional elements we will denote RMVS(O).
Draft v0.1 - March 25th
By Public Invention, in cooperation with BreathOfLife and Jonathan Orban
Licensed under CC0; consider a template to copy and extend
Copyright Robert L. Read, Juan E Villacres Perez, Jonathan Orban and others 2020
Note: primary source is UK Rapid Manufactered Ventilator System (1)
Primary Point of Contact: Robert L. Read, PhD <read.robert@gmail.com>

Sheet: Abbreviations
Abbreviations | Definition
CLI | Clinician (Doctor, nurse, respiratory therapist)
DTIDVOL | Default Tidal Volume
DRATE | Default Respiratory Rate
DFiO2 | Default Fraction of Inspired Oxygen
V | Ventilator
rpm | respirations per minute
IA | Inspiratory Airway
Vt | Tidal Volume
ETT | Endotracheal Tube
DIERATIO | Default Inspiration / Expiration Ratio
Draft v0.1 - March 25th
By Public Invention, in cooperation with BreathOfLife and Jonathan Orban
Licensed under CC0; consider a template to copy and extend
Copyright Robert L. Read, Juan E Villacres Perez, Jonathan Orban and others 2020
Note: primary source is UK Rapid Manufactered Ventilator System (1)
Primary Point of Contact: Robert L. Read, PhD <read.robert@gmail.com>

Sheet: Version and Contact Info
Draft v0.1 - March 25th
By Public Invention, in cooperation with BreathOfLife and Jonathan Orban
Licensed under CC0; consider a template to copy and extend
Copyright Robert L. Read, Juan E Villacres Perez, Jonathan Orban and others 2020
Note: primary source is UK Rapid Manufactered Ventilator System (1)
Primary Point of Contact: Robert L. Read, PhD <read.robert@gmail.com>
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

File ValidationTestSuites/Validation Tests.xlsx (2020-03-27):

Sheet: Test Cases
Number | Name | Description | Verification Method | Expected Results | Tolerance | Test Result | Pass | Fail | Tester ID | Test Date | Device ID | RMVS | RMSV(O) | BofL
Draft v0.1 - March 25th
By Public Invention, in cooperation with BreathOfLife and Jonathan Orban
Licensed under CC0; consider a template to copy and extend
Copyright Robert L. Read, Juan E Villacres Perez, Jonathan Orban and others 2020
Note: primary source is UK Rapid Manufactered Ventilator System (1)
Primary Point of Contact: Robert L. Read, PhD <read.robert@gmail.com>
Connection
1 | CON1 | Electrical connection | Instruct CLI to connect system to ventilator | They can in 15 seconds | 60 seconds |  | FALSE | FALSE |  |  |  | TRUE | TRUE
2 | CON2 | Oxygen connection | Instruct CLI to connect O2 supply to ventilator | They can in 60 seconds | 90 seconds |  | FALSE | FALSE |  |  |  | TRUE | TRUE
3 | CON3 | Replace Batteries | Instruct CLI to replace batteries | They can in 5 minutes | 10 minutes |  | FALSE | FALSE |  |  |  | TRUE | TRUE
4 | CON4 | Endotracheal tube connection | Instruct CLI to connect endotracheal tube (in-situ) to ventilator | They can in 45 seconds | 60 seconds |  | FALSE | FALSE |  |  |  | TRUE | TRUE
5 | CON5 | Humidifier connection | Instruct CLI to connect humidifier to ventilator | They can in 60 seconds | 90 seconds |  | FALSE | FALSE |  |  |  | FALSE | TRUE
6 | CON6 | Inlet and outlet separated by 10cm | Measure distance. | At least 10 cm | none |  | FALSE | FALSE |  |  |  | FALSE | TRUE
7 | CON7 | Male inlet and outlet ports provide clearance | Check inlet and outputs clear in 5cm circle from center | At least 5cm circle | none |  | FALSE | FALSE |  |  |  | TRUE | TRUE
Startup
2 | SUP2 | Mandatory Mode on Power-Up | On initial power-up, system enters mandatory mode and begins working | Mandatory mode operating with respiration rate = DRATE and volume = DVOL and |  |  | FALSE | FALSE |  |  |  | TRUE | TRUE
3 | SUP3 | Volume Control begins correct | On power-up, ask CLI what volume is produced, and ask if it is being produced. | CLI answere 400 ml and V produced 400ml | 20ml? |  | FALSE | FALSE |  |  |  | TRUE | TRUE
4 | SUP4 | Respiration Rate Standard | On power-up, check respiration rate, measure total respirations per minute | Respiration rate = DRATE, or persistent Respiration Rate, or match control setting if tied to knobs | 1 rpm? |  | FALSE | FALSE |  |  |  | TRUE | TRUE
5 | SUP5 | I:E ratio corrects | On power-up estimate inspiration and expiration absolute times in tenths of seconds (w/ stopwatch), comptue I:E ratio | I:E ratio = DIERATIO, or remebered setting, or physical setting | 0.1 |  | FALSE | FALSE |  |  |  | TRUE | TRUE
6 | SUP6 | Mode | On power-up, in mandatory mode, or persistent mode if that is a feature | Yes | none |  | FALSE | FALSE |  |  |  | TRUE | TRUE
Inspiratory Airway Pressure (Volume Control Mode)
1 | INSP1 | IA Pressure limit functions | Ask CLI to adjust IA pressure to 40 cm H2O | After 120 seconds, IA pressure at most 40cmH20 | 2 cm H2O |  | FALSE | FALSE |  |  |  | TRUE | TRUE
2 | INSP2 | IA Pressure adjustable | Ask CLI to adjust IA pressure to 15, 20, 25, 30, 35 cmH2O | After each reset, IA pressure limited got configuration (test pressure 60 seconds) |  |  | FALSE | FALSE |  |  |  | TRUE | TRUE
3 | INSP3 | IA Failsafe | Cough, blow, or increase pressure by striking bag representing patient | Observe that failsafe valve opens and that pressure does not exceed 80 cm H2O | 4 cm H2O? |  | FALSE | FALSE |  |  |  | TRUE | TRUE
3 | INSP4 | IA Failsafe, machine cycle | Repeat INSP3 on various machine extreme rate and volume settings | Observe that failsafe valve opens and that pressure does not exceed 80 cm H2O | 4 cm H2O? |  | FALSE | FALSE |  |  |  | TRUE | TRUE
PEEP | (PEEP may be implement by separate external valve. Consider separate part to be part of V for purpose of test)
1 | PEEP1 | PEEP is understandable | Ask CLI to explain how to adjust PEEP | They correctly explain |  |  | FALSE | FALSE |  |  |  | TRUE | TRUE
2 | PEEP2 | LOW PEEP | Ask CLI to adjust PEEP to 5cmH2O | Within 120 seconds, pressure in airway never drops below 5cmH20 | 1 cmH2O? |  | FALSE | FALSE |  |  |  | TRUE | TRUE
3 | PEEP3 | Incremental PEEP | Ask CLI To adjust PEEP to 10, 15, and 20 cmH2O | Within 120 seconds, pressure in airway never drops below 5cmH20 | 1 cmH2O? |  | FALSE | FALSE |  |  |  | TRUE | TRUE
Respiration Rate
1 | RAT1 | Rate | Measure respirations per minute | Matches DIERATE, persistent rate, or physical knobs | 1 rpm |  | FALSE | FALSE |  |  |  | TRUE | TRUE
2 | RAT2 | Up to 30 rpm | Ask CLI to configure machine for 30 rpm. When they are done, measure rpms. | Within 60 seconds, CLI can configure machine to 30 rpm, and V so performs. | 2 rpm |  | FALSE | FALSE |  |  |  | TRUE | TRUE
3 | RAT3 | Down to 10 rpm | Ask CLI to configure machine for 10 rpm. When they are done, measure rpms. | Within 60 seconds, CLI can configure machine to 10 rpm, and V so performs. | 2 rpm |  | FALSE | FALSE |  |  |  | TRUE | TRUE
4 | RAT4 | Increments | Ask CLI to configure machine to 22 rpm. When they are done, measure rpms. | Within 120 seconds, CLI can configure machine to 22 rpm, and V so performs. | 2 rpm |  | FALSE | FALSE |  |  |  | TRUE | TRUE
Tidal Volume
1 | TID1 | 400ml Vt functions | Ask CLI to configure machine to 400ml Tidal Volume (if only setting for machine, ask them to state.) When so set, measure with professional plastic test lung. Observe rise of lunch (measured in mm) to match that of forcing 400ml into lung via syringe or other precise method.) | 400ml | 10ml |  | FALSE | FALSE |  |  |  | TRUE | TRUE
2 | TID2 | Optional 350 and 450ml setting | Ask CLI to configure machine to 350ml and 450ml Tidal Volume (if only setting for machine, ask them to state.) When so set, measure with professional plastic test lung. Observe rise of lunch (measured in mm) to match that of forcing 400ml into lung via syringe or other precise method.) | 350ml and 450ml | 10ml |  | FALSE | FALSE |  |  |  | FALSE | TRUE
3 | TID3 | Optional 250 and 600ml range | Ask CLI to configure machine to extremes of range 250ml and 600ml Tidal Volume (if only setting for machine, ask them to state.) When so set, measure with professional plastic test lung. Observe rise of lunch (measured in mm) to match that of forcing 400ml into lung via syringe or other precise method.) | 250ml and 600ml | 10ml |  | FALSE | FALSE |  |  |  | FALSE | TRUE
4 | TID4 | Highly Optional 800ml | Ask CLI to configure machine to extremes of range 800ml Tidal Volume (if only setting for machine, ask them to state.) When so set, measure with professional plastic test lung. Observe rise of lunch (measured in mm) to match that of forcing 400ml into lung via syringe or other precise method.) | 800ml | 10ml |  | FALSE | FALSE |  |  |  | FALSE | TRUE
Infection Control
1 | INFC1 | Device can be fully implemented while wearing PPE | Ask CLI to fully connect the system, turn it on, and verify functio | CLI can successfuly execute CON1-7 and SUP1-6 while wearing full PPE including hood |  |  | FALSE | FALSE |  |  |  | TRUE | TRUE
2 | INFC2 | Parts can be changed/disposed | Ask CLI to change ETT | Within 30 seconds, CLI can remove ETT, dispose of it in appropriate biohazard, and replace it |  |  | FALSE | FALSE |  |  |  | TRUE | TRUE
3 | INFC3 | Surfaces can be cleaned | Ask CLI to disinfect external surfaces | Within 60 seconds, CLI can disinfect external parts of device |  |  | FALSE | FALSE |  |  |  | TRUE | TRUE
4 | INFC4 | Seal from aerosol droplets |  |  |  |  | FALSE | FALSE |  |  |  | FALSE | TRUE
Monitoring
1 | MON1 | Vt verified | Ask CLI to verify Vt | Within 5 seconds, CLI can report set and actual Vt from monitor |  |  | FALSE | FALSE |  |  |  | TRUE | TRUE
2 | MON2 | PEEP verified | Ask CLI to verify PEEP | Within 5 seconds, CLI can report set and achieved PEEP from monitor |  |  | FALSE | FALSE |  |  |  | TRUE | TRUE
3 | MON3 | DFiO2 verified | Ask CLI to verify DFiO2 | Within 5 seconds, CLI can report set and achieved FiO2 from monitor |  |  | FALSE | FALSE |  |  |  | TRUE | TRUE
4 | MON4 | Breathing rate verified | Ask CLI to verify breathing rate | Within 5 seconds, CLI can report patient breathing rate |  |  | FALSE | FALSE |  |  |  | TRUE | TRUE
5 | MON5 | Airway pressure | Ask CLI to verify airway pressure | Within 5 seconds, CLI can report airway pressure |  |  | FALSE | FALSE |  |  |  | TRUE | TRUE
6 | MON6 | CO2 verified | Ask CLI to verify CO2 | Within 5 seconds, CLI can report patient expiratory CO2 |  |  | FALSE | FALSE |  |  |  | FALSE | TRUE
7 | MON7 | Real-time patient breath verified | Ask CLI to verify last patient breath | Within 5 seconds, CLI can report last patient breath in real-time |  |  | FALSE | FALSE |  |  |  | TRUE | TRUE
Alarm
1 | ALA1 | Device power failure | Instruct CLI to cut power to the device without proper shut off protocol | Alarm is immediately set off |  |  | FALSE | FALSE |  |  |  | TRUE | TRUE
2 | ALA2 | Pressure limit exceeded | Instruct CLI to forcibly add pressure exceeding 40cm H20 | Alarm is set off after 3 seconds | 2 seconds |  | FALSE | FALSE |  |  |  | TRUE | TRUE
3 | ALA3 | Oxygen supply failure | Instruct CLI to disconnect oxygen supply | Alarm is set off after 5 seconds | 5 seconds |  | FALSE | FALSE |  |  |  | TRUE | TRUE
4 | ALA4 | Patient breath below acceptable range | Instruct CLI to block ETT | Alarm is set off after 3 seconds | 2 seconds |  | FALSE | FALSE |  |  |  | TRUE | TRUE
5 | ALA5 | Hypercapnia |  |  |  |  | FALSE | FALSE |  |  |  | FALSE | TRUE
6 | ALA6 | PEEP failure | Instruct CLI to set PEEP and unplug ETT at end of exhalation cycle | Alarm is set off after 2 seconds | 1 second |  | FALSE | FALSE |  |  |  | TRUE | TRUE
7 | ALA7 | IA pressure failure | Instruct CLI to set IA pressure and unplug ETT during inspiration cycle | Alarm is set off after 2 seconds | 1 second |  | FALSE | FALSE |  |  |  | TRUE | TRUE
8 | ALA8 | Vt not achieved |  |  |  |  | FALSE | FALSE |  |  |  | TRUE | TRUE
9 | ALA9 | Vt exceeded |  |  |  |  | FALSE | FALSE |  |  |  | TRUE | TRUE

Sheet: References
 | Important Reference Documents
Reference #
1 | Rapidly Manufactured Ventilator System | https://assets.publishing.service.gov.uk/government/uploads/system/uploads/attachment_data/file/874279/RMVS001_Rapidly_Manufactured_Ventilator_Specification__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
 | These are different internatinal standards, each of which may drive a test, and may overlap or even conflit. The colum in the table says which standard comes from where.
Standards | Name | Defining document or repo | Notes
 | RMVS | ref(1), British | This standard has optional elements we will denote RMVS(O).
Draft v0.1 - March 25th
By Public Invention, in cooperation with BreathOfLife and Jonathan Orban
Licensed under CC0; consider a template to copy and extend
Copyright Robert L. Read, Juan E Villacres Perez, Jonathan Orban and others 2020
Note: primary source is UK Rapid Manufactered Ventilator System (1)
Primary Point of Contact: Robert L. Read, PhD <read.robert@gmail.com>

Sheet: Abbreviations
Abbreviations | Definition
CLI | Clinician (Doctor, nurse, respiratory therapist)
DTIDVOL | Default Tidal Volume
DRATE | Default Respiratory Rate
DFiO2 | Default Fraction of Inspired Oxygen
V | Ventilator
rpm | respirations per minute
IA | Inspiratory Airway
Vt | Tidal Volume
ETT | Endotracheal Tube
DIERATIO | Default Inspiration / Expiration Ratio
Draft v0.1 - March 25th
By Public Invention, in cooperation with BreathOfLife and Jonathan Orban
Licensed under CC0; consider a template to copy and extend
Copyright Robert L. Read, Juan E Villacres Perez, Jonathan Orban and others 2020
Note: primary source is UK Rapid Manufactered Ventilator System (1)
Primary Point of Contact: Robert L. Read, PhD <read.robert@gmail.com>
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

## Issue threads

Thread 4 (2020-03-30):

A test lung reference data set?

synergiator, 2020-03-30:
Dear test team,

is there a reference data set describing the tests with the test lung?

https://gitlab.com/open-source-ventilator/OpenLung/-/issues/133

There is [breath_data](https://github.com/PubInv/ventmon-ventilator-inline-test-monitor/blob/master/breath_data/rob_even.json) folder with a json file and a Python data server in this project - is that what we are looking for?

RobertLRead, 2020-03-30:
This is a great question; possibly a new repo should be created to create a breath data set.  However, first we would have to have a standard for how the data should be represented.  I have a simple approach that I am using, but was not ready to propose it as a standard.  You can see it [here](https://github.com/PubInv/ventmon-ventilator-inline-test-monitor/blob/master/breath_data/rob_even.json). That is me breathing evenly into an OPEN tube (not a test lung, which will round off the corners. We really need a standard and about 10 test files.  I now have the ability to add that; I will attempt to add some more data today.  We might be able to find better data examples, but I know of none.  BTW, this proejct has Flow data; most projects probably don't, they will have pressure data, which is quite different. Ideally, we would have a standard that allows BOTH to be treated together, (and supports one being missing.)

RobertLRead, 2020-03-31:
I've added a new data file that contains pressures, and is at a higher sampling rate. This is of me breathing into a plastic test lung that provides considerable resistance. I'm using the 5cmH20 adapter when plugging into the test lung. This format is still awful. I will try to produce a good standard unless you guys get to it first, or find one on the web: [https://github.com/PubInv/ventmon-ventilator-inline-test-monitor/blob/master/breath_data/rob_test_lung_breath_even.json](https://github.com/PubInv/ventmon-ventilator-inline-test-monitor/blob/master/breath_data/rob_test_lung_breath_even.json)

Closed 2020-05-05.

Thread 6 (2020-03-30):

Tidal volume calculations

jywarren, 2020-03-30:
Hi, I'm helping coordinate between different groups working on ventilator projects and was hoping to compare notes on the tidal volume calculations from different flow input parameters. Can you point me to the relevant section of code once you've gotten there? I'm trying to collate links here:

https://docs.google.com/document/d/1tmshR0kalscyDnLyDslsh1XSoqaE5CFErC51kqzyBF8/edit?usp=drivesdk

Thank you!

jywarren, 2020-03-30:
Would I look here?

https://github.com/PubInv/ventmon-ventilator-inline-test-monitor/blob/267f638b6aeb56dd6b72c10f8df48896621d856b/test_tools/breath_plot.html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

Thank you!

RobertLRead, 2020-03-30:
Sorry, a little cold to what you are asking. I am using a "flow meter" that
gives me slm (standard liters per minute.) As you probably know, volume
cannot be detected reliable from pressure without a sophisticated
compliance model, which won't work because it changes with disease
condition.  Not sure it will be useful out of context, but the code simply
integrates samples between transitions and then makes sure the units are
right. I use the simple "quadrilateral" approximation method:

 // Now that we have transitions, we can apply a
  // diferent algorithm to try to define "breaths".
  // Because a breath is defined as an inspiration
  // and then an expiration, we will define a breath
  // as from the first inspiration, until there has
  // been one expiration, until the next inspiration.
  var breaths = []
  var expiring = false;
  var last = 0;
  var voli = 0;
  var vole = 0;

  // This should be in liters...
  function integrateSamples(a,z) {
    // -1 for quadilateral approximation
    var vol = 0;
    for(var j = a; j < z-1; j++) {
      // I'll use qadrilateral approximation.
      // We'll form each quadrilateral between two samples.
      var ms = samples[j+1].millis - samples[j].millis;
      var ht = (samples[j+1].Flow + samples[j].Flow)/2;
      // Flow is actually in standard liters per minute,
      // so to get liters we divide by 60 to it l/s,
      // and and divde by 1000 to convert ms to seconds.
      // We could do that here, but will move constants
      // to end...
      vol += ms * ht;
    }
    return vol/(60*1000);
  }
  for(var i = 0; i < transitions.length; i++) {
    if (expiring && transitions[i].state == 1) {
      breaths.push({ ms: transitions[i].ms,
                     sample: transitions[i].sample,
                     vol_e: vole,
                     vol_i: voli
                   }
                  );
      expiring = false;
      vole = integrateSamples(last,transitions[i].sample);
      last = transitions[i].sample;
    }
    if (!expiring && transitions[i].state == -1) {
      expiring = true;
      voli = integrateSamples(last,transitions[i].sample);
      last = transitions[i].sample;
    }
    // At this point we can in theory compute an inspiratory volume..

  }

On Mon, Mar 30, 2020 at 3:53 PM Jeffrey Warren <notifications@github.com>
wrote:

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

--
Robert L. Read, PhD
Twitter: @RobertLeeRead @pubinvention
Public Invention: https://www.pubinv.org
Join Our Mailing list: pubinv@googlegroups.com
YouTube: https://www.youtube.com/channel/UCJQg_dkDY3KTP1ybugYwReg
Medium: https://medium.com/@RobertLeeRead

RobertLRead, 2020-03-30:
Darn it, can't get markdwon to work right:

` // Now that we have transitions, we can apply a
  // diferent algorithm to try to define "breaths".
  // Because a breath is defined as an inspiration
  // and then an expiration, we will define a breath
  // as from the first inspiration, until there has
  // been one expiration, until the next inspiration.
  var breaths = []
  var expiring = false;
  var last = 0;
  var voli = 0;
  var vole = 0;

  // This should be in liters...
  function integrateSamples(a,z) {
    // -1 for quadilateral approximation
    var vol = 0;
    for(var j = a; j < z-1; j++) {
      // I'll use qadrilateral approximation.
      // We'll form each quadrilateral between two samples.
      var ms = samples[j+1].millis - samples[j].millis;
      var ht = (samples[j+1].Flow + samples[j].Flow)/2;
      // Flow is actually in standard liters per minute,
      // so to get liters we divide by 60 to it l/s,
      // and and divde by 1000 to convert ms to seconds.
      // We could do that here, but will move constants
      // to end...
      vol += ms * ht;
    }
    return vol/(60*1000);
  }
  for(var i = 0; i < transitions.length; i++) {
    if (expiring && transitions[i].state == 1) {
      breaths.push({ ms: transitions[i].ms,
                     sample: transitions[i].sample,
                     vol_e: vole,
                     vol_i: voli
                   }
                  );
      expiring = false;
      vole = integrateSamples(last,transitions[i].sample);
      last = transitions[i].sample;
    }
    if (!expiring && transitions[i].state == -1) {
      expiring = true;
      voli = integrateSamples(last,transitions[i].sample);
      last = transitions[i].sample;
    }
    // At this point we can in theory compute an inspiratory volume..

  }`

jywarren, 2020-03-31:
Thank you, I'm just doing background research and this is helpful. The inspiratory volume is then an estimated equivalent to https://en.m.wikipedia.org/wiki/Tidal_volume ?

Are there standards for sampling rate to make such estimates?

Thanks a lot!

RobertLRead, 2020-03-31:
Well, it's not really an estimate, its a measurement, which of course is
not perfect.  And yes, it is the tidal volume; thought not every breath has
the same volume. If you average it over time it would be tidal volume, I
think.

I'm not aware of a sampling rate standard. We have a technical problem
limiting us to 40 Hz right now, but we want to operate at 100 Hz. I see no
reason to need more than 100 Hz (the only reason for that would be to
detect (relatively) high frequency noise, such as turbulence in the airway
caused by condensed water.

On Tue, Mar 31, 2020 at 8:53 AM Jeffrey Warren <notifications@github.com>
wrote:

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

--
Robert L. Read, PhD
Twitter: @RobertLeeRead @pubinvention
Public Invention: https://www.pubinv.org
Join Our Mailing list: pubinv@googlegroups.com
YouTube: https://www.youtube.com/channel/UCJQg_dkDY3KTP1ybugYwReg
Medium: https://medium.com/@RobertLeeRead

jywarren, 2020-04-01:
Sorry, yes a measurement, I just meant it's limited theoretically by the sampling rate, but what you're doing sounds plenty fast. Thanks a lot for your help! Very much appreciated!!

Closed 2020-05-05.

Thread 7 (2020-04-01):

Airway Pressure Sensor

EnginerdingDan, 2020-04-01:
Thought I'd submit a "crash course" from an analog design point of view (also have 2 decades experience in emergency medicine).

Separately, but equally valid -- I'd like to suggest consideration for using a commonly available hospital item, the IPB pressure transducer (e.g. Edwards TruWave).

Please see attached, I have all the items on-hand mentioned in this doc for prototyping:

[Airway Pressure Monitoring.docx](https://github.com/PubInv/ventmon-ventilator-inline-test-monitor/files/4413069/Airway.Pressure.Monitoring.docx)

EnginerdingDan, 2020-04-01:
note:  I see saving from LibreOffice to docx has wrapped the text around one image poorly (par for the course!).  Please excuse.

RobertLRead, 2020-04-01:
This is great work; do you mind putting your name and copyright notice and
license like CC0 (public domain) on it and giving me permission to add it
to the repo?

I am probably using poor sensors; I did what was easiest from Adafruit.

On Wed, Apr 1, 2020 at 1:13 AM EnginerdingDan <notifications@github.com>
wrote:

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

--
Robert L. Read, PhD
Twitter: @RobertLeeRead @pubinvention
Public Invention: https://www.pubinv.org
Join Our Mailing list: pubinv@googlegroups.com
YouTube: https://www.youtube.com/channel/UCJQg_dkDY3KTP1ybugYwReg
Medium: https://medium.com/@RobertLeeRead

EnginerdingDan, 2020-04-01:
Added license and author.  Fixed some grammar.

Is it OK if I maintain this document?

Also re:  sensors.  I started to talk on this, but deleted because it go too off-topic for this issue.  I'll start a new issue.

[Airway Pressure Monitoring.docx](https://github.com/PubInv/ventmon-ventilator-inline-test-monitor/files/4416187/Airway.Pressure.Monitoring.docx)

RobertLRead, 2020-04-01:
Sure, you can maintain; but do you mean you want it in this repo, or in
your own?  I will link to it as a resource in any case, but it has
be hosted somewhere, unless you want to switch it to shared Google Doc
(cloud hosted) instead of a Word doc.

On Wed, Apr 1, 2020 at 10:36 AM EnginerdingDan <notifications@github.com>
wrote:

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

--
Robert L. Read, PhD
Twitter: @RobertLeeRead @pubinvention
Public Invention: https://www.pubinv.org
Join Our Mailing list: pubinv@googlegroups.com
YouTube: https://www.youtube.com/channel/UCJQg_dkDY3KTP1ybugYwReg
Medium: https://medium.com/@RobertLeeRead

Closed 2020-05-05.

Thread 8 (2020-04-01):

Flow Sensor alternates due to supply-chain crunch,

EnginerdingDan, 2020-04-01:
The FM3200 is a really fantastic sensor from a specifications point of view.

The cons for the developing world, I think will be: price (it's $170/ea).
And perhaps even bigger, availability.  I just checked Octopart and less than 100 in the world in-stock for the AW and AG models.

Erg, I propose one of the priorities-of-work would be finding a suitable alternative.

Automotive Mass Air Flow Sensor?  They seem to be very cheap, have *similar* input/output dimensions, are probably available in qty in the developing world.  I do not however, know if the engineering specifications would match.

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

RobertLRead, 2020-04-02:
I think this is an important point.  I haven't really been thinking about it yet, but having the system modular so you can use essentially the same system with multiple flow meters is a good idea. It would really help if those were standard 22mm airway meters.  If not, we might have to build a male port on  side, a female on the other, and then change the interior design based on which flow meter you use.

EnginerdingDan, 2020-04-03:
I ordered some low-cost automotive oxygen and MAF sensors that should be accessible to the developing world in terms of price.  Next week, I should have a universal guide up.  I don't know if the engineering specifications will be suitable, particularly the flow sensor (it has a much higher rate of flow, I'm assuming), but will keep searching for some typical specs for small cars.

I'm assuming the smaller the vehicle the mass air flow sensor comes from, the better from an engineering spec point of view.  ATV's and bikes might be the trick, but I think may be quite a bit more expensive.

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

RobertLRead, 2020-05-05:
Did you ever publish that guide? I would like to link to it on the main site, but I have to have a URL to link to.

Closed 2021-03-22.

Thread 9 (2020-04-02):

Test lung

hpeuscher, 2020-04-02:
Apologies if this is the wrong place to post this information, but if you need to test or calibrate your device, I would like to draw your attention to our test rig which allows to create highly accurate volume flows and/or to realistically simulate the dynamic behavior of a human lung. For details, please see https://www.youtube.com/watch?v=KEQDs0R-pMc

RobertLRead, 2020-04-02:
Know, this is the right place. I am very interested.  But tell me:

Do you have only one such machine, or many instances of that model?
Do you propose shipping the glass lung to the ventilator, or shipping the
ventilator to the glass lung?

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

--
Robert L. Read, PhD
Twitter: @RobertLeeRead @pubinvention
Public Invention: https://www.pubinv.org
Join Our Mailing list: pubinv@googlegroups.com
YouTube: https://www.youtube.com/channel/UCJQg_dkDY3KTP1ybugYwReg
Medium: https://medium.com/@RobertLeeRead

maehw, 2020-04-19:
@hpeuscher similar questions from https://github.com/maehw/diy-beatmungsgeraet. But we are closer to you, so could ship some equipment to be tested, if that's still intended. ;)

hpeuscher, 2020-04-19:
@maehw The offer stands. Feel free to contact me by email.

maehw, 2020-04-20:
> @maehw The offer stands. Feel free to contact me by email.

Thank you. The one on THU's website?
Would you help arranging/planning the test setup?

hpeuscher, 2020-04-20:
Yes, certainly, if I can. We should best discuss this over the phone.

maehw, 2020-04-26:
Communication has been initialized by e-mail. We'd be happy to set up a call.

Closed 2020-05-05.

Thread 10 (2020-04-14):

Error in printing of serial number and scaling

maehw, 2020-04-14:
In SensirionFM3200/SFM3200/SFM3200.ino there's a function called requestSerialNumber:

```
  uint8_t a = Wire.read(); // first received byte stored here. The variable "uint16_t" can hold 2 bytes, this will be relevant later
  uint8_t b = Wire.read();
  uint8_t c = Wire.read(); // first received byte stored here. The variable "uint16_t" can hold 2 bytes, this will be relevant later
  uint8_t d = Wire.read();
  Serial.println(a,HEX);
  Serial.println(a,HEX);
  Serial.println(a,HEX);
  Serial.println(a,HEX);
```
As `a` is printed four times, this will not show the true serial number of the device.
I think you could base on my implementation under https://github.com/maehw/diy-beatmungsgeraet/tree/master/software/mass-airflow-sensor/controller-software - probably minor changes to support your Sensirion device, too.

Edit: I think there's another error in scaling:

```
 float scale = 120.0; // Scale factor for Air and N2 is 140.0, O2 is 142.8
```
The comment speaks of a value of around 140. Why do you use 120 in the code?

RobertLRead, 2020-04-14:
This is a fantastic catch! Thank you very much --- I actually thought the Serial numbers were not working. Thank you, I have fixed it.

I use the scaling factor because the datasheet gives that for the SFM 3200 that I bought: https://www.mouser.com/datasheet/2/682/Sensirion_Mass_Flow_Meters_SFM3200-AW_Datasheet-1524538.pdf.

The comment came from code I copied from the internet. At the time I was not aware that Sensirion had that own library; I will now create a TODO item to use switch over to their library.  Your code is almost certainly far better, because the crc for the code I copied never worked.  So you have informed me of much; thank you!

Closed 2020-05-05.

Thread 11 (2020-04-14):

Switch over to using Maehw's code (and the official Sensirion library).

RobertLRead, 2020-04-14:
@maehw has pointed out that they have a more complete use so Sensirion code.  The project will be far more robust when I have used their code:

https://github.com/maehw/diy-beatmungsgeraet/tree/master/software/mass-airflow-sensor/controller-software

maehw, 2020-04-18:
Hi @RobertLRead: our code is not based on Sensirion code.

When I did some research back then I found the following repositories:

- https://github.com/Sensirion/libsensors-python (deprecated)
- https://github.com/Sensirion/arduino-liquid-flow-snippets
- https://github.com/Sensirion/arduino-sdp

IIRC they cover sensors, but not meters as the SFM3xxx.

Closed 2020-05-07.

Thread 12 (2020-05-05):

Manual Formatting

lauriaclarke, 2020-05-05:
For some reason the normal GitHub header and footer are to the side of the user manual when viewing the page, making it hard to read. Not sure how to fix this. See attached photo.
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

RobertLRead, 2020-05-05:
I can't duplicate in Chrome --- what browser are you using?

Closed 2021-03-22.

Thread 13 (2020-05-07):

RR rate seems low

armeetrooper, 2020-05-07:
RR rate does not seem to reflect actual respiratory rate. Please see attached photo. An RR of 6 would be approx 1 Peak to Peak in a decade.

Thanks for all the great work team!!!
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

RobertLRead, 2020-05-07:
This is a bug; it is counting only the 2 breaths in the 12 seconds, not
measure a peak-to-peak rate. I will fix this with high urgency.  For now
you can't trust it --- that is why it always shows 6 (or some other divisor
of 12).

On Wed, May 6, 2020 at 7:58 PM armeetrooper <notifications@github.com>
wrote:

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

--
Robert L. Read, PhD
Twitter: @RobertLeeRead @pubinvention
Public Invention: https://www.pubinv.org
Join Our Mailing list: pubinv@googlegroups.com
YouTube: https://www.youtube.com/channel/UCJQg_dkDY3KTP1ybugYwReg
Medium: https://medium.com/@RobertLeeRead

RobertLRead, 2020-05-07:
This has been fixed, please test and close if you agree.

armeetrooper, 2020-05-07:
Appears that instantaneous RR is working but not sure if the Minute volume math lines up.

See attached. Should be seeing MV of 358 x 27.1 = 9.701 lpm.

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

RobertLRead, 2020-05-07:
I just tested, I think it is correct BUT it will have jitter with a low
number of breaths.  I have entered another bug for the fact that the length
of the trace (in time, but based on samples) is not changing. That 12
seconds is short for your respiration rates. It is possible that I need to
think of a better way to compute it, but the problem is you have discrete
breaths within a finite frame, and that number will be an integer number of
breaths.

Probably I can think of some more elegant way of computing it so it will
not change so rapidly.

On Wed, May 6, 2020 at 10:51 PM armeetrooper <notifications@github.com>
wrote:

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

--
Robert L. Read, PhD
Twitter: @RobertLeeRead @pubinvention
Public Invention: https://www.pubinv.org
Join Our Mailing list: pubinv@googlegroups.com
YouTube: https://www.youtube.com/channel/UCJQg_dkDY3KTP1ybugYwReg
Medium: https://medium.com/@RobertLeeRead

RobertLRead, 2020-05-08:
I have fixed the minute volume so that it now computes from inhalation time to inhalation time, summing the volume between those points and dividing by the time. This is both more accurate and more "stable" (changes less frequently.)

Closed 2020-05-08.

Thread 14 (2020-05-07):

Number of samples changes on my local computer...

RobertLRead, 2020-05-07:
But not on the data lake. I don't know why.

gmulligan, 2020-05-08:
Was this a file permission problem on the data lake

RobertLRead, 2020-05-08:
No, coding on my part; it is fixed now I will close.

On Fri, May 8, 2020 at 4:52 PM Geoff Mulligan <notifications@github.com>
wrote:

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

--
Robert L. Read, PhD
Twitter: @RobertLeeRead @pubinvention
Public Invention: https://www.pubinv.org
Join Our Mailing list: pubinv@googlegroups.com
YouTube: https://www.youtube.com/channel/UCJQg_dkDY3KTP1ybugYwReg
Medium: https://medium.com/@RobertLeeRead

Closed 2020-05-08.

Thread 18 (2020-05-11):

Feature Request - Second SFM3/4xxx for monitoring input air/O2 injection  (pneumatics)

armeetrooper, 2020-05-11:
Hey guys

First off thank you for the amazing work.

One issue unique to ARMEE is the pneumatic power source. We would like to somehow integrate a second flow meter to monitor incoming air supply conditions.

Is this something that can be
- electrically implemented
- programmed to display a baseline input/o2 flow rate.

Thanks in advance and keep up the great work!

RobertLRead, 2021-03-22:
I'm closing this issue.  It's a good idea but our basic approach to this would be to use to VentMons. We have now implemented timing in the datastream that should (in theory) make anything you wanted to do in this way possible.

Closed 2021-03-22.

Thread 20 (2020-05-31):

Missing FLOW_TOO_HIGH / FLOW_TOO_LOW

giseburt, 2020-05-31:
https://github.com/PubInv/ventmon-ventilator-inline-test-monitor/blob/17a0a8d54453255932417a3112f3749808623b2c/VentMonFirmware/VentMonFirmware.ino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

I added this above those lines and it worked:
```c++
#define FLOW_TOO_HIGH "FLOW OUT OF RANGE HIGH";
#define FLOW_TOO_LOW  "FLOW OUT OF RANGE LOW”;
```

RobertLRead, 2020-05-31:
This is embarrassing....I had those lines in "PIRDS.h" in a different
branch (I forgot to merge into master.)

If you reinstall pirds_library from
https://github.com/PubInv/PIRDS-respiration-data-standard/tree/master/pirds_library
as
an Arduino library you should not have to put that into the
firmware directly.

Good catch, thanks for reporting this!

On Sun, May 31, 2020 at 2:29 PM Rob Giseburt <notifications@github.com>
wrote:

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

--
Robert L. Read, PhD
Twitter: @RobertLeeRead @pubinvention
Public Invention: https://www.pubinv.org
Join Our Mailing list: pubinv@googlegroups.com
YouTube: https://www.youtube.com/channel/UCJQg_dkDY3KTP1ybugYwReg
Medium: https://medium.com/@RobertLeeRead

Closed 2020-06-04.

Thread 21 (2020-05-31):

Ambient and differential pressures are wrong on start up until the rolling window is filled...

RobertLRead, 2020-05-31:
This goes away after running for two minutes but can be very confusing. I will fix it now.

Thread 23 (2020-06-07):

Compute dynamic compliance

RobertLRead, 2020-06-07:
This paper suggests that it might be useful to compute dyanmic compliance; we clearly have all the data to do so, we just need to compute and display it.

[https://derangedphysiology.com/main/cicm-primary-exam/required-reading/respiratory-system/Chapter%20531/flow-volume-pressure-resistance-and-compliance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,is%20flow%20multiplied%20by%20time&text=Resistance%20is%20the%20change%20in,divided%20by%20change%20in%20pressure](https://derangedphysiology.com/main/cicm-primary-exam/required-reading/respiratory-system/Chapter%20531/flow-volume-pressure-resistance-and-compliance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,is%20flow%20multiplied%20by%20time&text=Resistance%20is%20the%20change%20in,divided%20by%20change%20in%20pressure)

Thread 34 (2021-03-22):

T0.4 case back could have some "cut outs" to allow zip tie attachments.

RobertLRead, 2021-03-22:
Tape could be used now, but if we redesign the case there is no reason not to make it more "attachable."

RobertLRead, 2023-05-03:
This is no long necessary, although the same feature might be useful in T0.6 (next version, as of time of this writing.)

Closed 2023-05-03.

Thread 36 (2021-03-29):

Have display compute tidal volume by integrating flow, and render flow!

RobertLRead, 2021-03-29:
Although our IDE is very small, we could graph flow and compute tidal volume dynamically.

RobertLRead, 2021-06-01:
Note: The Rice University "Mask and You Shall Receive" team showed this was possible by coding this into an Arudino Nano (I think, it may have been an ESP32) after I showed them the math in Javascript in VentDisplay.

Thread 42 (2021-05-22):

VentMon T0.5 architectureal ideas...

RobertLRead, 2021-05-22:
I think Public Invention may need to make a new run of VentMons. Possibly we will sell these, or sell some of them.
I've been trying to think about the sanitizability problem. I don't see any way to sanitize the pressure sensor, or the O2 sensor, or the flow sensor.
So, what I suggest is 3 separate modules (which a user might not be aware of as distinct).
We make the large-GUI with a "pocket" or "socket" where the VentMon can plug in or be mounted. We move the pressure sensor off the main board, and put it on a tiny breakout board. We use a molex-style electrical connector for it. We do the same thing with the O2 sensor (2-wire) circuit, and 4-wires (but one at 5V) for the sensirion flow sensor. That makes that entire combinations of parts electrically connect via a cable to main the main board.We switch to the cheap USD$40 disposable Sensirion flow sensor.The result of all of this is that we have a USD$100 disposable "daughter" airway that you just replace if it gets exposed. It fits in a separate USD$100 "mother board/enclosure", and that fits in a separate USD$100 "grand mother" board/enclosure. The result is an overall decreased costs, and a plausible infection control story. If the airway is sufficiently protected by one-way check valves, people might not feel it needs to be replaced on a per-patient basis. 

RobertLRead, 2023-05-03:
The T0.5 has now been made.

Closed 2023-05-03.

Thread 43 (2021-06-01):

Note: The TFT Smart Pi 2 has 75mm VESA MIS-D 75 mounts

RobertLRead, 2021-06-01:
We could probably mount the VentMon case with the MIS-D 75 format, and this would give us a convenient way to put the VentMon on the new Pi-based screen.

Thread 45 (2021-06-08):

Consider adding VESA standard mounting holes to both the front and the back case of the VentMon

RobertLRead, 2021-06-08:

RobertLRead, 2021-06-08:
Lauria took my bracket design and suggested we could make it smaller. To do this we will need to have VESA Mount holes on the front of the case. it might be wise to put them on the back of the case as well. If we make the case smaller, we can always use only 2 or 3 of the holes.

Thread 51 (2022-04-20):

Can ventmon be compatible with TSI certifier FA plus (ts4080)

xykts, 2022-04-20:
hi.Dear ventmon team

Ventmon is a very good project，It may enable many people to use low-cost GAS flow analysis。

I have a set of TSI certifier FA plus TSI 4080 gas flow analyzer，I lost its flow sensor(TSI 4081 HIGH FLOW modeule) when I went out！
When I saw this project, I wondered if ventmon could be used instead of TSI 4081,
TSI certifier FA plus consists of two parts: TSI 4088 interface module and TSI 4081 high flow module，They are connected via a 4-pin cable and transmit pressure and flow data，I guess it's probably RS232 bus But I don't know its data protocol。

So I'm here to ask a question. Maybe someone knows the communication protocol and data format between TSI 4088 and TSI 4081，If you know its communication protocol and data format, it should be easy to use ventmon instead of TSI 4081！

Everyone, can you provide some useful information for this idea。

Thanks to the great team！

RobertLRead, 2022-04-20:
I;m in the woods now without internet. I will try to answer on Saturday.

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

--
Robert L. Read, PhD
Twitter: @RobertLeeRead @pubinvention
Public Invention: https://www.pubinv.org
Join Our Mailing list: ***@***.***
YouTube: https://www.youtube.com/channel/UCJQg_dkDY3KTP1ybugYwReg
Medium: ***@***.***

RobertLRead, 2022-04-25:
Hi, thanks for writing. I've now looked at the TSI 4081 high flow module. I doubt the VentMon can replace it. The VentMon cannot operate as high as 10 bar. Although our protocol is the public PIRDS protocol (https://github.com/PubInv/PIRDS-pubinv-respiration-data-standard), so, if you are a programmer, you could use it for anything.  The VentMon may do approximately what the entire TSI 4080 gas flow analyzer does (though not at pressures that high.) I am not familiar with that product, but it may be that VentMon functionality is similar.

RobertLRead, 2023-05-03:
Closing this as complete.

Closed 2023-05-03.

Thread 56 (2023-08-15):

New VentMon T0.5 some times have Pressure sensors installed backwards....

RobertLRead, 2023-08-15:
When installing software, we can correct this. I could even add it to the configuration file.

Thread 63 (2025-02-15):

Generate PDF files for schematics and PCB, Generate Gerbers for PCB for Ventmon T0.5 (and others)

ForrestErickson, 2025-02-15:
Please add documents so that I and others can view the schematic and board with out installing any software.

Visitors to this folder, https://github.com/PubInv/ventmon-ventilator-inline-test-monitor/tree/master/design/pcb/ventmon_T0.5 may benefit from PDF files of these schematics and board files.

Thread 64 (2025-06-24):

Hardware, Detached Light Pipe Version: ?Ventmon 0.5?

ForrestErickson, 2025-06-24:
# Summary
Hardware, Detached Light Pipe Version:

## DUT History
June 2025 Lee has received a VentMon during a visit to Austin TX.
I think it is version: 0.5
There is no serial number on this device.

## Details
What I think would be called a light pipe has become detached and I have secured it with transparent tape.

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

## Boot up message

```
14:15:59.554 -> OLED begun
14:16:06.635 -> Starting VentMon...Checking sensors...Ambient Pressure Sensor     : NO
14:16:07.845 -> Inspiratory Pressure Sensor : BME280
14:16:07.937 -> Found O2 Sensor: NO
14:16:08.903 -> sensor serial number: 862B8B9F
14:16:08.903 -> sensor article number: 118ABD01
14:16:08.903 ->
14:16:08.903 -> read scale factor: 120.00
14:16:08.903 -> read flow offset: 32768.00
14:16:08.903 -> flow : 0.00 slm
14:16:09.034 -> flow : -0.03 slm
14:16:09.126 -> flow : 0.00 slm
14:16:09.218 -> flow : 0.00 slm
14:16:09.302 -> flow : 0.00 slm
14:16:09.431 -> Found Differential Pressure Sensor: YES
14:16:09.431 -> ----------------- SENSOR TEST COMPLETE -----------------
14:16:09.431 -> Wifi not an AP
14:16:09.431 -> Config via serial...WiFi DISABLED
14:16:09.934 -> Enter 'w' to enable WiFi, 'x' to disable WiFi
14:16:09.934 -> Enter 'c' to re-enter this configuration while running.
14:16:09.968 -> { "event": "M", "type": "P", "ms": 10848, "loc": "I", "num": 0, "val": 10085 }
14:16:09.968 -> { "event": "M", "type": "T", "ms": 10850, "loc": "I", "num": 0, "val": 2545 }

```

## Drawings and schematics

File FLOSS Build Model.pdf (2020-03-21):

# Possible COVID-19 FLOSS/DIY Ventilator Deployment

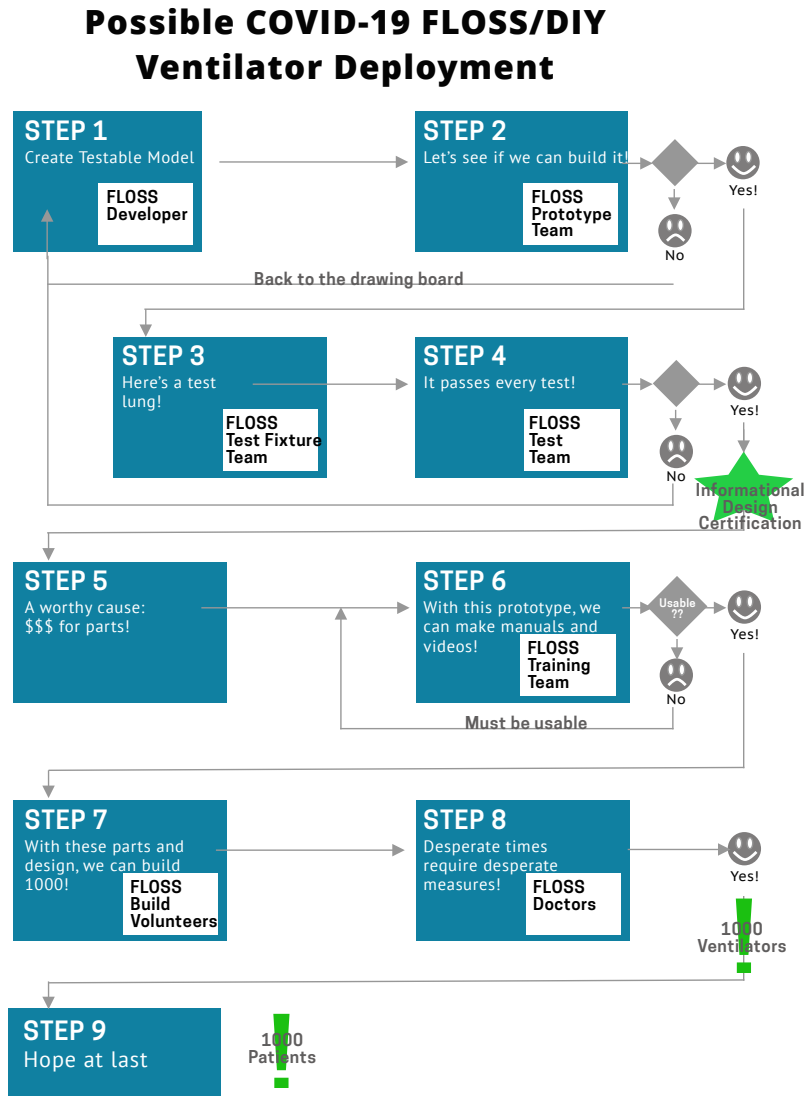
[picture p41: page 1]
STEP 5; A worthy cause: $$$ for parts!; STEP 7; With these parts and design, we can build 1000!; STEP 3; Here’s a test lung!; STEP 8; Desperate times require desperate measures!; Yes!; FLOSS Developer; FLOSS Prototype Team; FLOSS Test Fixture Team; FLOSS Build Volunteers; FLOSS; Doctors; FLOSS Training Team; FLOSS Test Team; 1000 Ventilators; Informational Design Certification; Usable ??; 1000 Patients

STEP 1
Create Testable Model

STEP 2
Let’s see if we can build it!

Back to the drawing board

STEP 4
It passes every test!

STEP 6
With this prototype, we
can make manuals and
videos!

Must be usable

STEP 9
Hope at last

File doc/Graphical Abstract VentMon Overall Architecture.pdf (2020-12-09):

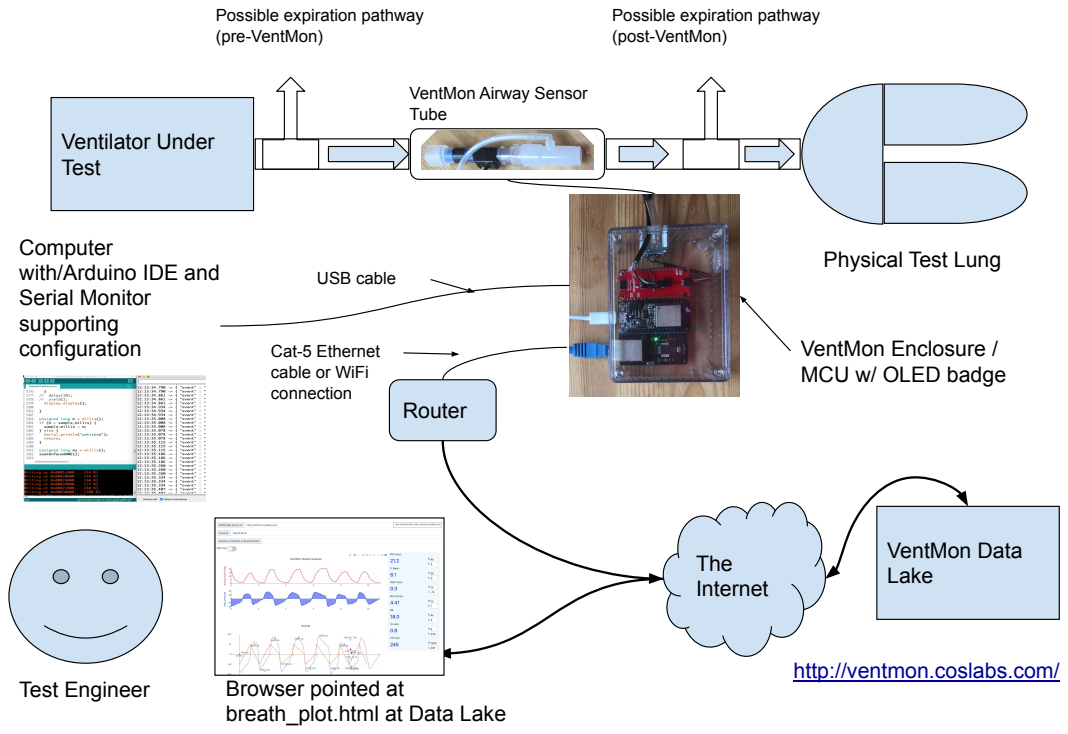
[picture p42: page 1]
Ventilator Under Test; VentMon Data Lake The Internet; Router; Test Engineer; USB cable

Possible expiration pathway
(pre-VentMon)

(post-VentMon)

VentMon Airway Sensor
Tube

Computer
with/Arduino IDE and
Serial Monitor
supporting
configuration

Physical Test Lung

VentMon Enclosure /
MCU w/ OLED badge

Cat-5 Ethernet
cable or WiFi
connection

http://ventmon.coslabs.com/

Browser pointed at
breath_plot.html at Data Lake

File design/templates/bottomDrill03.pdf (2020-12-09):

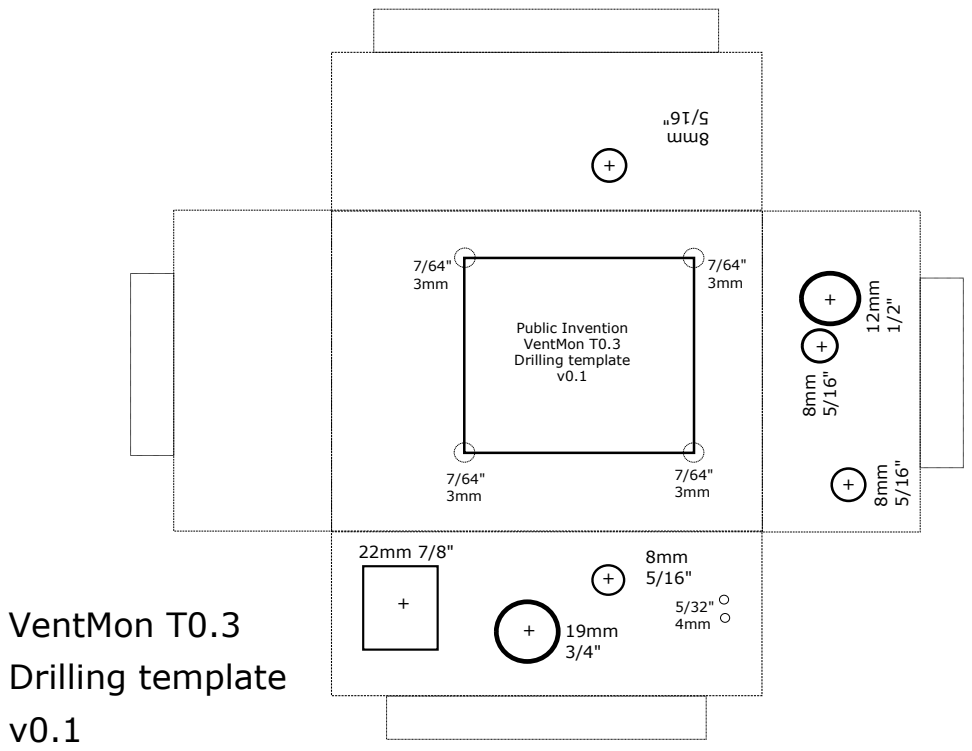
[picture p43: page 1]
VentMon T0.3 Drilling template v0.1; Public Invention VentMon T0.3 Drilling template v0.1

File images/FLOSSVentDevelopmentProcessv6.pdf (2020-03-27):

# Possible COVID-19 Open Source/DIY Ventilator Deployment

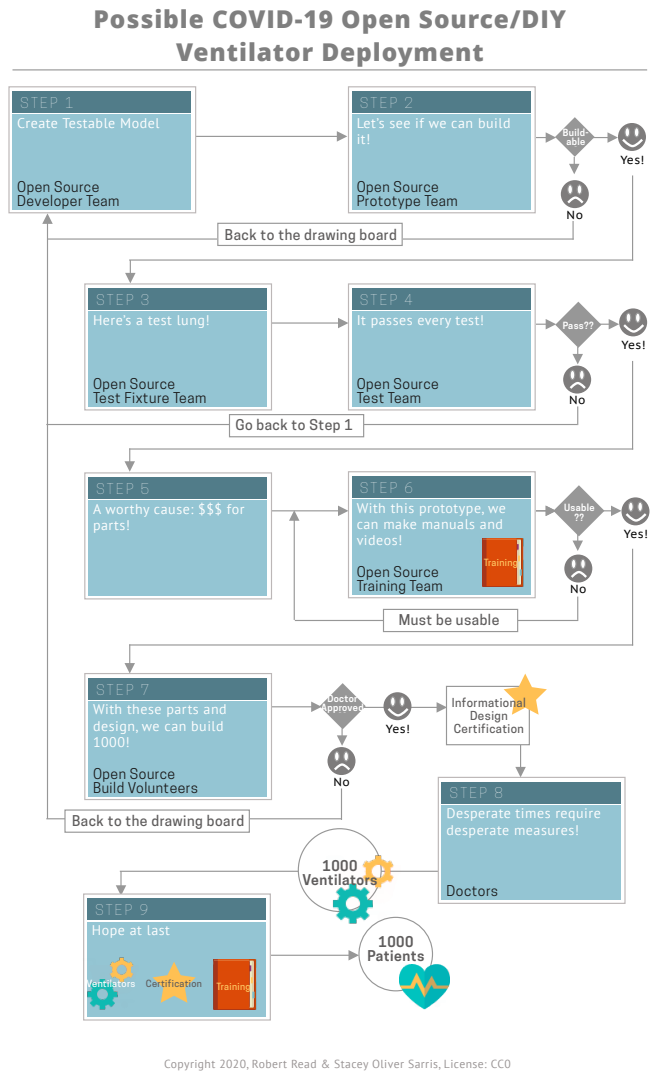
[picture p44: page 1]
1000 Ventilators; 1000 Patients; Usable ??; Yes!; Pass??; Doctor Approved; Build- able; Open Source Test Team; Open Source Build Volunteers; Ventilators Certification; Training; Informational Design Certification

STEP 1
Create Testable Model

STEP 2
Let’s see if we can build
With these parts and
design, we can build
Open Source
Prototype Team

Developer Team

Back to the drawing board

STEP 3
Here’s a test lung!

STEP 4
It passes every test!

Test Fixture Team

Go back to Step 1

STEP 5
A worthy cause: $$$ for
parts!

STEP 6
With this prototype, we
can make manuals and
videos!
Training Team

Must be usable

STEP 7

STEP 8
Desperate times require
desperate measures!
Doctors

STEP 9
Hope at last

Copyright 2020, Robert Read & Stacey Oliver Sarris, License: CC0

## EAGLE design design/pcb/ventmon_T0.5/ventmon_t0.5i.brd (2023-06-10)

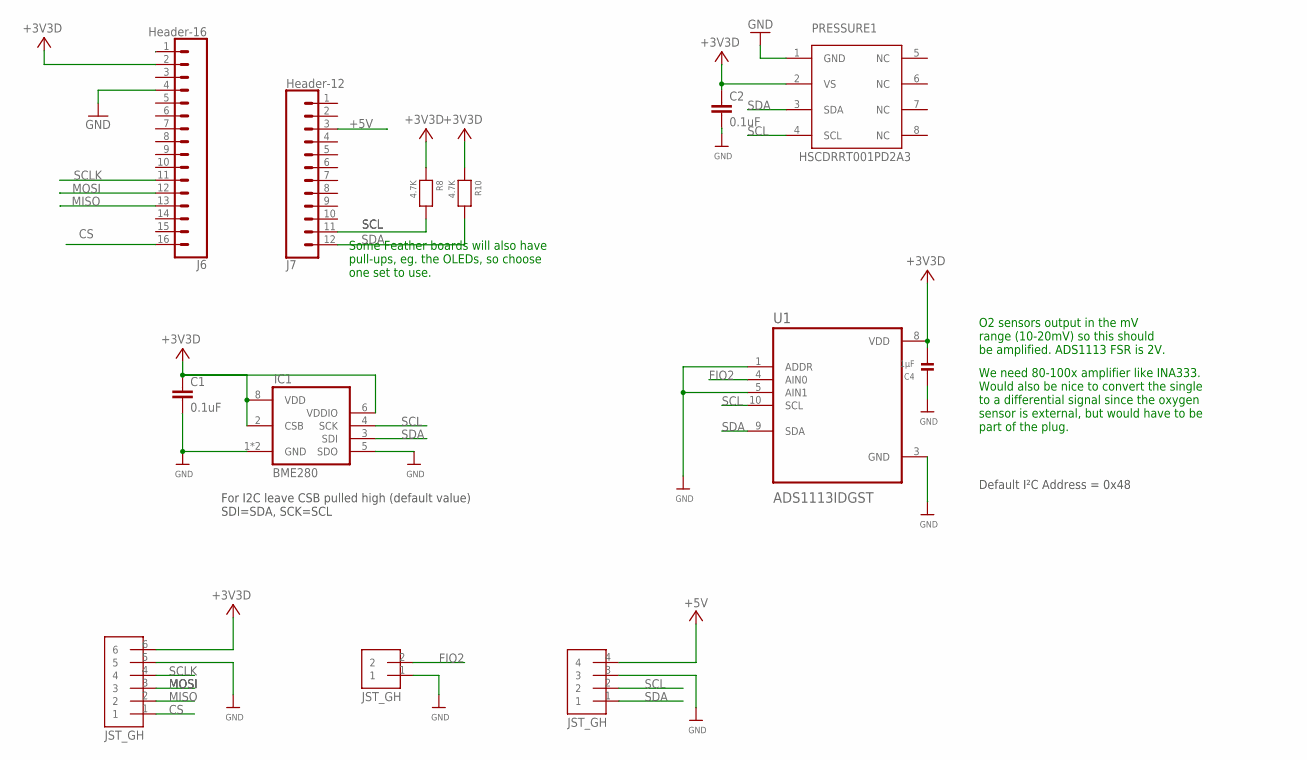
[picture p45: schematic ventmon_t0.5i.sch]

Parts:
C1, C2: 0.1uF; 0603
C4: 1µF; 0603
IC1: BME280
J6: Header-16; 1X16
J7: Header-12; 1X12
PRESSURE1: HSCDRRT001PD2A3; DIP1330W46P254L1000H616Q8B
R8, R10: 4.7K; 0603
U1: ADS1113IDGST; SOP50P490X110-10N
U$5: JST_GH_4
U$6: JST_GH_6
U$12: JST_GH_2

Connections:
+3V3: C1.1, C2.1, C4.2, IC1.2 (CSB), IC1.6 (VDDIO), IC1.8 (VDD), J6.2, PRESSURE1.2 (VS), R8.1, R10.1, U1.8 (VDD), U$6.6
+5V: J7.3, U$5.4
CS: J6.16, U$6.1
FIO2: U1.4 (AIN0), U$12.2
GND: C1.2, C2.2, C4.1, IC1.1 (GND), IC1.5 (SDO), IC1.7 (GND), J6.4, PRESSURE1.1 (GND), U1.1 (ADDR), U1.3 (GND), U1.5 (AIN1), U$5.3, U$6.5, U$12.1
MISO: J6.13, U$6.2
MOSI: J6.12, U$6.3
SCL: IC1.4 (SCK), J7.11, PRESSURE1.4 (SCL), R8.2, U1.10 (SCL), U$5.2
SCLK: J6.11, U$6.4
SDA: IC1.3 (SDI), J7.12, PRESSURE1.3 (SDA), R10.2, U1.9 (SDA), U$5.1

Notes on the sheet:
For I2C leave CSB pulled high (default value) SDI=SDA, SCK=SCL
Default I²C Address = 0x48
O2 sensors output in the mV range (10-20mV) so this should be amplified. ADS1113 FSR is 2V.
We need 80-100x amplifier like INA333. Would also be nice to convert the single to a differential signal since the oxygen sensor is external, but would have to be part of the plug.
Some Feather boards will also have pull-ups, eg. the OLEDs, so choose one set to use.

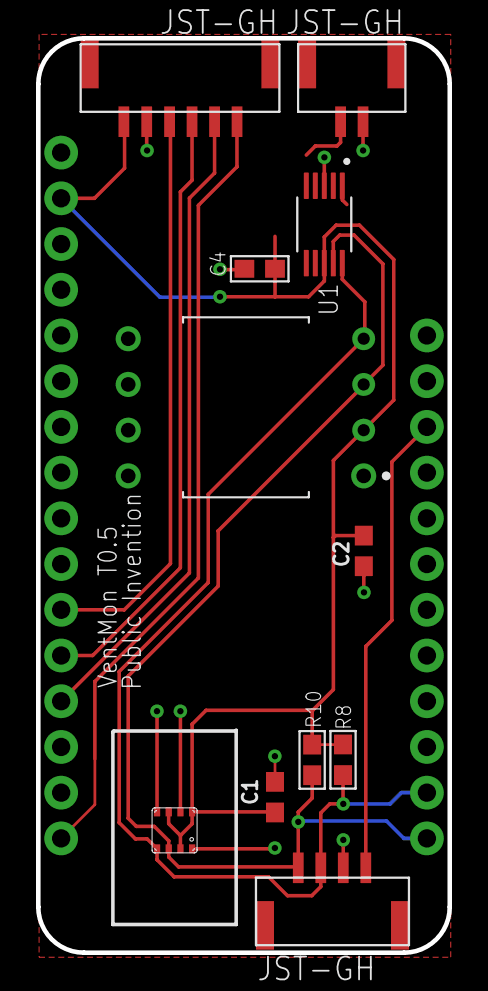
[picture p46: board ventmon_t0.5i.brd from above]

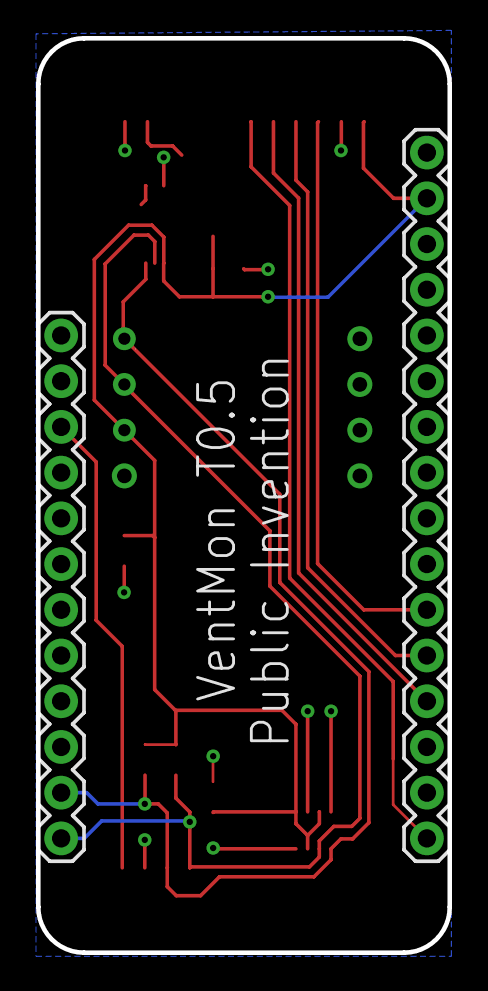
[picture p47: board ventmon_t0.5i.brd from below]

Board: 2 copper layers, 22.9 x 50.8 mm, 13 parts (2 on the bottom side), 10 nets.

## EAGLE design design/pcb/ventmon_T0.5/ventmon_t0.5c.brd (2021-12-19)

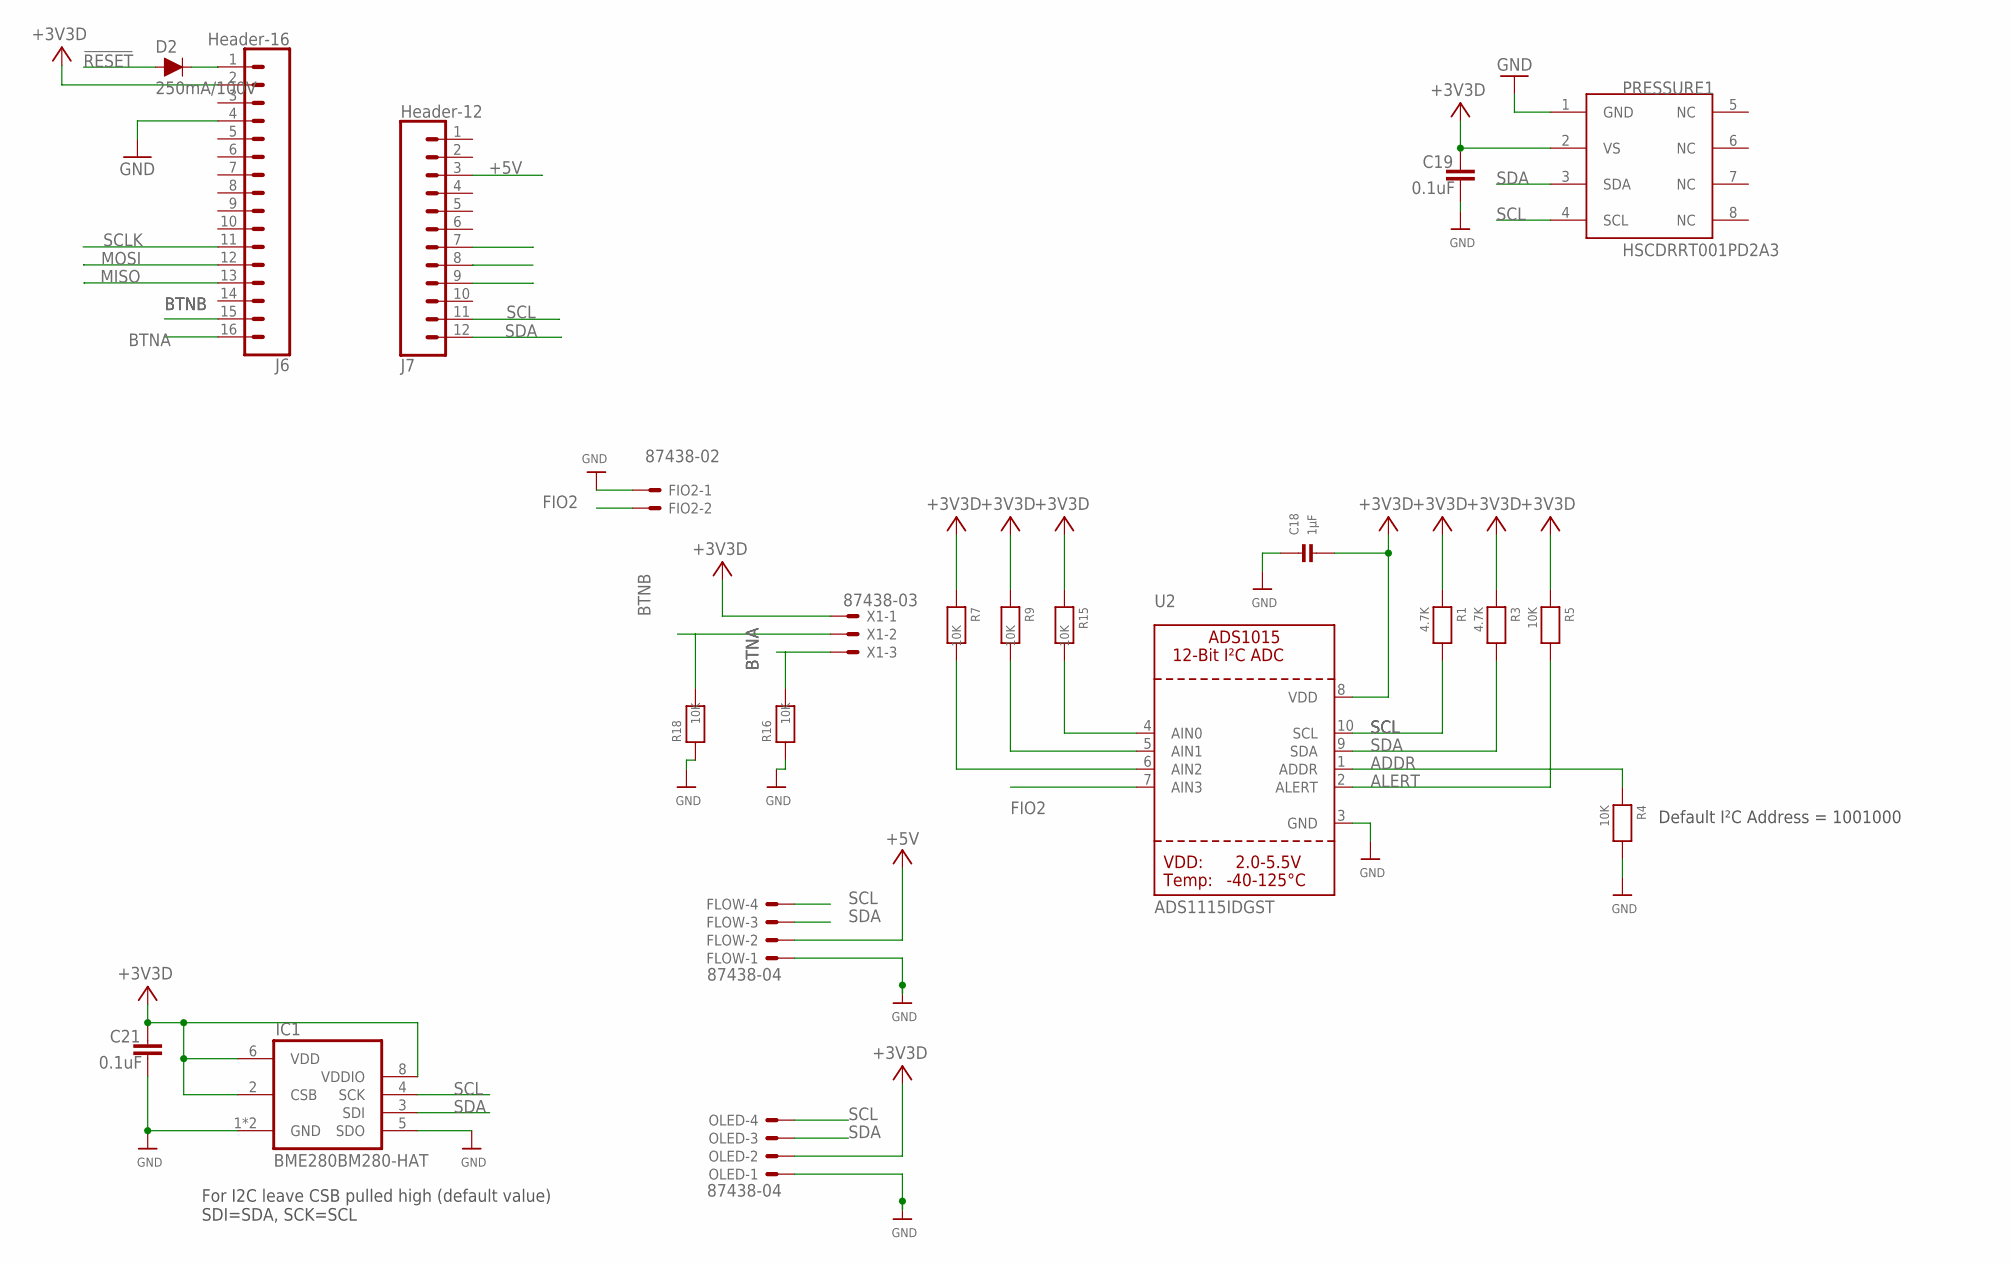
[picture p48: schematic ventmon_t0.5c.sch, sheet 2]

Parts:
C18: 1µF; 0603
C19, C21: 0.1uF; C0402_B
D2: 250mA/100V; SOD-323
FIO2: 87438-02
FLOW: 87438-04
IC1: BME280BM280-HAT; BME280-HAT
J6: Header-16; 1X16
J7: Header-12; 1X12
OLED: 87438-04
PRESSURE1: HSCDRRT001PD2A3; DIP1330W46P254L1000H616Q8B
R1, R3: 4.7K; 0603
R4, R5, R7, R9, R15, R16, R18: 10K; 0603
U2: ADS1115IDGST; MSOP10
X1: 87438-03

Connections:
!RESET: D2.A
+3V3: C18.2, C19.2, C21.2, IC1.2 (CSB), IC1.6 (VDD), IC1.8 (VDDIO), J6.2, OLED.2, PRESSURE1.2 (VS), R1.1, R3.1, R5.1, R7.1, R9.1, R15.1, U2.8 (VDD), X1.1
+5V: FLOW.2, J7.3
ADDR: R4.1, U2.1 (ADDR)
ALERT: R5.2, U2.2 (ALERT)
BTNA: J6.16, R16.2, X1.3
BTNB: J6.15, R18.2, X1.2
FIO2: FIO2.2, U2.7 (AIN3)
GND: C18.1, C19.1, C21.1, FIO2.1, FLOW.1, IC1.1 (GND), IC1.5 (SDO), IC1.7 (GND), J6.4, OLED.1, PRESSURE1.1 (GND), R4.2, R16.1, R18.1, U2.3 (GND)
MISO: J6.13
MOSI: J6.12
unnamed: D2.C, J6.1
unnamed: R7.2, U2.6 (AIN2)
unnamed: R9.2, U2.5 (AIN1)
unnamed: R15.2, U2.4 (AIN0)
SCL: FLOW.4, IC1.4 (SCK), J7.11, OLED.4, PRESSURE1.4 (SCL), R1.2, U2.10 (SCL)
SCLK: J6.11
SDA: FLOW.3, IC1.3 (SDI), J7.12, OLED.3, PRESSURE1.3 (SDA), R3.2, U2.9 (SDA)

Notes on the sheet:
Default I²C Address = 1001000
For I2C leave CSB pulled high (default value) SDI=SDA, SCK=SCL

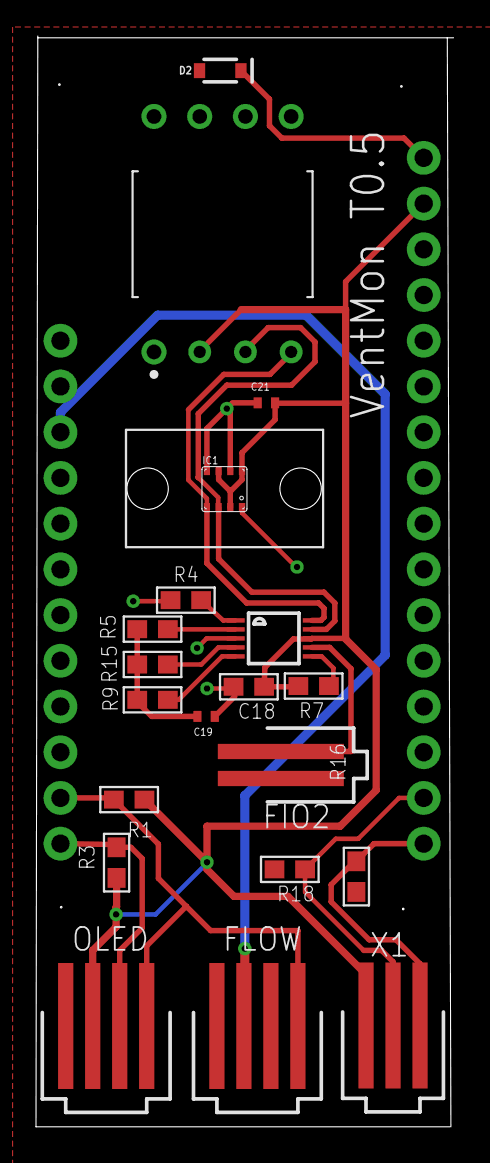
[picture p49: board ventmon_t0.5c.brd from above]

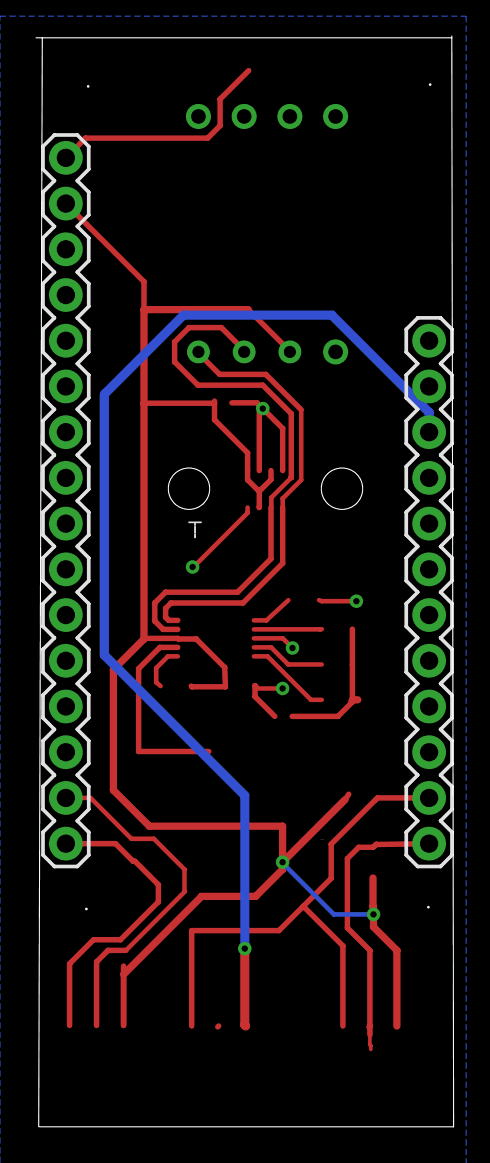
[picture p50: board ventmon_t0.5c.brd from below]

Board: 2 copper layers, 23.2 x 60.6 mm, 22 parts (2 on the bottom side), 14 nets.

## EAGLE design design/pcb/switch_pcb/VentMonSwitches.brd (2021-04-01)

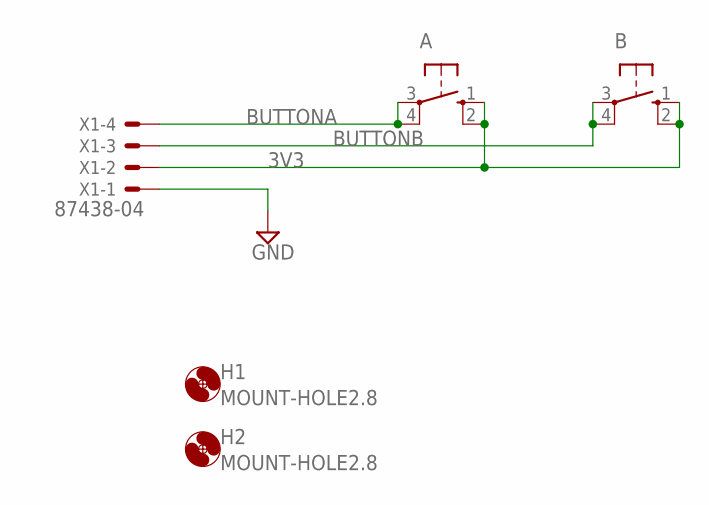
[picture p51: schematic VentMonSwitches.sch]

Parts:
A: 10-XX; B3F-10XX
B: 10-XX; B3F-10XX
H1, H2: MOUNT-HOLE2.8; 2,8
X1: 87438-04

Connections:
3V3: A.1 (S), A.2 (S1), B.1 (S), B.2 (S1), X1.2
BUTTONA: A.3, A.4 (P1), X1.4
BUTTONB: B.3, B.4 (P1), X1.3
GND: X1.1

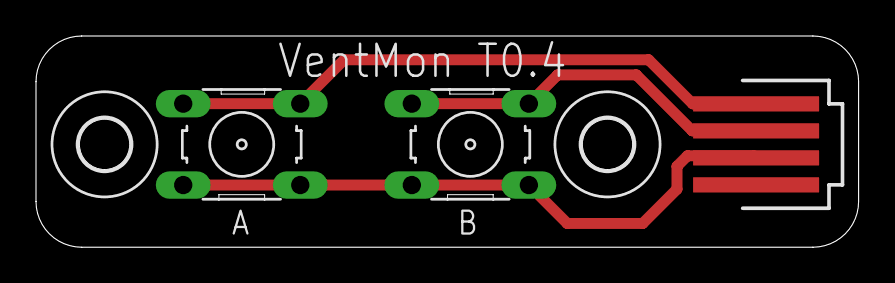
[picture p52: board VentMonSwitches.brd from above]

Board: 2 copper layers, 45.7 x 11.7 mm, 5 parts (0 on the bottom side), 3 nets.

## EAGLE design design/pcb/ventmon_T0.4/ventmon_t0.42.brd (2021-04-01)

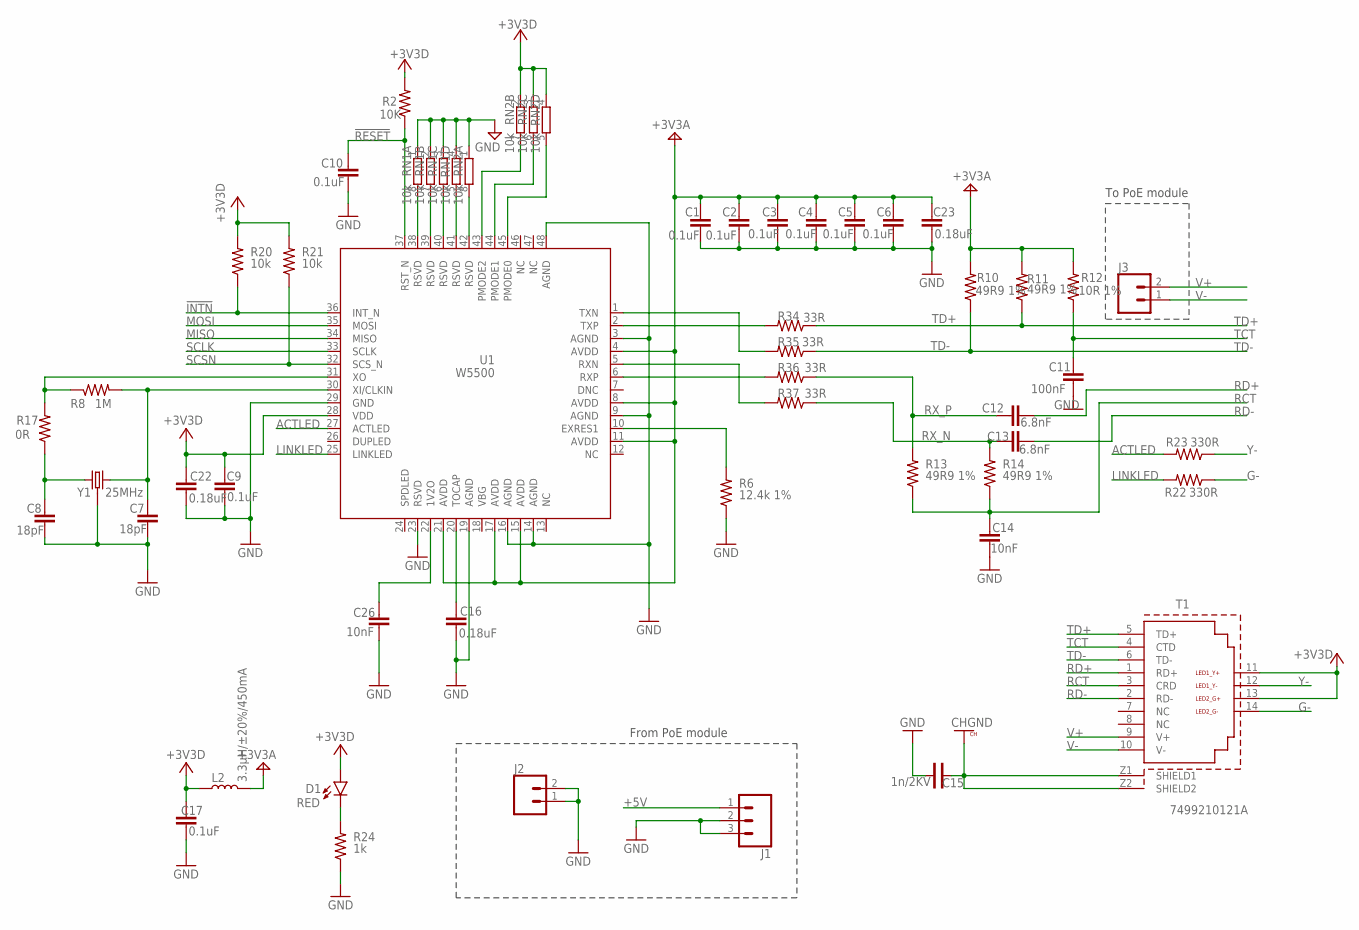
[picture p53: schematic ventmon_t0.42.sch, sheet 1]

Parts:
C1, C2, C3, C4, C5, C6, C9, C10, C17: 0.1uF; C0402_B
C7, C8: 18pF; C0402_B
C11: 100nF; C0402_B
C12, C13: 6.8nF; C0402_B
C14, C26: 10nF; C0402_B
C15: 1n/2KV; C-1808
C16, C22, C23: 0.18uF; 0603
D1: RED; LED-0603
J1: CONN_03; 1X03
J2, J3: CONN_02; 1X02
L2: 3.3µH/±20%/450mA; 0805
R2: 10K; R0402_B
R6: 12.4k 1%; R0402_B
R8: 1M; R0402_B
R10, R11, R13, R14: 49R9 1%; R0402_B
R12: 10R 1%; R0402_B
R17: 0R; R0402_B
R20, R21: 10k; R0402_B
R22, R23: 330R; R0402_B
R24: 1k; R0402_B
R34, R35, R36, R37: 33R; R0402_B
RN1, RN2: 10k; 4X0402ARV341
T1: 7499210121A
U1: W5500
Y1: 25MHz; CRYSTAL-SMD-3.2X2.5MM

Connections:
!INTN: R20.1, U1.36 (INT_N); also elsewhere on the board
!RESET: C10.2, R2.1, U1.37 (RST_N); also elsewhere on the board
+3V3: C9.2, C17.2, C22.1, D1.A, L2.1, R2.2, R20.2, R21.2, RN2.2 (1), RN2.3 (1), RN2.4 (1), T1.11 (LED1_Y+), T1.13 (LED2_G+), U1.28 (VDD); also elsewhere on the board
+3V3A: C1.2, C2.2, C3.2, C4.2, C5.2, C6.2, C23.1, L2.2, R10.2, R11.2, R12.2, U1.4 (AVDD), U1.8 (AVDD), U1.11 (AVDD), U1.15 (AVDD), U1.17 (AVDD), U1.21 (AVDD)
+5V: J1.1; also elsewhere on the board
ACTLED: R23.2, U1.27 (ACTLED)
CHGND: C15.P$1, T1.Z1 (SHIELD1), T1.Z2 (SHIELD2)
G-: R22.1, T1.14 (LED2_G-)
GND: C1.1, C2.1, C3.1, C4.1, C5.1, C6.1, C7.1, C8.1, C9.1, C10.1, C11.1, C14.1, C15.P$2, C16.2, C17.1, C22.2, C23.2, C26.1, J1.2, J1.3, J2.1, J2.2, R6.1, R24.1, RN1.1, RN1.2 (1), RN1.3 (1), RN1.4 (1), RN2.1, U1.3 (AGND), U1.9 (AGND), U1.14 (AGND), U1.16 (AGND), U1.19 (AGND), U1.23 (RSVD), U1.29 (GND), U1.48 (AGND), Y1.2 (3), Y1.4 (3); also elsewhere on the board
LINKLED: R22.2, U1.25 (LINKLED)
MISO: U1.34 (MISO); also elsewhere on the board
MOSI: U1.35 (MOSI); also elsewhere on the board
unnamed: RN2.7 (2), U1.43 (PMODE2)
unnamed: RN2.6 (2), U1.44 (PMODE1)
unnamed: RN2.5 (2), U1.45 (PMODE0)
unnamed: RN1.8 (2), U1.38 (RSVD)
unnamed: RN1.7 (2), U1.39 (RSVD)
unnamed: RN1.6 (2), U1.40 (RSVD)
unnamed: RN1.5 (2), U1.41 (RSVD)
unnamed: RN2.8 (2), U1.42 (RSVD)
unnamed: C8.2, R17.1, Y1.1
unnamed: C16.1, U1.20 (TOCAP)
unnamed: C26.2, U1.22 (1V2O)
unnamed: R6.2, U1.10 (EXRES1)
unnamed: D1.C, R24.2
unnamed: R8.1, R17.2, U1.31 (XO)
unnamed: C7.2, R8.2, U1.30 (XI/CLKIN), Y1.3 (2)
RCT: C14.2, R13.1, R14.1, T1.3 (CRD)
RD+: C12.2, T1.1 (RD+)
RD-: C13.2, T1.2 (RD-)
RX_N: C13.1, R14.2, R37.1
RX_P: C12.1, R13.2, R36.1
R_N: R37.2, U1.5 (RXN)
R_P: R36.2, U1.6 (RXP)
SCLK: U1.33 (SCLK); also elsewhere on the board
SCSN: R21.1, U1.32 (SCS_N); also elsewhere on the board
TCT: C11.2, R12.1, T1.4 (CTD)
TD+: R11.1, R34.1, T1.5 (TD+)
TD-: R10.1, R35.1, T1.6 (TD-)
T_N: R35.2, U1.1 (TXN)
T_P: R34.2, U1.2 (TXP)
V+: J3.2, T1.9 (V+)
V-: J3.1, T1.10 (V-)
Y-: R23.1, T1.12 (LED1_Y-)

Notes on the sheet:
To PoE module
From PoE module

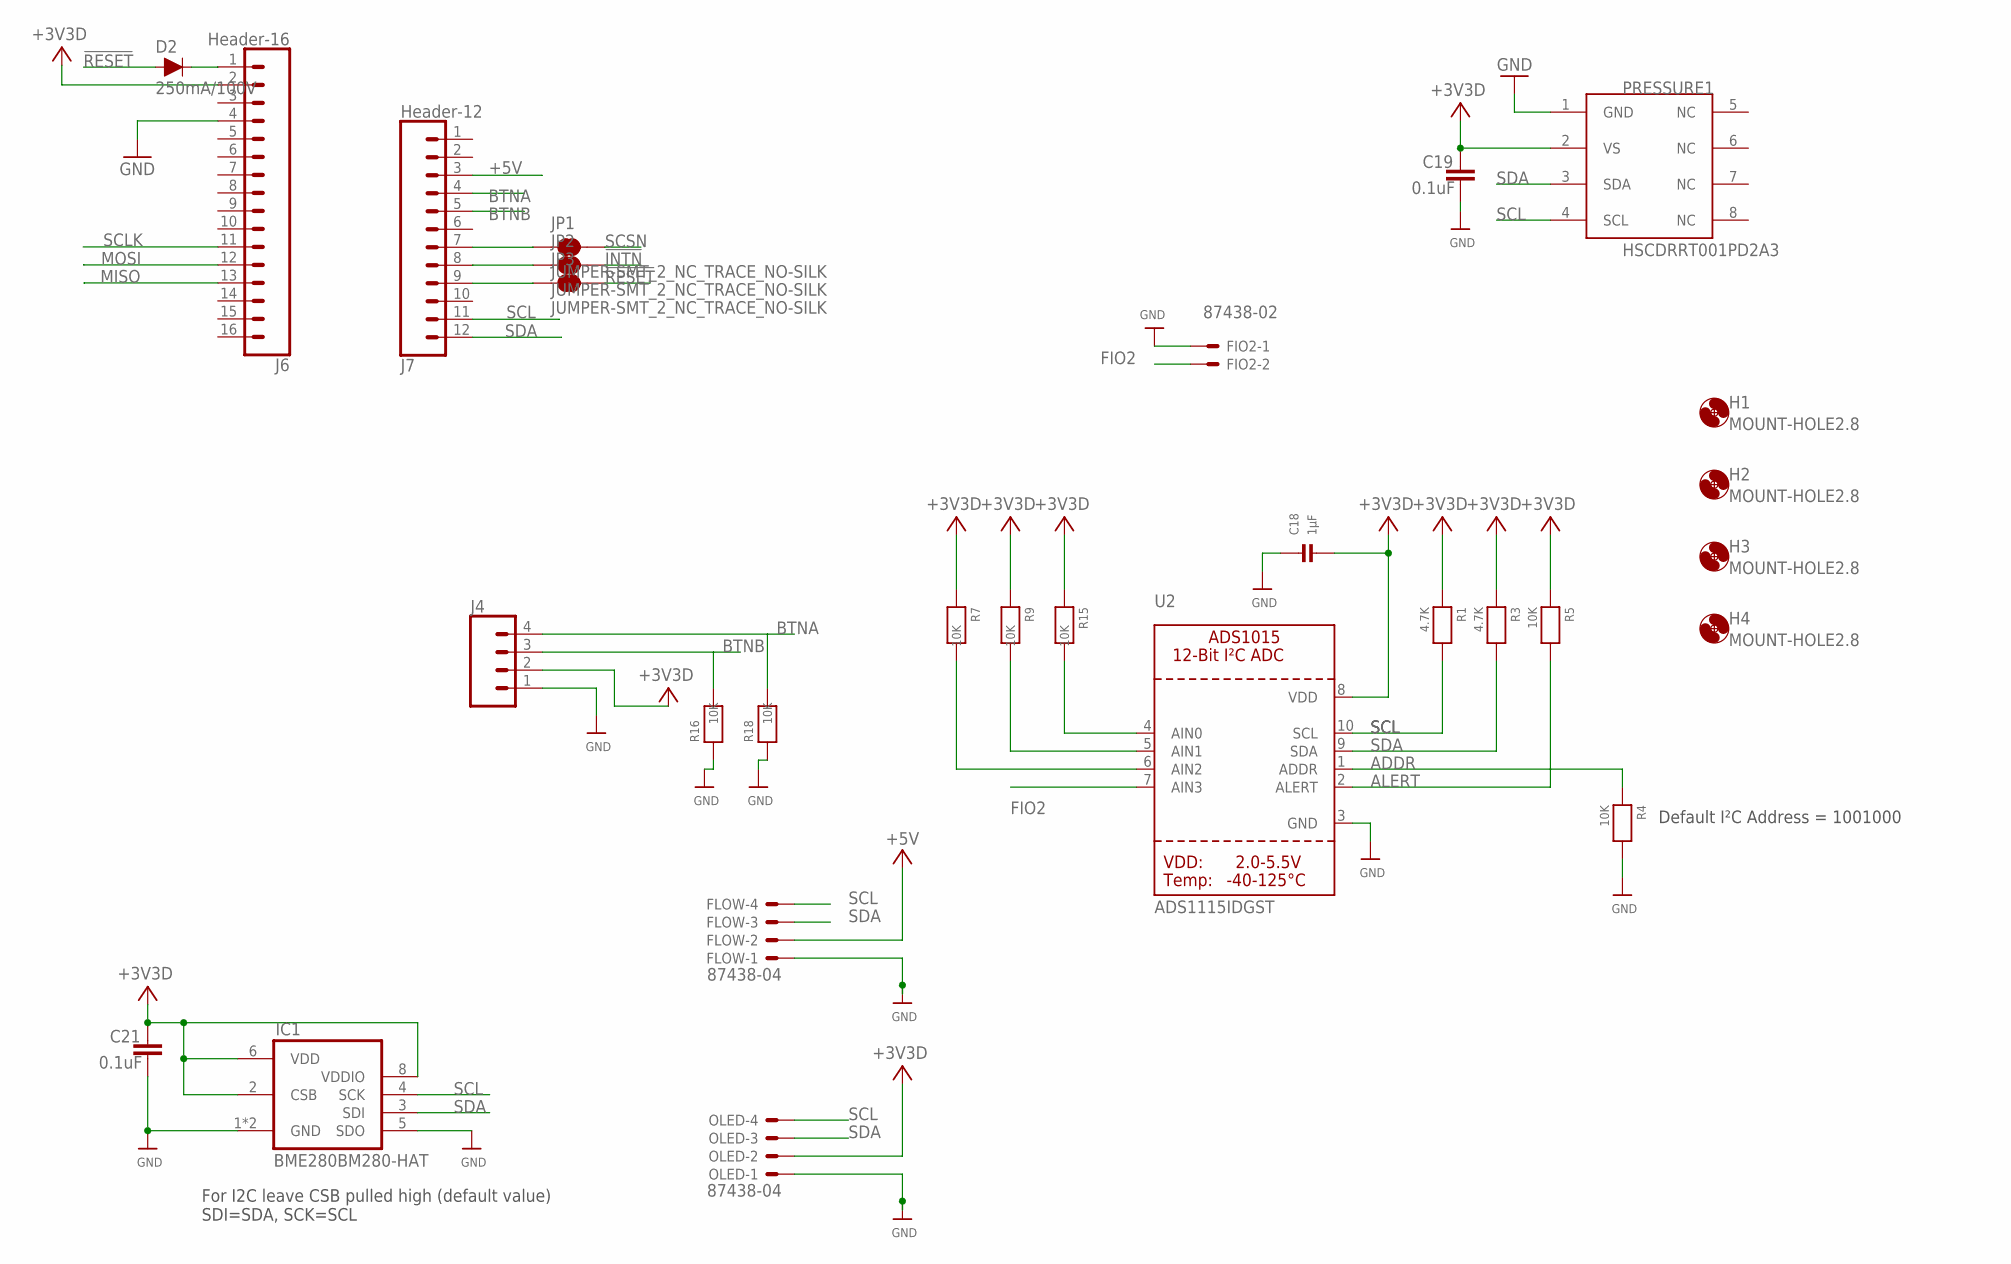
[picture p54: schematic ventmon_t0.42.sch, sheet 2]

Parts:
C18: 1µF; 0805
C19, C21: 0.1uF; C0402_B
D2: 250mA/100V; SOD-323
FIO2: 87438-02
FLOW: 87438-04
H1, H2, H3, H4: MOUNT-HOLE2.8; 2,8
IC1: BME280BM280-HAT; BME280-HAT
J4: CONN_04POLAR; MOLEX-1X4
J6: Header-16; 1X16
J7: Header-12; 1X12
JP1, JP2, JP3: JUMPER-SMT_2_NC_TRACE_NO-SILK; SMT-JUMPER_2_NC_TRACE_NO-SILK
OLED: 87438-04
PRESSURE1: HSCDRRT001PD2A3; DIP1330W46P254L1000H616Q8B
R1, R3: 4.7K; 0805
R4, R5, R7, R9, R15, R16, R18: 10K; 0805
U2: ADS1115IDGST; MSOP10

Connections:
!INTN: JP2.2; also elsewhere on the board
!RESET: D2.A, JP3.2; also elsewhere on the board
+3V3: C18.2, C19.2, C21.2, IC1.2 (CSB), IC1.6 (VDD), IC1.8 (VDDIO), J4.2, J6.2, OLED.2, PRESSURE1.2 (VS), R1.1, R3.1, R5.1, R7.1, R9.1, R15.1, U2.8 (VDD); also elsewhere on the board
+5V: FLOW.2, J7.3; also elsewhere on the board
ADDR: R4.1, U2.1 (ADDR)
ALERT: R5.2, U2.2 (ALERT)
BTNA: J4.4, J7.4, R18.2
BTNB: J4.3, J7.5, R16.2
FIO2: FIO2.2, U2.7 (AIN3)
GND: C18.1, C19.1, C21.1, FIO2.1, FLOW.1, IC1.1 (GND), IC1.5 (SDO), IC1.7 (GND), J4.1, J6.4, OLED.1, PRESSURE1.1 (GND), R4.2, R16.1, R18.1, U2.3 (GND); also elsewhere on the board
MISO: J6.13; also elsewhere on the board
MOSI: J6.12; also elsewhere on the board
unnamed: D2.C, J6.1
unnamed: J7.7, JP1.1
unnamed: J7.8, JP2.1
unnamed: J7.9, JP3.1
unnamed: R7.2, U2.6 (AIN2)
unnamed: R9.2, U2.5 (AIN1)
unnamed: R15.2, U2.4 (AIN0)
SCL: FLOW.4, IC1.4 (SCK), J7.11, OLED.4, PRESSURE1.4 (SCL), R1.2, U2.10 (SCL)
SCLK: J6.11; also elsewhere on the board
SCSN: JP1.2; also elsewhere on the board
SDA: FLOW.3, IC1.3 (SDI), J7.12, OLED.3, PRESSURE1.3 (SDA), R3.2, U2.9 (SDA)

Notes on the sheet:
Default I²C Address = 1001000
For I2C leave CSB pulled high (default value) SDI=SDA, SCK=SCL

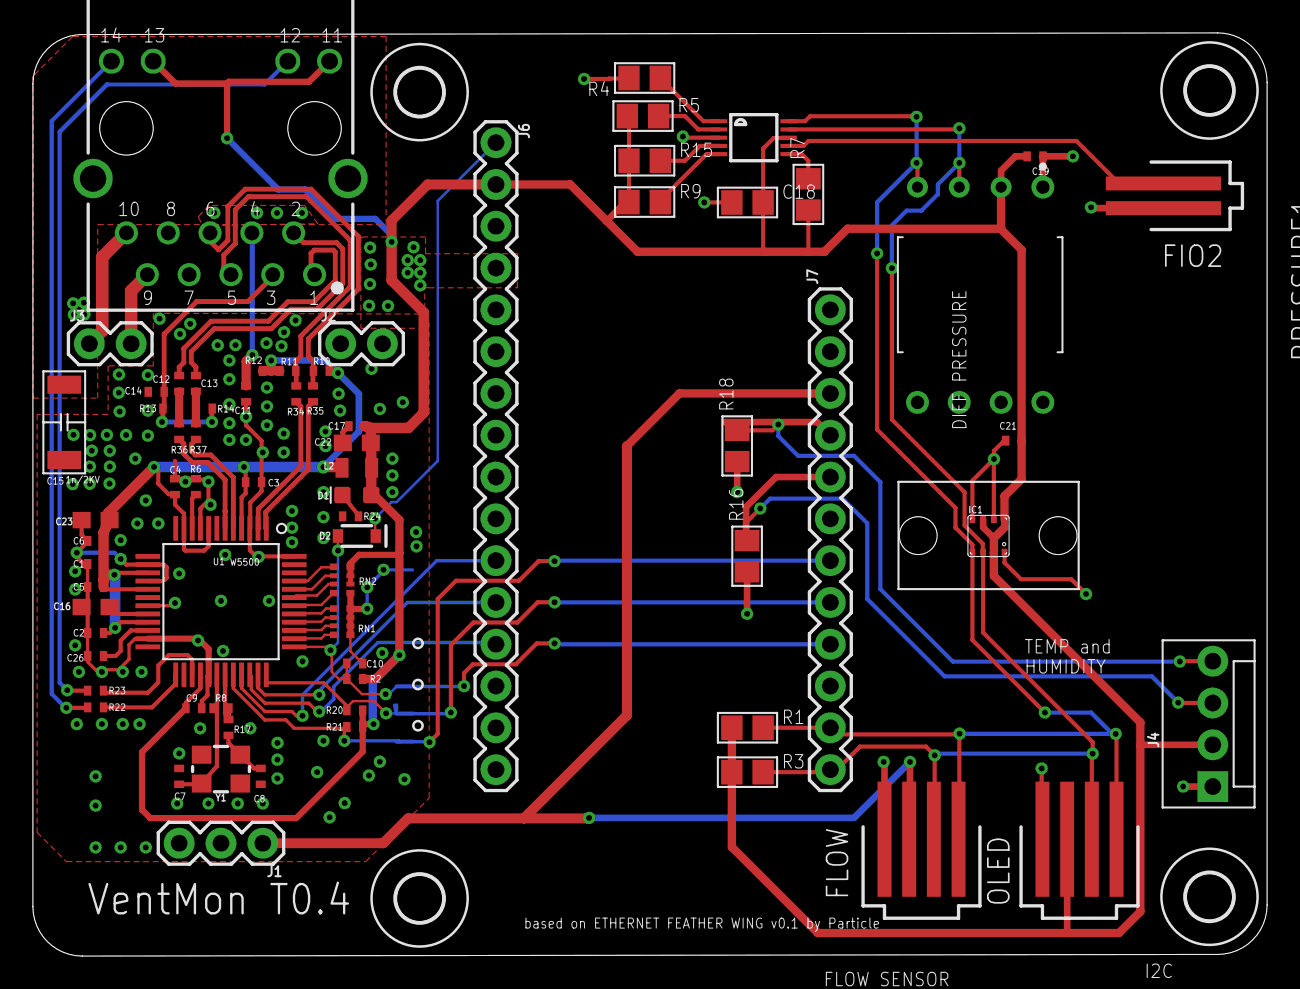
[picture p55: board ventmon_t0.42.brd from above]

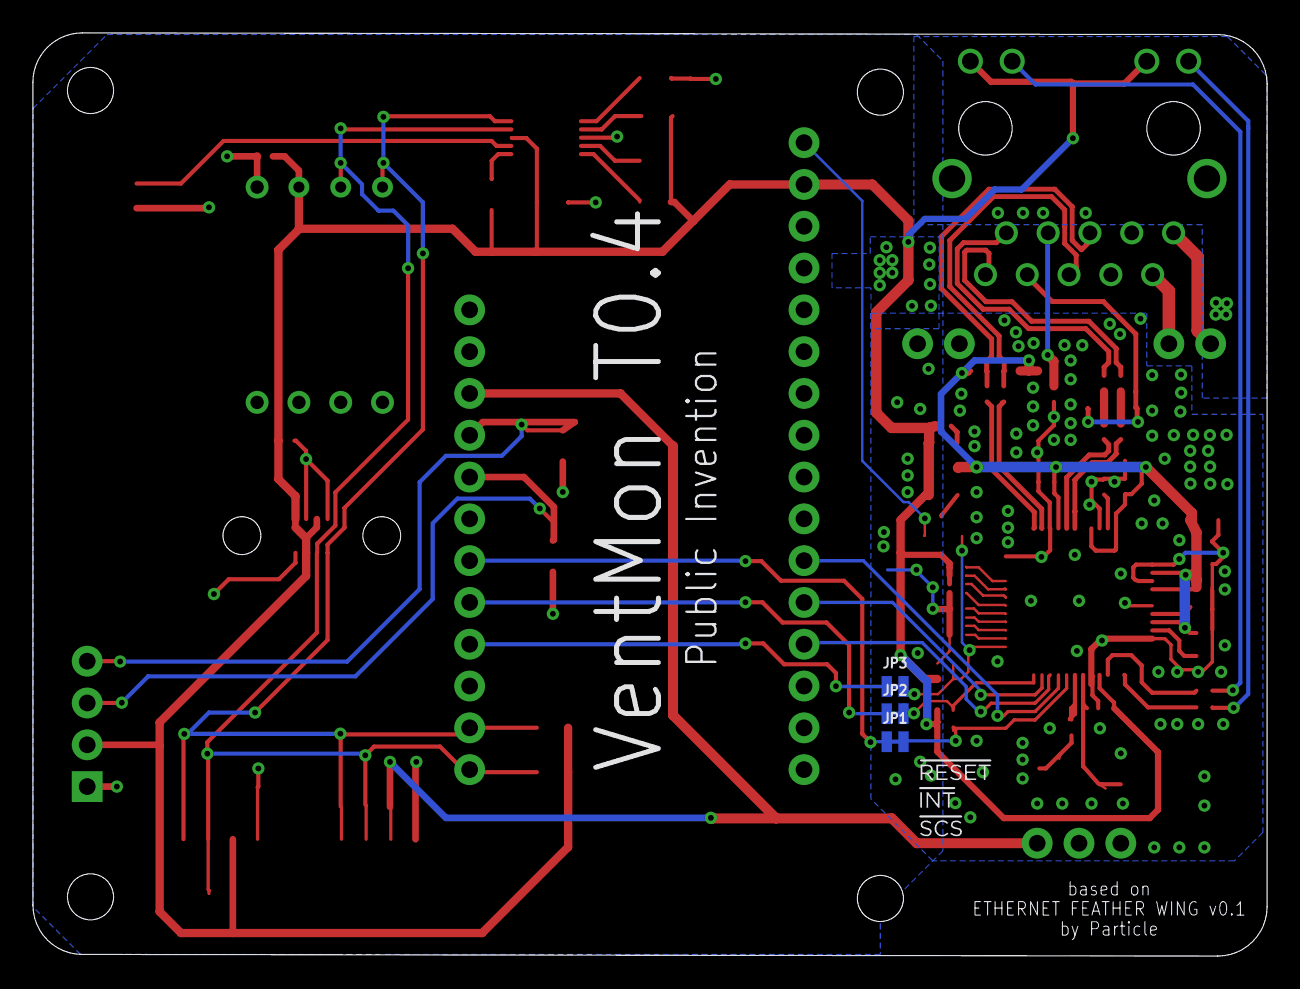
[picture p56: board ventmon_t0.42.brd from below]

Board: 2 copper layers, 75.0 x 56.1 mm, 77 parts (3 on the bottom side), 58 nets.

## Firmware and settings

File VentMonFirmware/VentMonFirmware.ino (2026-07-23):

/***************************************************************************
  Copyright Robert L. Read, 2023
  Ben Coombs, 2023
  Networking code by Geoff Mulligan 2020
  Additional work by Lauria Clarke 2020
  designed to support ethernet using esp wifi chip

  Modififications released under BSD to avoid complication (I prefer GPL).
 ***************************************************************************/

 /*
 Public Invention's Ventmon-Ventilator-Inline-Test-Monitor Project is an attempt
 to build a "test fixture" capable of running a 48-hour test on any ventilator
 design and collecting data on many important parameters. We hope to create a
 "gold standard" test that all DIY teams can work to; but this project will
 proceed in parallel with that. The idea is to make a standalone inline device
 plugged into the airway. It serves a dual purpose as a monitor/alarm when used
 on an actual patient, and a test device for testing prototype ventilators. It
 also allows for burnin. Copyright (C) 2021 Robert L. Read, Lauria Clarke,
 Ben Coombs, Darío Hereñú, and Geoff Mulligan.

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
 You should have received a copy of the GNU Affero General Public License
 along with this program.  If not, see <https://www.gnu.org/licenses/>.
 */

#include <Dns.h>
#include <PIRDS.h>
#include <Wire.h>
#include <limits.h>
#include <SPI.h>
#include <Ethernet.h>
#include <EthernetUdp.h>
#include <WiFi.h>
#include <WiFiUdp.h>

#include <EEPROM.h>
#include <SFM3X00.h>
#include <Adafruit_Sensor.h>
#include <Adafruit_BME680.h>
#include <Adafruit_BME280.h>
#include <Adafruit_ADS1X15.h>
#include <Adafruit_GFX.h>


#define V5
//#define V4 // V0.4 VentMon with the new 128x64 OLED Screen
//#define DEBUG_1


#ifdef V5
#include <Adafruit_SH110X.h>
#else
#include <Adafruit_SSD1306.h>
#endif


#define BAUD_RATE 500000

#define LOGO_HEIGHT   64
#define LOGO_WIDTH    128
// 'logo-tight', 92x64px
/*const unsigned char logo_bmp [] PROGMEM = {
  // 'logo-tight, 92x64px
  0x00, 0x00, 0x00, 0x00, 0x00, 0x00, 0x00, 0x00, 0x00, 0x00, 0x00, 0x00, 0x00, 0x18, 0x00, 0x00,
  0x00, 0x00, 0x00, 0x00, 0x00, 0x00, 0x00, 0x00, 0x00, 0x3f, 0xff, 0xe1, 0xff, 0xc3, 0xff, 0x7f,
  0xff, 0x00, 0x40, 0x00, 0x00, 0x27, 0xff, 0xf9, 0xff, 0xc3, 0xff, 0x7f, 0xff, 0xc3, 0xc0, 0x00,
  0x00, 0x37, 0xff, 0xff, 0xff, 0xc3, 0xff, 0x7f, 0xff, 0xff, 0xc0, 0x00, 0x00, 0x1f, 0xff, 0xff,
  0xff, 0xc3, 0xff, 0x7f, 0xff, 0xff, 0xc0, 0x00, 0x00, 0x01, 0xe0, 0x3f, 0x1c, 0x00, 0x3c, 0x0f,
  0x01, 0xff, 0xc0, 0x00, 0x00, 0x01, 0xe0, 0x0f, 0x9c, 0x00, 0x3c, 0x0f, 0x00, 0x7f, 0xc0, 0x00,
  0x00, 0x01, 0xec, 0x07, 0x9c, 0x80, 0x3c, 0x0f, 0x00, 0x7f, 0x80, 0x00, 0x00, 0x01, 0xfc, 0x07,
  0xdd, 0xc0, 0x3c, 0x0f, 0x00, 0x7f, 0x80, 0x00, 0x00, 0x61, 0xfc, 0x03, 0xdf, 0xc0, 0x3c, 0x0f,
  0x00, 0x7f, 0x80, 0x00, 0x00, 0x71, 0xfc, 0x03, 0xdf, 0xc0, 0x3c, 0x0f, 0x00, 0xff, 0x00, 0x00,
  0x00, 0xf9, 0xfc, 0x03, 0xdf, 0x80, 0x3c, 0x0f, 0xff, 0xff, 0x00, 0x00, 0x00, 0xfd, 0xfc, 0x03,
  0xdf, 0x00, 0x3c, 0x0f, 0xff, 0xfd, 0xf0, 0x00, 0x00, 0xff, 0xfc, 0x07, 0xdc, 0x00, 0x3c, 0x0f,
  0xff, 0xfb, 0xe0, 0x00, 0x00, 0x7f, 0xf8, 0x07, 0x9c, 0x00, 0x3c, 0x0f, 0xff, 0xff, 0xe0, 0x00,
  0x00, 0x7f, 0xf8, 0x0f, 0x9c, 0x00, 0x3c, 0x0f, 0x00, 0xff, 0xc0, 0x00, 0x00, 0x1f, 0xf0, 0x3f,
  0x1c, 0x00, 0x3f, 0xcf, 0x00, 0x1f, 0x80, 0x00, 0x00, 0x0f, 0xff, 0xfe, 0x1c, 0x00, 0x3f, 0xaf,
  0x00, 0x1f, 0x00, 0x00, 0x00, 0x01, 0xff, 0xfc, 0x1c, 0x00, 0x3c, 0x5f, 0x00, 0x0f, 0x00, 0x00,
  0x00, 0x01, 0xff, 0xf8, 0x1c, 0x00, 0x3c, 0x3f, 0x00, 0x0f, 0x00, 0x00, 0x00, 0x01, 0xff, 0xc0,
  0x1f, 0xff, 0xf8, 0x1f, 0x00, 0x0f, 0x00, 0x00, 0x00, 0x01, 0xe0, 0x00, 0x1e, 0x00, 0x78, 0x0f,
  0x00, 0x1f, 0x00, 0x00, 0x00, 0x01, 0xe0, 0x00, 0x1f, 0x00, 0xf8, 0x0f, 0x00, 0x1e, 0x00, 0x00,
  0x00, 0x01, 0xe0, 0x00, 0x1f, 0x81, 0xf0, 0x0f, 0x00, 0x3e, 0x00, 0x00, 0x00, 0x1f, 0xf8, 0x00,
  0x0f, 0xff, 0xf3, 0xff, 0xff, 0xfc, 0x00, 0x00, 0x00, 0x37, 0xfc, 0x00, 0x07, 0xff, 0xe6, 0xff,
  0xff, 0xfc, 0x00, 0x00, 0x00, 0x37, 0xfc, 0x00, 0x03, 0xff, 0xc6, 0x7f, 0xff, 0xfe, 0x00, 0x00,
  0x00, 0x1f, 0xfc, 0x00, 0x00, 0xff, 0x07, 0xff, 0xff, 0xc7, 0x00, 0x00, 0x00, 0x0c, 0x80, 0x00,
  0x18, 0x38, 0x01, 0x80, 0x70, 0x03, 0x80, 0x00, 0x00, 0x18, 0x83, 0x1c, 0x3c, 0x38, 0x00, 0x00,
  0x70, 0x01, 0xe0, 0x00, 0x00, 0x3f, 0xff, 0xbf, 0xfc, 0x3f, 0xfc, 0x3f, 0xf8, 0xff, 0xf0, 0x00,
  0x00, 0x27, 0xfc, 0xf7, 0xfe, 0x27, 0xfc, 0x3f, 0xc8, 0xff, 0x90, 0x00, 0x00, 0x3f, 0xff, 0xbf,
  0xfe, 0x77, 0xfc, 0x3f, 0xf8, 0xff, 0xb0, 0x00, 0x00, 0x1f, 0xff, 0x9f, 0xff, 0xff, 0xfc, 0x3f,
  0xf0, 0xff, 0xe0, 0x00, 0x00, 0x00, 0xf9, 0x08, 0xff, 0xc1, 0xe4, 0x0f, 0x20, 0x1e, 0x20, 0x00,
  0x00, 0x00, 0xf9, 0x08, 0xff, 0xc1, 0xe4, 0x0f, 0xa0, 0x1e, 0x20, 0x00, 0x00, 0x00, 0xf9, 0x08,
  0xff, 0x81, 0xe4, 0x7f, 0xbf, 0xfe, 0x20, 0x00, 0x00, 0x00, 0xf9, 0x08, 0xff, 0x01, 0xe4, 0x7f,
  0x80, 0x3c, 0x20, 0x00, 0x00, 0x00, 0xf9, 0x08, 0xff, 0x81, 0xe4, 0x3f, 0xc0, 0x3c, 0x20, 0x00,
  0x00, 0x00, 0xf9, 0x08, 0xf7, 0xc1, 0xe4, 0x3f, 0xc0, 0x7c, 0x20, 0x00, 0x00, 0x02, 0xf9, 0x08,
  0xf7, 0xc1, 0xe4, 0x1f, 0xc0, 0x78, 0x20, 0x00, 0x00, 0x07, 0xff, 0xff, 0xf3, 0xe1, 0xe4, 0x0f,
  0xe0, 0x78, 0x20, 0x00, 0x00, 0x07, 0xf0, 0x00, 0xf1, 0xe1, 0xe4, 0x01, 0xe0, 0xf8, 0x20, 0x00,
  0x00, 0x03, 0xf0, 0x00, 0xf1, 0xf1, 0xe4, 0x01, 0xf0, 0xf0, 0x20, 0x00, 0x00, 0x00, 0xf0, 0x00,
  0xf3, 0xf9, 0xe4, 0x00, 0xf0, 0xf0, 0x20, 0x00, 0x00, 0x00, 0xf0, 0x00, 0xf6, 0x79, 0xe4, 0x00,
  0xf1, 0xe0, 0x20, 0x00, 0x00, 0x00, 0xf0, 0x00, 0xf4, 0x7d, 0xe4, 0x00, 0xf9, 0xe0, 0x20, 0x00,
  0x00, 0x00, 0xf0, 0x00, 0xf4, 0x3f, 0xe4, 0x00, 0x7b, 0xe0, 0x20, 0x00, 0x00, 0x00, 0xf0, 0x00,
  0xf4, 0x3f, 0xe4, 0x00, 0x7b, 0xc0, 0x20, 0x00, 0x00, 0x00, 0xff, 0xff, 0xf4, 0x1f, 0xe7, 0xff,
  0xff, 0xc0, 0x20, 0x00, 0x00, 0x00, 0xf0, 0x00, 0xf4, 0x0f, 0xe0, 0x00, 0x3f, 0xc0, 0x20, 0x00,
  0x00, 0x00, 0xf7, 0xfe, 0xf4, 0x0f, 0xe0, 0x00, 0x3f, 0x80, 0x20, 0x00, 0x00, 0x00, 0xf4, 0x02,
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
};*/

const unsigned char logo_bmp [] PROGMEM = {
  // 'ventmon 8bit logo, 128x64px
  0x00, 0x00, 0x00, 0x00, 0x00, 0x00, 0x00, 0x00, 0x00, 0x00, 0x00, 0x00, 0x00, 0x00, 0x00, 0x00,
  0x00, 0x00, 0x00, 0x00, 0x00, 0x00, 0x00, 0x00, 0x00, 0x00, 0x00, 0x00, 0x00, 0x00, 0x00, 0x00,
  0x00, 0x00, 0x00, 0x00, 0x00, 0x00, 0x00, 0x00, 0x00, 0x00, 0x00, 0x00, 0x08, 0x00, 0x00, 0x00,
  0x00, 0x00, 0x00, 0x03, 0x00, 0x00, 0x00, 0x00, 0x00, 0x00, 0x00, 0x00, 0x18, 0x00, 0x00, 0x00,
  0x00, 0x00, 0x00, 0x04, 0xff, 0xf0, 0x3f, 0xf0, 0xff, 0xdf, 0xff, 0x80, 0x7c, 0x00, 0x00, 0x00,
  0x00, 0x00, 0x00, 0x04, 0xff, 0xfe, 0x3f, 0xf0, 0xff, 0xdf, 0xff, 0xe0, 0xfc, 0x00, 0x00, 0x00,
  0x00, 0x00, 0x00, 0x03, 0xff, 0xff, 0x3f, 0xf0, 0xff, 0xdf, 0xff, 0xf8, 0xdc, 0x00, 0x00, 0x00,
  0x00, 0x00, 0x00, 0x00, 0x38, 0x1f, 0x87, 0x00, 0x0e, 0x03, 0x80, 0x7d, 0xbc, 0x00, 0x00, 0x00,
  0x00, 0x00, 0x00, 0x00, 0x38, 0x03, 0xc7, 0x00, 0x0e, 0x03, 0x80, 0x1d, 0xb8, 0x00, 0x00, 0x00,
  0x00, 0x00, 0x00, 0x00, 0x38, 0x01, 0xc7, 0x00, 0x0e, 0x03, 0x80, 0x1e, 0x78, 0x00, 0x00, 0x00,
  0x00, 0x00, 0x00, 0x00, 0x38, 0x00, 0xe7, 0x00, 0x0e, 0x03, 0x80, 0x0e, 0xf0, 0x00, 0x00, 0x00,
  0x00, 0x00, 0x00, 0x00, 0x38, 0x40, 0xe7, 0x10, 0x0e, 0x03, 0x80, 0x0f, 0xf0, 0x00, 0x00, 0x00,
  0x00, 0x00, 0x00, 0x00, 0x39, 0xc0, 0xf7, 0x30, 0x0e, 0x03, 0x80, 0x0f, 0xc0, 0x00, 0x00, 0x00,
  0x00, 0x00, 0x00, 0x08, 0x3b, 0x40, 0xf7, 0x50, 0x0e, 0x03, 0x80, 0x1e, 0x08, 0x00, 0x00, 0x00,
  0x00, 0x00, 0x00, 0x0e, 0x3a, 0xc0, 0xf7, 0xb0, 0x0e, 0x03, 0x80, 0x3c, 0x18, 0x00, 0x00, 0x00,
  0x00, 0x00, 0x00, 0x0b, 0x3e, 0xc0, 0xe7, 0xf0, 0x0e, 0x03, 0xff, 0xfe, 0x78, 0x00, 0x00, 0x00,
  0x00, 0x00, 0x00, 0x0d, 0xbd, 0xc0, 0xe7, 0xe0, 0x0e, 0x03, 0xff, 0xff, 0x50, 0x00, 0x00, 0x00,
  0x00, 0x00, 0x00, 0x0d, 0xbf, 0x81, 0xe7, 0x80, 0x0e, 0x03, 0xff, 0xff, 0xb0, 0x00, 0x00, 0x00,
  0x00, 0x00, 0x00, 0x06, 0xbf, 0x01, 0xc7, 0x00, 0x0e, 0x03, 0x80, 0x0f, 0xe0, 0x00, 0x00, 0x00,
  0x00, 0x00, 0x00, 0x07, 0xfc, 0x07, 0x87, 0x00, 0x0f, 0xf3, 0x80, 0x07, 0x80, 0x00, 0x00, 0x00,
  0x00, 0x00, 0x00, 0x03, 0xff, 0xff, 0x07, 0x00, 0x0e, 0x0b, 0x80, 0x03, 0x80, 0x00, 0x00, 0x00,
  0x00, 0x00, 0x00, 0x00, 0x7f, 0xfe, 0x07, 0x00, 0x0f, 0xe7, 0x80, 0x03, 0x80, 0x00, 0x00, 0x00,
  0x00, 0x00, 0x00, 0x00, 0x3f, 0xf8, 0x07, 0x00, 0x0e, 0x13, 0x80, 0x03, 0x80, 0x00, 0x00, 0x00,
  0x00, 0x00, 0x00, 0x00, 0x38, 0x00, 0x07, 0xff, 0xfe, 0x0b, 0x80, 0x03, 0x80, 0x00, 0x00, 0x00,
  0x00, 0x00, 0x00, 0x00, 0x38, 0x00, 0x07, 0x00, 0x0e, 0x07, 0x80, 0x03, 0x80, 0x00, 0x00, 0x00,
  0x00, 0x00, 0x00, 0x00, 0x38, 0x00, 0x03, 0x80, 0x1c, 0x03, 0x80, 0x07, 0x80, 0x00, 0x00, 0x00,
  0x00, 0x00, 0x00, 0x00, 0x38, 0x00, 0x03, 0xc0, 0x3c, 0x03, 0x80, 0x0f, 0x00, 0x00, 0x00, 0x00,
  0x00, 0x00, 0x00, 0x03, 0x38, 0x00, 0x01, 0xf0, 0xf8, 0x33, 0x80, 0x3e, 0x00, 0x00, 0x00, 0x00,
  0x00, 0x00, 0x00, 0x04, 0xff, 0x00, 0x00, 0xff, 0xf0, 0x4f, 0xff, 0xfe, 0x00, 0x00, 0x00, 0x00,
  0x00, 0x00, 0x00, 0x04, 0xff, 0x00, 0x00, 0x7f, 0xe0, 0x4f, 0xff, 0xfb, 0x00, 0x00, 0x00, 0x00,
  0x00, 0x00, 0x00, 0x07, 0xff, 0x00, 0x00, 0x0f, 0x00, 0x3f, 0xff, 0xc1, 0x80, 0x00, 0x00, 0x00,
  0x00, 0x00, 0x00, 0x00, 0x20, 0x00, 0x00, 0xc4, 0x00, 0x00, 0x08, 0x00, 0xc0, 0x00, 0x00, 0x00,
  0x00, 0x00, 0x00, 0x00, 0x20, 0x00, 0x01, 0x44, 0x00, 0x00, 0x08, 0x00, 0x60, 0x00, 0x00, 0x00,
  0x00, 0x00, 0x00, 0x03, 0xff, 0xe3, 0xfe, 0xcf, 0xff, 0x0f, 0xfc, 0x3f, 0xf8, 0x00, 0x00, 0x00,
  0x00, 0x00, 0x00, 0x04, 0xff, 0xe4, 0xfd, 0xd3, 0xff, 0x0f, 0xe4, 0x3f, 0xe4, 0x00, 0x00, 0x00,
  0x00, 0x00, 0x00, 0x04, 0xff, 0xe4, 0xff, 0xd3, 0xff, 0x0f, 0xe4, 0x3f, 0xe4, 0x00, 0x00, 0x00,
  0x00, 0x00, 0x00, 0x03, 0x1d, 0x43, 0x1f, 0x8c, 0x39, 0x03, 0xdc, 0x07, 0x98, 0x00, 0x00, 0x00,
  0x00, 0x00, 0x00, 0x00, 0x1d, 0x42, 0x1f, 0x00, 0x39, 0x01, 0xc8, 0x07, 0x10, 0x00, 0x00, 0x00,
  0x00, 0x00, 0x00, 0x00, 0x1d, 0x42, 0x1f, 0x80, 0x39, 0x01, 0xc8, 0x07, 0x10, 0x00, 0x00, 0x00,
  0x00, 0x00, 0x00, 0x00, 0x1d, 0x42, 0x1f, 0x80, 0x39, 0x19, 0xef, 0xff, 0x10, 0x00, 0x00, 0x00,
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
};

// You will need to change the ESP32 partition scheme to fit the Bluetooth Libraries!
// Tools > Partition Scheme > Minimal SPIFFS (Large APPS with OTA)
// This gives you more program space - choose No OTA for even more space but this removes Over The Air updates feature.
//#define BLE
#ifdef BLE
  #include <BLEDevice.h>
  #include <BLEServer.h>
  #include <BLEUtils.h>
  #include <BLE2902.h>

  BLECharacteristic *characteristicTX;
  bool deviceConnected = false;
  // See the following for generating UUIDs:
  // https://www.uuidgenerator.net/
  #define SERVICE_UUID           "ab0828b1-198e-4351-b779-901fa0e0371e" // UART service UUID
  #define CHARACTERISTIC_UUID_RX "4ac8a682-9736-4e5d-932b-e9b31405049c"
  #define CHARACTERISTIC_UUID_TX "0972EF8C-7613-4075-AD52-756F33D4DA91"
#endif

// #define V4 // V0.4 VentMon with the new 128x64 OLED Screen
//#define DEBUG_1

// Many of the VentMon T0.5 devices have the gage pressure sensor
// installed incorrectly, which requires us to negate the pressure.
bool NEGATE_PRESSURE = true;

/* In theory, some of these components are optional, so we track what we find... */
bool found_display = false;



/*  These are all the supported sensor. Each sensor has a "period".
 *  The Period is the number of milliseconds to wait before the next event for that sensor.
 *  This is complicated somewhat by multi-sensor boards.
 */
bool found_bme280[2] = { false, false};
bool found_bme680[2] = { false, false};
bool found_O2 = false;
bool found_flow = false;
bool found_diff_press = false;

unsigned PERIOD_O2 = 4000;
unsigned PERIOD_FLOW = 0;
unsigned PERIOD_I_DPRES = 0; // differential pressure period
unsigned PERIOD_I_ADPRES = 1000; // differential pressure produced by absolute difference, if avaiable
unsigned PERIOD_I_PRES = 10000; // Absolute pressure in the inspiratory limb
unsigned PERIOD_I_TEMP = 10000; // Temperature in the insipiratory limb
unsigned PERIOD_I_H2O = 10000; // Relative humidity in the inspiratory limb
unsigned PERIOD_I_GAS = 20000; // Gas (Ohms) (only avaialable on BME680)
unsigned PERIOD_B_PRES = 10000; // Absolute pressure in the inspiratory limb
unsigned PERIOD_B_TEMP = 10000; // Temperature in the insipiratory limb
unsigned PERIOD_B_H2O = 10000; // Relative humidity in the inspiratory limb
unsigned PERIOD_B_GAS = 20000; // Gas (Ohms) (only avaialable on BME680)

/* These are the times of the last output */
unsigned PERIOD_O2_ms = 0;
unsigned PERIOD_FLOW_ms = 0;
unsigned PERIOD_I_DPRES_ms = 0;
unsigned PERIOD_I_ADPRES_ms = 0;
unsigned PERIOD_BDPRES_ms = 0;
unsigned PERIOD_I_PRES_ms = 0;
unsigned PERIOD_I_TEMP_ms = 0;
unsigned PERIOD_I_H2O_ms = 0;
unsigned PERIOD_I_GAS_ms = 0;
unsigned PERIOD_B_PRES_ms = 0;
unsigned PERIOD_B_TEMP_ms = 0;
unsigned PERIOD_B_H2O_ms = 0;
unsigned PERIOD_B_GAS_ms = 0;

/* DISPLAY ********************************************/
#ifdef V5
Adafruit_SH1107 display = Adafruit_SH1107(64, 128, &Wire);
//#define BUTTON_A 15
//#define BUTTON_B 32
#define BUTTON_C 14


//Adafruit_SSD1306 display = Adafruit_SSD1306(128, 64, &Wire); // SH1107 
#define DISPLAY_I2C 0x3D
#elif V4
Adafruit_SSD1306 display = Adafruit_SSD1306(128, 64, &Wire);
#define DISPLAY_I2C 0x3D
#else
Adafruit_SSD1306 display = Adafruit_SSD1306(128, 32, &Wire);
#define DISPLAY_I2C 0x3C
#endif


unsigned long buttonCpress_ms = 0;

#define BUTTON_A 13
#define BUTTON_B 12
//#define BUTTON_C 14
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
void loop() {
  if (need_to_configure) {
    configure();
  }
  if (Serial.available() > 0) {
      // read the incoming byte:
      String str = Serial.readStringUntil('\n');
      if (str.startsWith("c")) {
        Serial.println("Configuring!");
        configure();
      }
  }

  unsigned long ms = millis();

    if (found_display) {
    if (!digitalRead(BUTTON_A)) {
      Serial.println("A BUTTON");
    }
  
    if (!digitalRead(BUTTON_B)) {
      Serial.println("B BUTTON");
    }
  
    if (!digitalRead(BUTTON_C)) {
      Serial.println("C BUTTON");
    }

    display.clearDisplay();
    display.setCursor(0, 0);
    displayFromMS(ms);

    display.display();
    }
  /*


  if (digitalRead(BUTTON_A)) {
      Serial.println("A BUTTON");
      buttonC();
  }

  if (digitalRead(BUTTON_B)) {
    Serial.println("B BUTTON");
    buttonB();
    //Serial.println("B BUTTON PROCESS DONE");
  }

  if (found_display) {
    // experimental OLED test code
    if (digitalRead(BUTTON_A)) {
      Serial.println("A BUTTON");
      //buttonA();
    }

    if (digitalRead(BUTTON_B)) {
      Serial.println("B BUTTON");
      //buttonB();
      //Serial.println("B BUTTON PROCESS DONE");
    }
    else if (!digitalRead(BUTTON_C)) {
      unsigned long m = millis();
      if (m > (buttonCpress_ms + 1000)) {
        buttonCpress_ms = m;
        //Serial.println("B BUTTON");
        buttonC();
      }
    } else {
      display.clearDisplay();
      display.setCursor(0, 0);
      displayFromMS(ms);
    //}

    display.display();
  }
  */


  for (int i = 0; i < AMB_WINDOW_SIZE; i++) {
    smooth_ambient += ambient_window[i];
  }
  smooth_ambient = (signed long) (smooth_ambient / AMB_WINDOW_SIZE);


  // Differential, from absolute pressures
  ms = millis();
  if (found_bme(AMBIENT_PRESSURE_SENSOR) && found_bme(INSPIRATORY_PRESSURE_SENSOR)
    && ((PERIOD_I_ADPRES_ms + PERIOD_I_ADPRES)  < ms )) {
    output_I_ADPRES();
    PERIOD_I_ADPRES_ms = ms;
  }

  // Ambient pressures
  ms = millis();
  if (found_bme(AMBIENT_PRESSURE_SENSOR) && ((PERIOD_B_PRES_ms + PERIOD_B_PRES)  < ms )) {
    output_B_PRES();
    PERIOD_B_PRES_ms = ms;
  }

  // Inspiration pressures
  ms = millis();
  if (found_bme(INSPIRATORY_PRESSURE_SENSOR) && ((PERIOD_I_PRES_ms + PERIOD_I_PRES)  < ms )) {
    output_I_PRES();
    PERIOD_I_PRES_ms = ms;
  }

  // Differential Pressure
  ms = millis();
  if (found_diff_press && ((PERIOD_I_DPRES_ms + PERIOD_I_DPRES)  < ms )) {
    output_I_DPRES();
    PERIOD_I_DPRES_ms = ms;
  }

  // FiO2
  ms = millis();
  if (found_O2 && ((PERIOD_O2_ms + PERIOD_O2)  < ms )) {
    output_O2();
    PERIOD_O2_ms = ms;
  }

  // FLOW
  ms = millis();
  if (found_flow && ((PERIOD_FLOW_ms + PERIOD_FLOW)  < ms )) {
    output_flow();
    PERIOD_FLOW_ms = ms;
  }

  // Measures other than flow and pressure...
  // Some of these require a preparatory call to "peform_read", complicating the logic a bit..
  // after we perform that, we can output the ones that are demanded by the period...
  ms = millis();
  if (found_bme(INSPIRATORY_PRESSURE_SENSOR)) {
    if (((PERIOD_I_TEMP_ms + PERIOD_I_TEMP)  < ms ) ||
        ((PERIOD_I_H2O_ms + PERIOD_I_H2O)  < ms ) ||
        ((PERIOD_I_GAS_ms + PERIOD_I_GAS)  < ms ))
       {
     perform_read(INSPIRATORY_PRESSURE_SENSOR);
    }
    if ((PERIOD_I_TEMP_ms + PERIOD_I_TEMP)  < ms ) {
        output_temp(INSPIRATORY_PRESSURE_SENSOR);
        PERIOD_I_TEMP_ms = ms;
    }
    if ((PERIOD_I_H2O_ms + PERIOD_I_H2O)  < ms ) {
        output_h2o(INSPIRATORY_PRESSURE_SENSOR);
        PERIOD_I_H2O_ms = ms;
    }
    if ((PERIOD_I_GAS_ms + PERIOD_I_GAS)  < ms ) {
        output_gas(INSPIRATORY_PRESSURE_SENSOR);
        PERIOD_I_GAS_ms = ms;
    }
  }
  if (found_bme(AMBIENT_PRESSURE_SENSOR)) {
    if (((PERIOD_B_TEMP_ms + PERIOD_B_TEMP)  < ms ) ||
        ((PERIOD_B_H2O_ms + PERIOD_B_H2O)  < ms ) ||
        ((PERIOD_B_GAS_ms + PERIOD_B_GAS)  < ms ))
       {
     perform_read(AMBIENT_PRESSURE_SENSOR);
       }
    if ((PERIOD_B_TEMP_ms + PERIOD_B_TEMP)  < ms ) {
        output_temp(AMBIENT_PRESSURE_SENSOR);
        PERIOD_B_TEMP_ms = ms;
    }
    if ((PERIOD_B_H2O_ms + PERIOD_B_H2O)  < ms ) {
        output_h2o(AMBIENT_PRESSURE_SENSOR);
        PERIOD_B_H2O_ms = ms;
    }
    if ((PERIOD_B_GAS_ms + PERIOD_B_GAS)  < ms ) {
        output_gas(AMBIENT_PRESSURE_SENSOR);
        PERIOD_B_GAS_ms = ms;
    }
  }

  /* BLUETOOTH */
  #ifdef BLE
  if (deviceConnected) {
      characteristicTX->setValue("Hello!\n");
      characteristicTX->notify();
  }
  #endif
}


void setup() {
  // 32 for the ssid, 120 for the pasword, 1 for ethernet, 1 for wifi
  EEPROM.begin(32+120+1+1);

  Serial.begin(BAUD_RATE);
  Wire.begin();

    /* BLUETOOTH */
  #ifdef BLE
  // Create the BLE Device
  BLEDevice::init("VentMon");
  // Create the BLE Server
  BLEServer *server = BLEDevice::createServer();
  server->setCallbacks(new ServerCallbacks());
  // Create the BLE Service
  BLEService *service = server->createService(SERVICE_UUID);
  // Create a BLE Characteristic
  characteristicTX = service->createCharacteristic(
                      CHARACTERISTIC_UUID_TX,
                      BLECharacteristic::PROPERTY_NOTIFY
                    );

  characteristicTX->addDescriptor(new BLE2902());

  // Create a BLE Characteristic
  BLECharacteristic *characteristic = service->createCharacteristic(
                                         CHARACTERISTIC_UUID_RX,
                                         BLECharacteristic::PROPERTY_WRITE
                                       );

  characteristic->setCallbacks(new CharacteristicCallbacks());
  // Start the service
  service->start();
  // Start advertising
  server->getAdvertising()->start();

  //Serial.println("Waiting a client connection to notify...");
  #endif

  Serial.println("----------------- VENTMON STARTING -----------------");

  flowSensor.begin();

  setupOLED();

  while (!Serial);

  displayPrintScroll("Checking sensors...");

  seekBME680(INSPIRATORY_PRESSURE_SENSOR);
  seekBME680(AMBIENT_PRESSURE_SENSOR);

    if (!bme280[0].begin(addr[0], &Wire)) {
      #ifdef DEBUG_1
      report_bme280_not_found(bme280[0].sensorID());
      #endif
    } else {
      found_bme280[0] = true;
    }

    if (!bme280[1].begin(addr[1], &Wire)) {
      #ifdef DEBUG_1
      report_bme280_not_found(bme280[1].sensorID());
      #endif
    } else {
      found_bme280[1] = true;
    }

  signed long v = readPressureOnly(AMBIENT_PRESSURE_SENSOR);
  init_ambient(v);

  initializeOxygenSensor();

  Serial.print("Ambient Pressure Sensor     : ");
  if (found_bme280[AMBIENT_PRESSURE_SENSOR]) {
    Serial.println("BME280");
  } else if (found_bme680[AMBIENT_PRESSURE_SENSOR]) {
    Serial.println("BME680");
  } else {
    Serial.println("NO");
  }
  Serial.print("Inspiratory Pressure Sensor : ");
  if (found_bme280[INSPIRATORY_PRESSURE_SENSOR]) {
    Serial.println("BME280");
  } else if (found_bme680[INSPIRATORY_PRESSURE_SENSOR]) {
    Serial.println("BME680");
  } else {
    Serial.println("NO");
  }

  Serial.print("Found O2 Sensor: ");
  Serial.println(found_O2 ? "YES" : "NO");

  float raw_flow = flowSensor.readFlow();
  // Let's wait and re-read to see if it is present...
  delay(50);
  raw_flow = flowSensor.readFlow();
  Serial.print("Found Flow Sensor: ");
  found_flow = !flowSensor.checkRange(raw_flow);
  Serial.println(found_flow ? "YES" : "NO");

  // Differential Pressure Sensor
  Serial.print("Found Differential Pressure Sensor: ");
  // Differential Pressure Sensor: err diagnostic fault 11
  found_diff_press = (readHSCPressure() != LONG_MIN);
  Serial.println(found_diff_press ? "YES" : "NO");
  Serial.println("----------------- SENSOR TEST COMPLETE -----------------");

  displayPrintScroll("Sensor test complete!");

  // TODO: Comment out for graphics testing...
  int ethernetEnabled = getEthernetEnabledFromEEPROM();
  if (ethernetEnabled) {
    Serial.println("Ethernet currently: ENABLED");
    displayPrintScroll("Ethernet ENABLED");
    ethernet_setup();
  } else {
    Serial.println("Ethernet currently: DISABLED");
    displayPrintScroll("Ethernet ENABLED");
  }
  int wifiEnabled = getWiFiEnabledFromEEPROM();
  if (wifiEnabled) {
    Serial.println("WiFi currently: ENABLED");
    displayPrintScroll("WiFi ENABLED");
    wifi_setup();
  } else {
    Serial.println("WiFi currently DISABLED");
    displayPrintScroll("WiFi DISABLED");
  }
  udpclient = (UDP *) (eudpclient_good ? (UDP *) &eudpclient : (wudpclient_good ? (UDP *) &wudpclient : NULL));

  printCurrentCredentials();
  need_to_configure = true;


}

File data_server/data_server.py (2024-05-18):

#
# Public Invention's Ventmon-Ventilator-Inline-Test-Monitor Project is an attempt
# to build a "test fixture" capable of running a 48-hour test on any ventilator
# design and collecting data on many important parameters. We hope to create a
# "gold standard" test that all DIY teams can work to; but this project will
# proceed in parallel with that. The idea is to make a standalone inline device
# plugged into the airway. It serves a dual purpose as a monitor/alarm when used
# on an actual patient, and a test device for testing prototype ventilators. It
# also allows for burnin. Copyright (C) 2021 Robert L. Read, Lauria Clarke,
# Ben Coombs, Darío Hereñú, and Geoff Mulligan.
#
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

#!/usr/bin/python
import time
import struct
import serial
# ser = serial.Serial('/dev/cu.usbmodem141401',57600,timeout=None)  # open serial port
ser = serial.Serial('/dev/cu.SLAB_USBtoUART',115200,timeout=None)
import time
import math
from time import sleep
from flask import Flask
from flask import request
import sys
from flask_cors import CORS
import datetime

import collections
import itertools
import threading
import json
import jsonpickle

import socket
import sys
import os
import traceback

# This makes it a rather short pattern.
# Up to 10,000 samples seems to work fine.
# Managing the continuity of time in the samples can be tedious, however.
SAMPLES = 3000
my_deque = collections.deque(maxlen=SAMPLES)

app = Flask(__name__)

CORS(app)

DATA_LAKE_HOST = "ventmon.coslabs.com"
DATA_LAKE_PORT = 6110
DATA_LAKE_SAMPLES_TO_SEND = 0
NUM_SENT_TO_DATA_LAKE = 0

NUMREAD = 0;
REPORT_MODULUS = 500;

RUN_LIMIT = 0;
RUN_CNT = 0;


class Measurement:
  def __init__(self, measurementType, deviceType, deviceLocation, measurementTime, measurementValue):
      x = "local"
      self.m                = "M"
      self.measurementType  = measurementType
      self.deviceType       = deviceType
      self.deviceLocation   = deviceLocation
      self.measurementTime  = measurementTime
      self.measurementValue = measurementValue
  def asBytes(self):
      self.x = 4
      b = bytearray(12)
      b[0] = ord(self.m)
      b[1] = ord(self.measurementType)
      b[2] = ord(self.deviceType)
      x = self.measurementTime.to_bytes(4, 'big')
      b[4] = x[0];
      b[5] = x[1];
      b[6] = x[2];
      b[7] = x[3];
      # because the measurementValue can be signed and Python tries
      # to abstract away the sign bit, we do this from:
      # https://stackoverflow.com/questions/20766813/how-to-convert-signed-to-unsigned-integer-in-python
#      v = self.measurementValue.to_bytes(4, 'big')
      packed = struct.pack('!l', self.measurementValue)  # Packing a long number.
#      print("packed = " + str(packed)+"\n")
      unpacked = struct.unpack('!l', packed)[0]  # Unpacking a packed long number to unsigned long

#      v = struct.pack('>i', self.measurementValue)
#      v = unpacked.to_bytes(4, 'big')
      struct.pack_into('>i',b,8,self.measurementValue)
#      b[8] = v[0];
#      b[9] = v[1];
#      b[10] = v[2];
#      b[11] = v[3];
#      b[3] = self.deviceLocation.to_bytes(1,'big')
      b[3] = ord(chr(self.deviceLocation))
      return b


class MeasurementEncoder(json.JSONEncoder):
    def default(self, m):
        if isinstance(m, Measurement):
            return {
                "event": "M",
                "type": m.measurementType,
                "loc": m.deviceType,
                "num": m.deviceLocation,
                "ms": m.measurementTime,
                "val": m.measurementValue,
            }
        return super(RoundTripEncoder, self).default(m)
# print json.dumps(data, cls=RoundTripEncoder, indent=2)


def terminate_with_newline(mbytes):
      b = bytearray(len(mbytes)+1)
      for i in range(len(mbytes)):
        b[i] = mbytes[i]
      b[12] = ord('\n')
      return b;

def read_from_port():
  global NUMREAD
  global my_deque
  global NUM_SENT_TO_DATA_LAKE
  global DATA_LAKE_SAMPLES_TO_SEND
  global sock
  global RUN_CNT
  global RUN_LINIT
  while True :
    if ((RUN_LIMIT > 0) and RUN_CNT >= RUN_LIMIT):
      os._exit(os.EX_OK)
    RUN_CNT = RUN_CNT + 1
    if(ser.inWaiting() <= 50):
      pass
    line = ser.readline()   # read a '\n' terminated line
    NUMREAD = NUMREAD + 1;
    if (NUMREAD % REPORT_MODULUS) == 0:
      print(str(len(my_deque)) + " ready!\n",sys.stderr)
      print(str(line) + "\n",sys.stderr)

      NUMREAD = 0;
    # performing a try except here really seems to
    # make the coding of characters all messed up,
    # I don't really know why, it is like we get off by one character
    try:
      thisline = line.decode("utf-8")+"\n"
      # For bizarre reason I'm unable to figure out,
      # printing this here is NECESSARY!!!
#      print(thisline)
      try:
        m = json.loads(thisline)

        if m["event"] == "M":
          # Warning! This is just a test
          # v = abs(m["val"])
          v = m["val"]
          minst = Measurement(m["type"], m["loc"], int(m["num"]),
                              m["ms"], v)
          my_deque.append(minst)
          if  ((DATA_LAKE_SAMPLES_TO_SEND > 0) and (NUM_SENT_TO_DATA_LAKE < DATA_LAKE_SAMPLES_TO_SEND)):
            print(f'sending {NUM_SENT_TO_DATA_LAKE} {DATA_LAKE_SAMPLES_TO_SEND}')
            try:
              # Send data
              mbytes = minst.asBytes()
              # now pack with a newline!!
              bytes = terminate_with_newline(mbytes)
              print('sending "%s"' % str(bytes))

              return_value = sock.sendall(bytes)

              NUM_SENT_TO_DATA_LAKE = NUM_SENT_TO_DATA_LAKE+1
              if NUM_SENT_TO_DATA_LAKE >= DATA_LAKE_SAMPLES_TO_SEND:
                sock.close()
                os._exit(os.EX_OK)
            except OverflowError:
              print("Overflow error:", sys.exc_info()[0])
              traceback.print_exc(file=sys.stdout)
              os._exit(os.EX_OK)
            except BrokenPipeError:
              traceback.print_exc(file=sys.stdout)
              os._exit(os.EX_OK)
            except:
              traceback.print_exc(file=sys.stdout)
              print("Unexpected sending error:", sys.exc_info()[0])
      except TypeError as err:
        print("Type error: {0}".format(err),sys.stderr)
      except:
        print("Unexpected error:", sys.exc_info()[0],sys.stderr)
        traceback.print_exc(file=sys.stdout)
    except(UnicodeDecodeError):
      print("ERRRRROR\n",sys.stderr)

thread = threading.Thread(target=read_from_port)
thread.start()
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

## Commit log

2020-03-27 adding image and (very rough) arduino sketch
2020-03-27 adding spreadsheets of ValidationTests
    [Validation Tests.ods, Validation Tests.xlsx]
2020-03-27 some progress sampling flow meter and pressue sensors
2020-03-29 adding a breath trace, rob breathing pretty evenly
2020-03-29 changed python to maintain a deque which is last 2000 samples of the system
2020-03-31 adding read of mprls sensor
2020-03-31 addint new breath trace, this one with pressure data; format is bad, I will try to fix.
2020-04-02 calibrate sensor with bad approach
2020-04-02 now have pressure plot working
2020-04-09 flow sensor broken, but progress elsewhere
    [data_server.py]
2020-04-14 significant progress making the Python data server read from the serial port and write to our data lake correctly.
    [data_server.py]
2020-04-15 adding refactored arduino sketch with dummy functions
2020-04-15 latest updates, emergency fix to syntax error in data_server.py
    [data_server.py]
2020-04-15 accidentaly remove threading library
2020-04-16 adding better data trace
2020-04-16 adding threading library
2020-04-16 created tiny library for SFM3X00 sensors and added UDP code
2020-04-16 Created Event plot as distinct from pressure/flow plot
2020-04-18 updated flow sensor library
2020-04-20 integrating laurias library and other fixes to data_server
    [data_server.py]
2020-04-21 initial attemp to merge udp and sensor reading
2020-04-22 improvements to the the rendering of events, fixed a bug, slowed down the full reports from the board program
2020-04-24 recent crummy attempts to get python server to be threadsafe and robust, not really working
2020-04-28 updated FlowAndTwoPressures to use new SFM3X00 library
2020-04-29 adding OUT OF RANGE event to handle flow sensor limits
2020-05-04 adding Sample Screen Shot
2020-05-06 Increase number of samples to better match the 1Million Vents team...
2020-05-12 created address macros for pressure sensors
2020-05-15 added comments about pressure sensor addresses
2020-05-30 handling flow
2020-07-30 added pcb and b,e bard files
    [VentMon T0.3 BOM.csv, bme280_hat.scad, ventmon_t0.3.brd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]
2020-08-13 attempt to put a 1/4 inch barb on the bme280 hat
    [BarbGenerator-v3.scad, bme280_hat_w_barb.stl]
2020-08-14 fixing some bugs
    [bme280_hat.scad, bme280_hat_w_barb.stl]
2020-08-21 fixed 5V to flow sensor
    [ventmon_t0.3.brd, ventmon_t0.3.sch]
2020-08-21 adding new design to put both pressure and inspiratory air into port with one cable, with patch cable to differential
    [bme280_hat_two_port.stl]
2020-08-24 adding a template for drilling the T0.3 version
2020-08-27 adding pressure coupling
    [BarbGenerator-v3.scad, PressureCoupling.scad, PressureCoupling.stl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]
2020-10-03 Fixed Arduino denomination on line 40
2020-10-10 adding some tweaks to this model
    [bme280_hat.scad]
2020-10-22 working on assembly instructions
2020-10-30 adding ability to configure Wifi and Ethernet on and off and improvements in pressure display
2020-11-03 Fixed HSC not found bug
    [VentMonFirmware.ino]
2020-11-03 Improved UX/UI. OLED splash screen, scrolling startup status text, skip ethernet if no cable, added second screen with pressure/flow/o2 readout and enabled sreen flipping.
    [VentMonFirmware.ino]
2020-11-06 assembly edits
2020-12-03 paper and drill template edits
2020-12-09 improving drill template
2021-04-01 Added T0.4 STL files for 3D printing.
    [BME Hat.stl, VentMon Bottom V0.48.stl, VentMon Top V0.48.stl]
2021-04-01 T0.4 electronics
    [VentMonSwitches.brd, VentMonSwitches.sch, ventmon_t0.42.brd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]
2021-04-05 Added T0.4 BOM
    [VentMon T0.4 BOM.csv]
2021-05-23 instructions to setup with raspberry pi
2021-06-06 Adding mockup of mounting bracket
2021-10-17 VentMon T0.5 mini PCB design
    [ventmon_t0.5.brd, ventmon_t0.5.sch, ventmon_t0.5b.brd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]
2021-12-04 changing order of includes to avoid a symbol collision revealed by the recent upgrade of the Arduino IDE to 1.18.16
    [VentMonFirmware.ino]
2021-12-08 T0.5 Feather PCB
    [ventmon_t0.5e.brd, ventmon_t0.5e.sch]
2022-05-31 Add T0.5 case made in OpenSCAD
    [VentMon0.5.scad]
2023-04-26 VentMon T0.5 STLs
    [Buttons_T0.5.54.stl, Cap_T0.5.66.stl, Case_T0.5.48.stl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]
2023-04-27 VentMon T0.5 Eagle files.
    [ventmon_t0.5i.brd, ventmon_t0.5i.sch]
2026-07-23 negated pressure to correct for VentMon
    [VentMonFirmware.ino]

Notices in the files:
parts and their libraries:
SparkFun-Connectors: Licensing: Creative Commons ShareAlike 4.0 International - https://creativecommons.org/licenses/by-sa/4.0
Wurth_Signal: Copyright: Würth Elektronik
